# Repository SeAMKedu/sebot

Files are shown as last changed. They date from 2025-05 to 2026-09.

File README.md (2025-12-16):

# SeBot


SeBot-robotin ROS2 ohjelmointiohjeet 28.5.2025 OpenUGV-hankkeen ROS2 mobiilirobotti-työpajaan.

Varsinaiset ohjeet on kirjoitettu markdown-tiedostoihin. Niiden mukaiset valmiit koodit (ROS2, Arduino ja WWW) löydät repositorion code-kansiosta.

SeBotia varten on olemassa Rasberry Pi 5:lle sopiva image-tiedosto, jonka voi kirjoittaa MicroSD-muistikortille. Image sisältää valmiin ROS2 ympäristön ja muut tämän harjoituksen kannalta tarpeelliset muut tiedostot ja ohjelmat. Tiedosto on talletettu OpenUGV-hankkeen Teams-ryhmään (vaatii käyttöoikeuden SeAMK:lta). Mikäli sinulla ei ole käytössä tätä image-tiedostoa tai haluat tehdä harjoituksen jollain muulla koneella, voit hyvin asentaa ROS2-ympäristön itse ``apt install``-komennolla Ubuntun pakettijakelun kautta. Ohje tähän löytyy Materiaali 0:sta.

Jos haluat tulostaa oman SeBot-pohjan, STP-malli ja PDF-mittakuva löytyy SeBot-kansiosta. Huomaa kuitenkin, että tämän harjoituksen kannalta pohjalevyn muoto on hyvin vapaa ja robotin voi rakentaa vaikkapa riittävän tukevaan muovirasiaan.

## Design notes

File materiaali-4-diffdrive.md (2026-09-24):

### Differential drive

Differential Drive on kahdella pyörällä toimiva robotiikan liikkumismekanismi, jossa robottia ohjataan säätämällä pyörien pyörimisnopeuksia. Toinen pyörä voi pyöriä nopeammin, hitaammin tai jopa vastakkaiseen suuntaan kuin toinen, mikä mahdollistaa robotin suunnanmuutokset ja paikoillaan kääntymisen.

Differential Drive on yksinkertainen ja tehokas mekanismi, joka ohjaa robotin liikettä kahden pyörän nopeus- ja suuntaerojen avulla. Se on suosittu ratkaisu erityisesti ROS-järjestelmässä, jossa ``cmd_vel``-topicin avulla määritellään robotin lineaarinen- ja kulmanopeus käyttämällä viestityyppiä ``geometry_msgs/msg/Twist``. Tämä viestityyppi on standardoitu liikkuville roboteille, erityisesti differential drive -järjestelmiä varten.

``geometry_msgs/msg/Twist`` viestityyppi sisältää kaksi vektorikenttää:

- linear: Kuvaa lineaarista nopeutta (m/s) kaikilla kolmella akselilla (x, y, z).
- angular: Kuvaa kulmanopeutta (rad/s) kaikilla kolmella akselilla (x, y, z).

Differential Drive -roboteille merkittävät komponentit ovat:

- linear.x: Lineaarinen nopeus eteenpäin (positiivinen) tai taaksepäin (negatiivinen).
- angular.z: Kulmanopeus robottia ympäröivän pystyakselin ympäri.

Muut komponentit (linear.y, linear.z, angular.x, ja angular.y) eivät yleensä ole käytössä 2D-ympäristössä.

Kun ``cmd_vel`` -topic hallitsee robotin nopeuksia, ``odom`` -topic tarjoaa tietoa robotin todellisesta sijainnista ja orientaatiosta. Odometry-laskenta julkaisee nämä tiedot ``odom`` -topicissa, mikä mahdollistaa robotin sijainnin seuraamisen reaaliaikaisesti.

### Odometry

``/odom``-topic: Tämä julkaisee tietoa robotin sijainnista ja orientaatiosta suhteessa alkuperäiseen lähtöpisteeseen.

Odometriikan laskenta perustuu tässä tapauksessa pelkästään moottoreiden enkoodereiden tuottamaan tietoon. On tärkeää huomioida, että tämä menetelmä ei ole täysin tarkka, sillä renkaiden ja alustan välinen vuorovaikutus, kuten liukuminen ja kitka, aiheuttaa väistämättä virheitä sijainnin ja liikkeen arvioinnissa. Vaikka tämä laskentamenetelmä ei takaa täydellistä tarkkuutta, se tarjoaa kuitenkin luotettavan perustan robotin sijainnin ja liikkeen seuraamiselle. Koska tässä esimerkissä muita antureita ei ole käytössä, enkooderipohjainen odometriikka on robotin ainoa käytettävissä oleva navigointimenetelmä.

#### Odometry-laskennan toiminta lyhyesti

Odometry-laskenta perustuu robotin pyörien liikkeiden mittaamiseen ja näiden tietojen hyödyntämiseen robotin sijainnin ja orientaation (x, y, θ) määrittämiseksi ajan kuluessa.

- Pyörän liikkuma matka saadaan kun tiedetään pyörän halkaisija ja enkooderin lukema yhdeltä kierrokselta.
- Ero vasemman ja oikean pyörän liikkeessä: Lasketaan vasemman ja oikean pyörän kulkema matka.
Pyörien välinen ero määrittää robotin kääntymisen ja suuntamuutoksen.

**Renkaat**

Renkaan säteellä ja renkaiden välisellä etäisyydellä on merkittävä vaikutus differential drive -robotin liikkeeseen ja ohjaukseen. Ne vaikuttavat suoraan robotin liikeradan, nopeuden ja kulmanopeuden laskentaan.

Oheisessa kuvassa havainnollistetaan, miten renkaiden koko ja niiden välinen etäisyys vaikuttavat robotin liikkeeseen, kun toinen rengas liikkuu tietyllä nopeudella ja toinen pysyy paikallaan. Eli esim. ajetaan moottoria 3 s nopeudella 0,1 m/s.

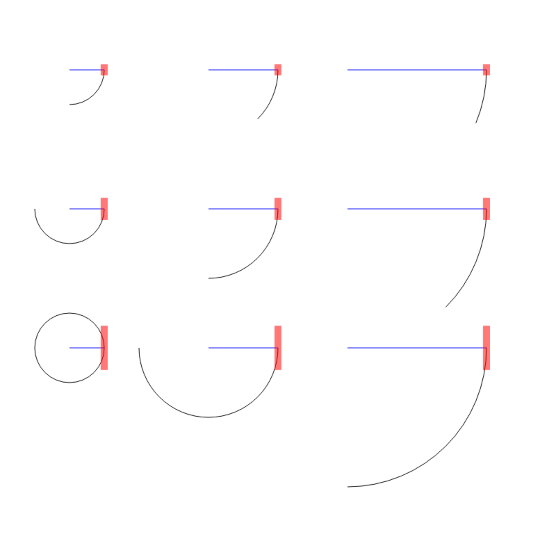
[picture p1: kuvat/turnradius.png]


- Renkaan koko:
	- Pienempi rengas liikkuu lyhyemmän matkan yhdellä kierroksella.
	- Suurempi rengas liikkuu pidemmän matkan samalla kierrosmäärällä.
- Renkaiden välinen etäisyys:
	- Lyhyt etäisyys: Tuottaa jyrkemmän käännöksen, koska kaaren säde pienenee.
	- Pitkä etäisyys: Tekee käännöksestä loivemman, koska suurempi etäisyys vaatii pidemmän matkan kaaren muodostumiseksi.
- Liikuttua matkaa laskettaessa:
	- Kuljettu matka riippuu renkaan koosta ja kääntösäteestä:
		- Pienempi rengas + lyhyt etäisyys → lyhyt matka ja tiukka kaarre.
		- Suurempi rengas + pitkä etäisyys → pitkä matka ja loiva kaarre.

#### Uusi paketti Diffdrive

Luodaan uusi diffdrive-niminen ROS2 paketti ja aletaan työstämään sen sisälle tarvittavat kooditiedostot.

```
cd ~/ros2_ws/src/
ros2 pkg create --build-type ament_python diffdrive
cd ~/ros2_ws/src/diffdrive/diffdrive
```

**Encoder luokka**

Luodaan Pythonilla apuluokka Encoder, joka vastaa enkooderien lukemien hallinnasta ja laskennasta. Useimmissa enkoodereissa lukema nollautuu maksimilukeman jälkeen, jolloin kierrokset alkavat alusta. Tämä luokka pitää tarkasti kirjaa pyörän pyörimiskierroksista, jotta pyörän absoluuttinen sijainti voidaan laskea oikein myös silloin, kun enkooderin lukema ylittyy tai nollautuu.

**~/ros2\_ws/src/diffdrive/diffdrive/encoder.py**

```python
import math

class Encoder():
  encoder_min =  -32768
  encoder_max =  32768
  encoder_range = encoder_max - encoder_min

  encoder_low_wrap = (encoder_range * 0.3) + encoder_min
  encoder_high_wrap = (encoder_range * 0.7) + encoder_min

  def __init__(self, wheel_radius, ticks_per_revolution):

    self.wheel_radius = wheel_radius
    self.ticks_per_revolution = ticks_per_revolution

    # renkaan säde R = 0.1m
    # enkooderin resoluutio E = 1000 tick / kierros

    # renkaan kehä: 2 * pi * R
    # kierrokset per metri = 1m / renkaan kehä
    # ticks per metri = E * (1m / (2 * pi * R)) = E / (2 * pi * R)

    self.ticks_per_meter = self.ticks_per_revolution / (2 * math.pi * self.wheel_radius)

    self.offset = None
    self.encoder = None
    self.prev_encoder = None

    self.position = 0
    self.prev_position = None

    self.multiplier = 0

  def update(self, encoder):
    if self.encoder == None:
      self.offset = encoder
      self.prev_encoder = encoder

    self.encoder = encoder

    # enkoodereissa, jotka mittaavat rotaatiota, on usein rajallinen arvoalue (esim. 0–4095 12-bittisellä enkooderilla).
    # Kun enkooderin arvo "kääntyy ympäri" (esim. 4095 -> 0 tai päinvastoin), tämä logiikka varmistaa, että oikea
    # sijainti säilyy seuraamalla täysiä kierroksia.
    #
    # self.encoder: Nykyinen enkooderin lukema.
    # self.prev_encoder: Edellisen kierroksen enkooderin lukema.
    # self.encoder_low_wrap: Alarajan lähellä oleva kynnysarvo (0 + marginaali)
    # self.encoder_high_wrap: Ylärajan lähellä oleva kynnysarvo (4095 − marginaali)
    # self.multiplier: Laskuri, joka seuraa täysiä kierroksia
    #
    # eli kun edellinen arvo on ylä alueella (esim: 4090-4095) ja nykyinen ala alueella
    # (esim: 0-5) niin silloin absoluuttinen asema lisääntyy ja toiseen suuntaan taas
    # absoluuttinen asema vähenee. Kaikissa muissa tapauksissa ollaan samalla kierroksella

    if (self.encoder < self.encoder_low_wrap) and (self.prev_encoder > self.encoder_high_wrap):
      self.multiplier += 1
    if (self.encoder > self.encoder_high_wrap) and (self.prev_encoder < self.encoder_low_wrap):
      self.multiplier -= 1

    self.position = self.encoder + self.multiplier * self.encoder_range - self.offset

    self.prev_encoder = self.encoder

  def deltam(self):
    if self.prev_position == None:
      self.prev_position = self.position
      return 0
    else:
      d = (self.prev_position - self.position) / self.ticks_per_meter
      self.prev_position = self.position
      return d
```

**Transformaatio**

Transformaatioiden avulla lasketaan robotin sijainti ja orientaatio suhteessa eri koordinaatistoihin. Kun haluamme visualisoida robotin liikkeen RViz-ympäristössä, on tärkeää, että ``odom``- ja ``base_footprint``-kehysten välinen transformaatio on määritetty oikein. Tämä transformaatio yhdistää robotin fyysisen sijainnin (``base_footprint``) sen suhteelliseen sijaintiin odometrian lähtöpisteessä (``odom``).

**RViz Global Options ja Fixed Frame**

Fixed Frame määrittää, minkä koordinaatiston (kehyksen) mukaan kaikki muut kehykset näytetään RViz:ssä.

Jos asetamme Fixed Frame-arvoksi ``base_footprint``:

- Robotin sijainti näytetään suhteessa itseensä, mikä tarkoittaa, ettei mitään liikettä visualisoida, vaikka robotti liikkuisi.
- Tämä johtuu siitä, että base_footprint pysyy aina robotin rungossa ja seuraa sitä.

Jos asetamme Fixed Frame-arvoksi ``odom``:

- Robotin liike visualisoidaan suhteessa ``odom``-kehykseen, joka toimii odometrian lähtöpisteenä.
- Tämä mahdollistaa robotin todellisen liikkeen seuraamisen ruudulla.

**Miten transformaatio vaikuttaa?**

Kun robotti liikkuu, ``odom``-kehys pysyy paikallaan, ja ``base_footprint`` siirtyy sen suhteen. ``odom`` -> ``base_footprint``-transformaatio päivitetään jatkuvasti, ja RViz käyttää tätä tietoa piirtääkseen robotin sijainnin ja orientaation.

Transformaatioiden laskennan ja julkaisun sijainti riippuu robotin järjestelmän arkkitehtuurista sekä vaaditun paikannuksen tarkkuudesta ja mahdollisesta integraatiosta muiden sensoreiden, kuten IMU:n tai LiDAR:n kanssa.

Transformaatiot voidaan toteuttaa suoraan ``odom``-nodessa, jos odometria toimii järjestelmän ainoana sijaintilähteenä. Tämä lähestymistapa on erityisen sopiva yksinkertaisille järjestelmille, joissa ei ole käytössä muita antureita.

Jos kuitenkin käytössä on useita sensoreita, on suositeltavaa käyttää ROS2:n yleisesti käytettyihin paketteihin kuuluvan ´´robot_localizationin´´ EKF (Extended Kalman Filter) -nodea. EKF yhdistää kaikki saatavilla olevat tiedot, kuten enkooderit, IMU:n, LiDAR:n ja GPS:n, ja tuottaa tarkemman arvion robotin sijainnista ja orientaatiosta. Tämä parantaa paikannustarkkuutta ja kompensoi yksittäisten sensorien mahdollisia virheitä.

**Tilanne IMU:n (Inertial Measurement Unit) kanssa:**

IMU tuo tarkempaa dataa robotin todellisesta liikkeestä, mikä auttaa kompensoimaan pyöräluiston aiheuttamaa virhettä.

Kulmanopeus (Yaw-Rate): 
IMU:n gyroskooppi mittaa kulmanopeuksia (esim. kääntymistä z-akselin ympäri).
Jos toinen pyörä luistaa ja pyöräenkooderit antavat väärää kulmanopeustietoa, IMU voi tunnistaa todellisen kulmanopeuden ja korjata suunta- ja sijaintitiedot.
Tämä estää vääristymän kertyessä robotin orientaatioon (yaw).

Kiihtyvyys (Linear Acceleration)
IMU:n kiihtyvyysanturit mittaavat robotin liikkeen kiihtyvyyttä x- ja y-suunnassa.
Pyöräluiston aikana enkooderien arvioima lineaarinen liike voi olla väärä, mutta IMU voi tunnistaa todellisen kiihtyvyyden ja auttaa arvioimaan todellista nopeutta.
Tämä vähentää virhettä robotin paikannuksessa.

**Tilanne LiDAR:n (Light Detection and Ranging) kanssa:**

LiDAR täydentää pyöräenkoodereiden rajoituksia tuottamalla tarkkaa tietoa robotin ympäristöstä.

Etäisyyksien mittaus: LiDAR kartoittaa ympäristöä mittaamalla etäisyyksiä robotin ympärillä oleviin esteisiin ja rakenteisiin.

Staattiset viitteet: LiDAR voi tunnistaa pysyviä ympäristön piirteitä, kuten seinät ja huonekalut, joita käytetään robotin sijainnin määrittämiseen suhteessa ympäristöön.

**Driftin korjaaminen**

Absoluuttista paikkaa tarjoavia paikannusmenetelmiä (kuten kamera- tai LiDAR-pohjainen SLAM, GNSS-paikannus, UWB-paikannus) hyödyntämällä voidaan havaita robotin todellisen liikkeen suhteessa ympäristöön ja korjata pyöräenkooderien kertyneen virheen. 

Esimerkiksi, jos pyöräenkooderit osoittavat, että robotti on siirtynyt tiettyyn kohtaan, mutta LiDAR:n havainto ympäristöstä kertoo muuta, paikannus voidaan korjata yhdistämällä tiedot. ROS2:n tapauksessa yleinen tapa tehdä tällaista korjausta on syöttää eri paikannusmenetelmien tietovirrat ``robot_localization``-paketin EKF-suodattimelle.

Nyt kun enkooderit ovat ainoa sijaintilähteemme, toteutamme transformaatioiden julkaisemisen suoraan ``odom``-nodessa joka on yksinkertainen ja tehokas ratkaisu.

**~/ros2\_ws/src/diffdrive/diffdrive/odom.py**

```python
import rclpy
from rclpy.node import Node

from nav_msgs.msg import Odometry
from tf_transformations import quaternion_from_euler

from geometry_msgs.msg import TransformStamped
from tf2_ros import TransformBroadcaster

from motordriver_msgs.msg import MotordriverMessage

import math

try:
    from .encoder import Encoder
except:
    from encoder import Encoder

class OdomNode(Node):
  def __init__(self):
    super().__init__('odom_node')

    # Lue parametrit
    self.declare_parameter('wheel_radius', 0.1)
    self.declare_parameter('wheel_base', 0.5)
    self.declare_parameter('ticks_per_revolution', 1075)

    # Hae parametrien arvot
    self.wheel_radius = self.get_parameter('wheel_radius').value
    self.wheel_base = self.get_parameter('wheel_base').value
    self.ticks_per_revolution = self.get_parameter('ticks_per_revolution').value

    self.get_logger().info(f'Pyörän säde: {self.wheel_radius}')
    self.get_logger().info(f'Pyörien etäisyys: {self.wheel_base}')
    self.get_logger().info(f'Anturin kierros: {self.ticks_per_revolution}')

    ## Otetaan framelle etuliite parametrinä tai jos parametriä ei syötetä, otetaan se namespace-tiedosta.
    #self.declare_parameter('frame_prefix', '')
    #frame_prefix_param = self.get_parameter('frame_prefix').get_parameter_value().string_value
    #if frame_prefix_param:
    #    self.frame_prefix = frame_prefix_param + '_'
    #else:
    #    ns = self.get_namespace().strip('/')
    #    self.frame_prefix = f'{ns}_' if ns and ns != '' else ''

    #if self.frame_prefix:
    #        self.get_logger().info(f'Käytetään frame-etuliitettä: "{self.frame_prefix}"') 

    self.left_encoder = Encoder(self.wheel_radius, self.ticks_per_revolution)
    self.right_encoder = Encoder(self.wheel_radius, self.ticks_per_revolution)

    self.odom_theta = 0.0
    self.odom_x = 0.0
    self.odom_y = 0.0

    self.motor_subscriber = self.create_subscription(
        MotordriverMessage,
        'motor_data',
        self.update_encoders_callback,
        10
    )

    self.odom_publisher = self.create_publisher(
        Odometry,
        'odom',
        10
    )

    # TransformBroadcaster tarvitsee viitteen pääluokkaan saadakseen tarvittavan kontekstin
    # (noden  asetukset tai muun jaetun datan). Tämä tapahtuu antamalla self parametrina.
    self.tf_broadcaster = TransformBroadcaster(self)

    self.prev_time = self.get_clock().now().nanoseconds

    timer_period = 0.1 # Sekuntia
    self.timer = self.create_timer(timer_period, self.timer_callback)
    self.update = True

  def update_encoders_callback(self, message):
    # Tallennetaan messagessa olevat tiedot, jotta niitä voidaan käsitellä timer_callback:ssa
    self.left_encoder.update(message.encoder1)
    self.right_encoder.update(-message.encoder2)
    self.update = True

  def timer_callback(self):
    if not self.update: return
    self.update = False
    current_time = self.get_clock().now().nanoseconds
    elapsed = (current_time - self.prev_time)/1000000000
    self.prev_time = current_time

    d_left= self.left_encoder.deltam()
    d_right = self.right_encoder.deltam()

    # Kuljettu matka (delta_distance) lasketaan ottamalla vasemman ja oikean pyörän kulkema matka
    # jaettuna kahdella. Robotin liikkuma matka suoraviivaisesti keskilinjan (robottia keskeltä
    # halkova akseli) pitkin.
    # Kulman muutos (delta_theta) lasketaan ottamalla vasemman ja oikean pyörän kulkeman matkan erotus ja
    # jakamalla se pyörien välisellä etäisyydellä
    # Jos pyörät liikkuvat yhtä paljon samaan suuntaan (𝑑_left=𝑑_right -> delta_theta=0), robotti liikkuu
    # suoraan eteen- tai taaksepäin.
    # Jos pyörät liikkuvat yhtä paljon erisuuntiin (𝑑_left=-𝑑_right -> delta_distance=0), robotti pyörii
    # paikallaan
    delta_distance = (d_left + d_right) / 2.0
    delta_theta = (d_left - d_right) / self.wheel_base

    if delta_distance != 0:
      robot_x = math.cos( delta_theta ) * delta_distance
      robot_y = -math.sin( delta_theta ) * delta_distance
      self.odom_x = self.odom_x + ( math.cos( self.odom_theta ) * robot_x - math.sin( self.odom_theta ) * robot_y )
      self.odom_y = self.odom_y + ( math.sin( self.odom_theta ) * robot_x + math.cos( self.odom_theta ) * robot_y )

    linear_y = delta_distance * math.cos(self.odom_theta) / elapsed
    linear_x = delta_distance * math.sin(self.odom_theta) / elapsed
    angular_z = delta_theta / elapsed

    self.odom_theta = delta_theta + self.odom_theta

    odom_msg = Odometry()
    odom_msg.header.stamp = self.get_clock().now().to_msg()
    #odom_msg.header.frame_id = self.frame_prefix + 'odom' # Lisätään framen nimen eteen namespacen (tai parametrin) mukainen etuliite.
    #odom_msg.child_frame_id = self.frame_prefix + 'base_footprint'
    odom_msg.header.frame_id = 'odom'
    odom_msg.child_frame_id = 'base_footprint'

    # pose sisältää kaksi osaa:
    # position (geometry_msgs/Point)
    #  x, y, z: Robotin sijainti koordinaatistossa.
    # orientation (geometry_msgs/Quaternion)
    #  x, y, z, w: Robotin orientaatio quaternion-muodossa (3D-rotaatio).
    odom_msg.pose.pose.position.x = self.odom_x ##
    odom_msg.pose.pose.position.y = self.odom_y ##
    odom_msg.pose.pose.position.z = 0.0

    quat = quaternion_from_euler(0.0, 0.0, self.odom_theta)
    odom_msg.pose.pose.orientation.x = quat[0] ##
    odom_msg.pose.pose.orientation.y = quat[1] ##
    odom_msg.pose.pose.orientation.z = quat[2] ##
    odom_msg.pose.pose.orientation.w = quat[3] ##

    # Nopeudet (valinnainen, ei käytössä tässä sovelluksessa)
    odom_msg.twist.twist.linear.x = linear_x
    odom_msg.twist.twist.linear.y = linear_y
    odom_msg.twist.twist.angular.z = angular_z

    # Julkaistaan odometry viesti
    self.odom_publisher.publish(odom_msg) ##

    t = TransformStamped()
    t.header.stamp = self.get_clock().now().to_msg()
    #t.header.frame_id = self.frame_prefix + 'odom'
    #t.child_frame_id = self.frame_prefix + 'base_footprint'
    t.header.frame_id = 'odom'
    t.child_frame_id = 'base_footprint'

    t.transform.translation.x = self.odom_x ##
    t.transform.translation.y = self.odom_y ##
    t.transform.translation.z = 0.0

    # z: Quaternionin osa, joka liittyy rotaatioon  z-akselin suuntaan. Tämä ei yksinään ole kulma,
    # vaan osa rotaation akselin ja kulman yhteistä esitystä.
    # w: Quaternionin skaalarikomponentti, joka määrittää, kuinka suuri osa rotaatiosta tulee akselin
    # ympäriltä. Suhteessa muihin quaternion-komponentteihin, tämä määrittää kulman.

    t.transform.rotation.z = math.sin(self.odom_theta / 2.0) ##
    t.transform.rotation.w = math.cos(self.odom_theta / 2.0) ##

    # Julkaistaan transformaatio
    self.tf_broadcaster.sendTransform(t) ##

def main(args=None):
  rclpy.init(args=args)

  odom_node = OdomNode()

  try:
    rclpy.spin(odom_node)
  except KeyboardInterrupt:
    pass
  finally:
    odom_node.destroy_node()
    if rclpy.ok():
      rclpy.shutdown()

if __name__ == '__main__':
  main()
```

Nyt voimme testata ohjelman toimintaa. Suorita seuraavat komennot eri terminaaleissa ja varmista, että kaikki tarvittavat nodet ovat käynnissä. Jos seuraat robottiasi RViz:ssa ja asetat Fixed Frame -asetukseksi ``[SeBot_namespace]`` ``/odom``, robotin pitäisi liikkua visualisointinäkymässä odotetusti.

```bash
# Käynnistä motordriver node (muista source)
ros2 run motordriver motordriver 
#ros2 run motordriver motordriver [--ros-args -r __ns:=/[SeBot_namespace]]

# Testataan odom -nodea
python3 odom.py
#python3 odom.py --ros-args -r __ns:=/[SeBot_namespace]

# Tulostetaan mitä /odom -topic näyttää
ros2 topic echo /odom
#ros2 topic echo /[SeBot_namespace]/odom

# Aja eteenpäin
ros2 topic pub /motor_command std_msgs/String "{data: 'SPD;100;-100;'}"
#ros2 topic pub /[SeBot_namespace]/motor_command std_msgs/String "{data: 'SPD;100;-100;'}"

# Aja taaksepäin
ros2 topic pub /motor_command std_msgs/String "{data: 'SPD;-100;100;'}"

# Pyöri paikallaan
ros2 topic pub /motor_command std_msgs/String "{data: 'SPD;100;100;'}"

# Aja ympyrää
ros2 topic pub /motor_command std_msgs/String "{data: 'SPD;150;-100;'}"
```

Kun sekä ``odom`` että ``transformaatio`` toimivat oikein, voit visualisoida nämä RVizissä, jolloin punainen Odometry-nuoli ja robotin malli osoittavat samaan suuntaan ja sijaitsevat kohdakkain.
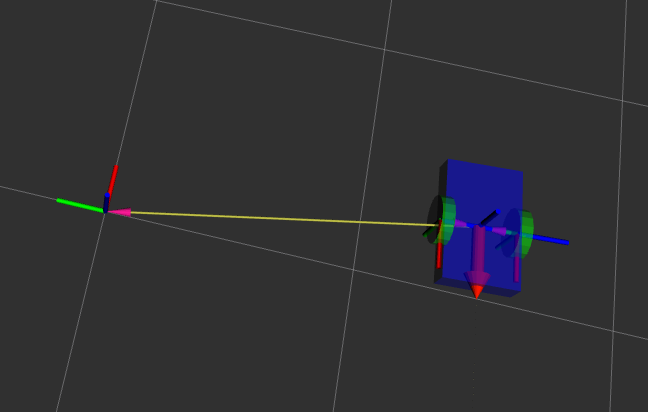
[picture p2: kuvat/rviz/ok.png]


Koodissa on rivejä joiden perässä on ``##`` kommentoimalla näitä rivejä pois eri tavalla ja käynnistämällä ohjelman uudelleen voidaan nähdä miten nämä vaikuttavat odometryn ja transformaation toimintaan.

Julktaistaan pelkkä /odom topic, transformaatio on viimeisessä paikassa johon julkaistu
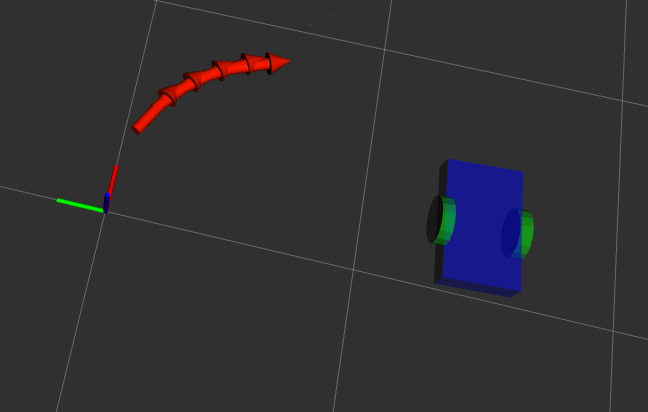
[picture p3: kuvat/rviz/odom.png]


/odom topicissa vain rotaatio
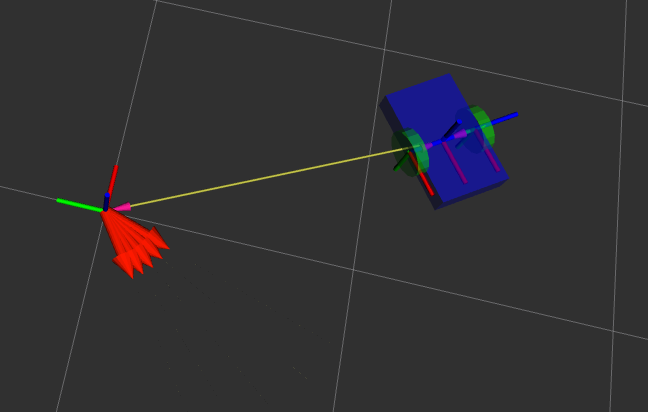
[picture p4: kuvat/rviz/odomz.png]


/odom topicissa vain paikka
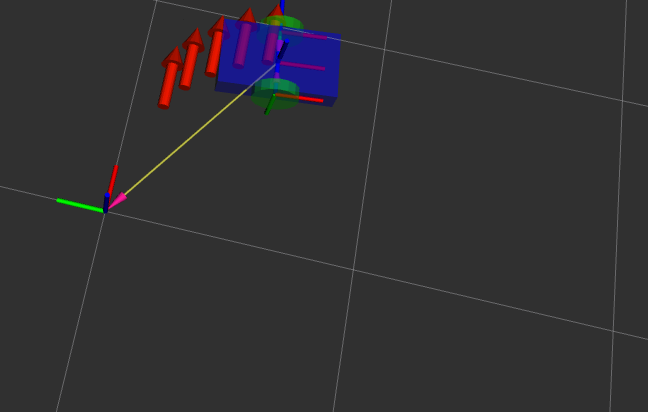
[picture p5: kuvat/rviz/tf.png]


transformaatiosta vain paikka
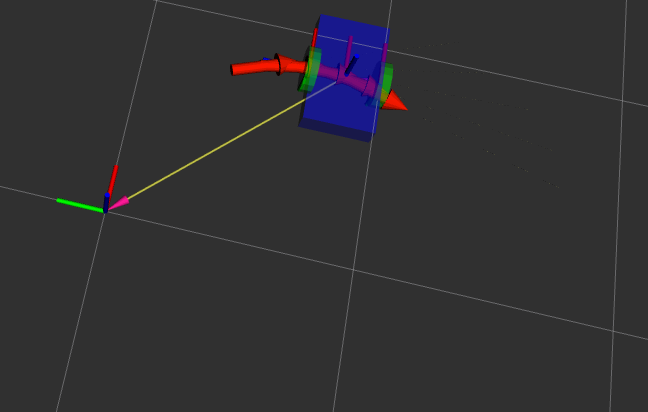
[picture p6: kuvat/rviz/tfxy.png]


transformaatiosta vain rotaatio
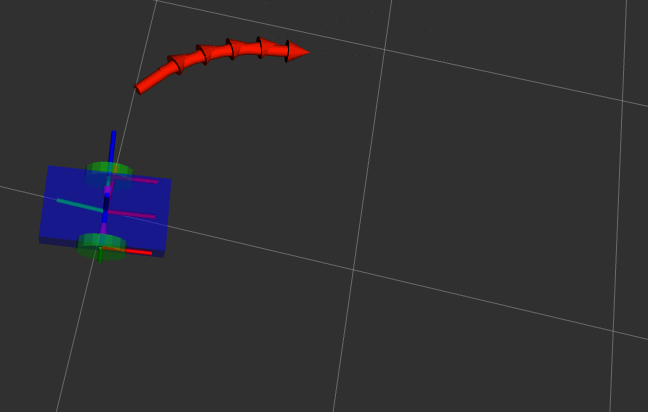
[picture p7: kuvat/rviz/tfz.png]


Kun julkaiset transformaatioiden ketjun ``odom`` -> ``base_footprint``, se ilmestyy TF-tree-rakenteeseen, joka kuvaa kaikkien TF-kehysten välisiä suhteita. Tämä on olennainen osa robotin sijainnin seuraamista suhteessa paikalliseen odom-kehykseen.

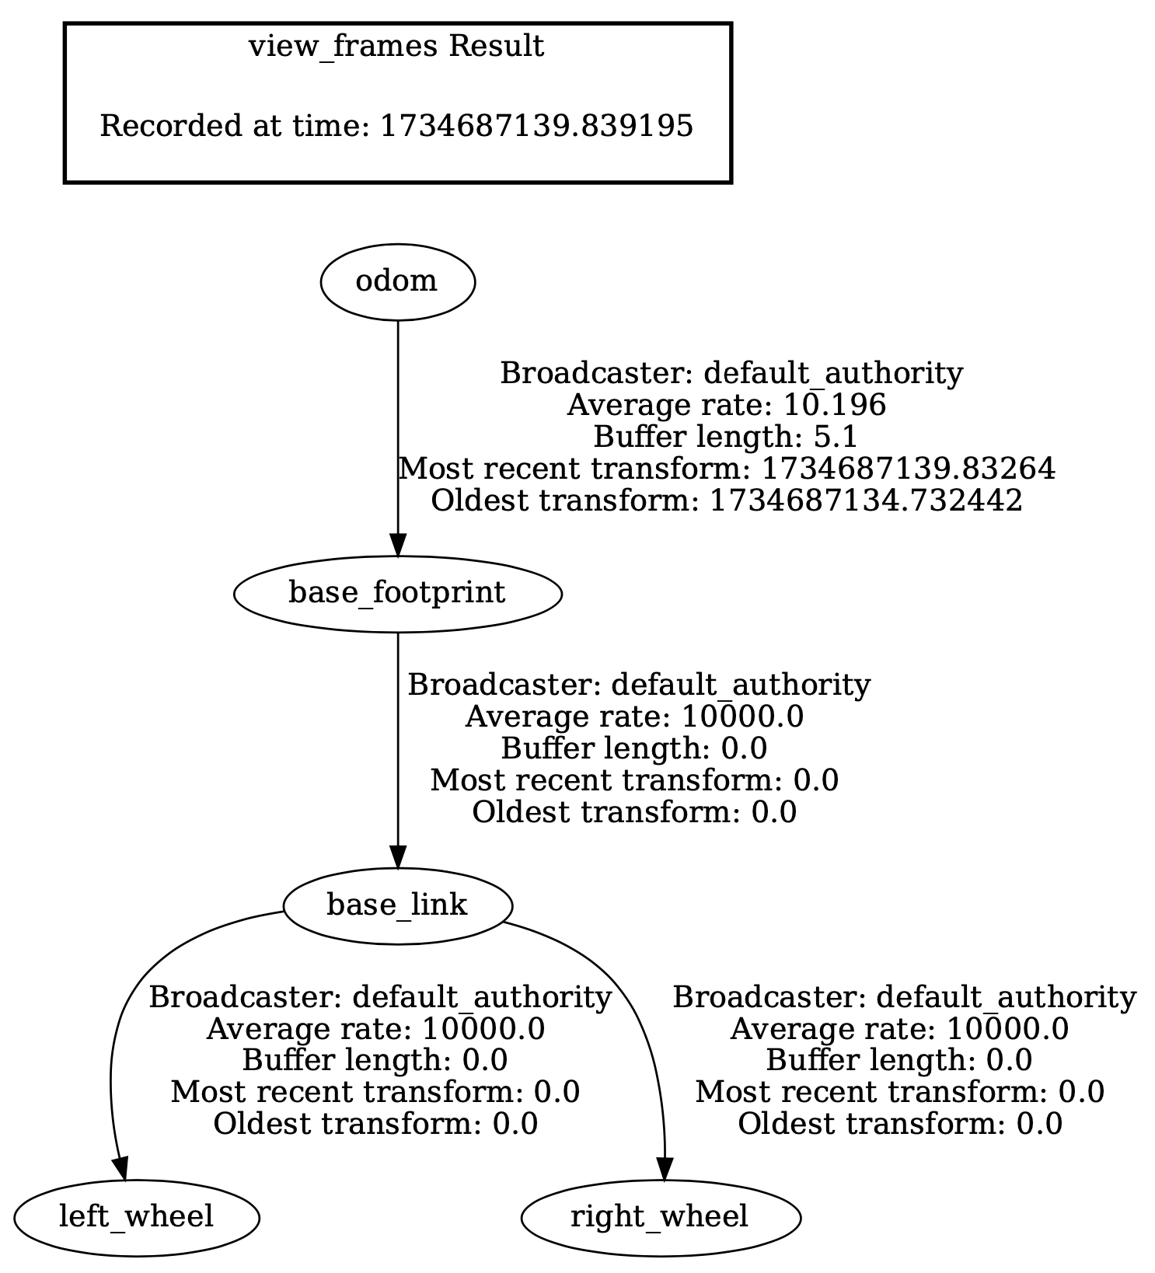
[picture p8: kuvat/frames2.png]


Kun siirrytään kohti autonomista ajoa, TF-treehen lisätään myös ``map``-kehys. Tämä muodostaa transformaatioiden ketjun ``map`` -> ``odom`` -> ``base_footprint``, jolloin robotin sijaintia voidaan seurata tarkasti sekä kartalla että paikallisessa koordinaatistossa. Tämä mahdollistaa robotin etenemisen tarkastelun sekä paikallisesti että globaalisti. Jos tätä harjoitusta tehdään monen SeBotin kanssa samassa ``ROS_DOMAIN_ID``:ssä, on tarpeen luoda hieman keinotekoinen ``map``-kehys. Tästä esitetään mallin tuonnempana ``launch``-tiedoston yhteydessä.

### Twist

Seuraavaksi siirrymme käsittelemään ``cmd_vel`` -topicia. Sen avulla voimme ohjata robottia yksinkertaisemmin määrittämällä suoraan lineaarisen nopeuden ja kulmanopeuden. Tämä lähestymistapa poistaa tarpeen ohjata moottoreita erikseen ja tekee liikkeiden hallinnasta intuitiivisempaa.

``cmd_vel``-topicin käyttö yhdessä Nav2-järjestelmän kanssa mahdollistaa robotin autonomisen ajon. Nav2 ohjaa robottia lähettämällä lineaarisen nopeuden ja kulmanopeuden komentoja ``cmd_vel`` -topiciin, jolloin robotti voi navigoida itsenäisesti määritetyn kartan ja reitin perusteella.

Käytännössä ``cmd_vel``-node muuntaa lineaarisen nopeuden ``linear.x`` ja kulmanopeuden ``angular.z`` pyöräkohtaisiksi nopeus ohjeiksi, joita ``motor_command ``-topic ymmärtää: ``SPD;vel_l;vel_r;``

**~/ros2\_ws/src/diffdrive/diffdrive/cmd_vel.py**

```python
import rclpy
from rclpy.node import Node

from geometry_msgs.msg import Twist
from std_msgs.msg import String

import math

class CmdVelNode(Node):
  def __init__(self):
    super().__init__('cmd_vel_node')

    # Lue parametrit
    self.declare_parameter('wheel_radius', 0.1)
    self.declare_parameter('wheel_base', 0.5)
    self.declare_parameter('ticks_per_revolution', 1075)

    # Hae parametrien arvot
    self.wheel_radius = self.get_parameter('wheel_radius').value
    self.wheel_base = self.get_parameter('wheel_base').value
    self.ticks_per_revolution = self.get_parameter('ticks_per_revolution').value

    self.get_logger().info(f'Pyörän säde: {self.wheel_radius}')
    self.get_logger().info(f'Pyörien etäisyys: {self.wheel_base}')
    self.get_logger().info(f'Anturin kierros: {self.ticks_per_revolution}')

    self.cmd_vel_subscriber = self.create_subscription(
        Twist,
        'cmd_vel',
        self.cmd_vel_callback,
        10
    )

    self.mc_publisher = self.create_publisher(
        String,
        'motor_command',
        10
    )

  def mps_to_spd(self,mps):
    # muunnetan m/s moottoriohjaimen spd arvoksi
    pid_freq = 10 # Moottoriohjain päivittyy 10Hz taajuudella

    # kulmanopeus (rad/s)
    radps = mps / self.wheel_radius

    # RPM
    rpm = radps * ( 60 / ( 2 * math.pi ) )

    spd = rpm * (self.ticks_per_revolution / 60 / pid_freq)
    return spd

  def cmd_vel_callback(self, msg):
    # mps_l = vasen rengas m/s
    # mps_r = oikea rengas m/s
    mps_l = +(msg.linear.x + (msg.angular.z * self.wheel_base / 2.0))
    mps_r = -(msg.linear.x - (msg.angular.z * self.wheel_base / 2.0))

    string_msg = String()
    string_msg.data = "SPD;%i;%i;"%(self.mps_to_spd(mps_l), self.mps_to_spd(mps_r))

    self.mc_publisher.publish(string_msg)

def main(args=None):
  rclpy.init(args=args)

  cmdvel_node = CmdVelNode()

  try:
    rclpy.spin(cmdvel_node)
  except KeyboardInterrupt:
    pass
  finally:
    cmdvel_node.destroy_node()
    if rclpy.ok():
      rclpy.shutdown()

if __name__ == '__main__':
  main()
```

Nyt on aika kokeilla ohjelmaa. Pidä ``motordriver``- ja ``odom``-nodet sekä RViz käynnissä. Tällä kertaa lähetä viestit ``cmd_vel``-topiciin sen sijaan, että käyttäisit suoraan ``motor_command``-topiceja. Näin voit testata robotin ohjausta nopeuden ja kulmanopeuden avulla.

```bash
# Käynnistetään cmd_vel node
python3 cmd_vel.py

# Robotti liikkuu eteenpäin 0.5 m/s:
ros2 topic pub /cmd_vel geometry_msgs/Twist "{linear: {x: 0.5, y: 0.0, z: 0.0},	angular: {x: 0.0, y: 0.0, z: 0.0}}"
# Sama huomioiden namespace:
ros2 topic pub /[SeBot_namespace]/cmd_vel geometry_msgs/Twist "{linear: {x: 0.5, y: 0.0, z: 0.0}, angular: {x: 0.0, y: 0.0, z: 0.0}}"

# Robotti kääntyy vastapäivään paikallaan (kulmanopeus 1 rad/s):
ros2 topic pub /cmd_vel geometry_msgs/Twist "{linear: {x: 0.0, y: 0.0, z: 0.0}, angular: {x: 0.0, y: 0.0, z: 1.0}}"

# Robotti liikkuu kaarella myötäpäivään (eteenpäin + käännös):
ros2 topic pub /cmd_vel geometry_msgs/Twist "{linear: {x: 0.3, y: 0.0, z: 0.0}, angular: {x: 0.0, y: 0.0, z: -0.5}}"
```
### Lisätehtävä: Teleop_twist_keyboard
Robotin ajaminen yksittäisillä komentorivikehotteilla on työlästä. Varsinaisesti ideana on toki se, että robotin ohjauskokonaisuus antaa näitä komentoja enemmän tai vähemmän itsenäisesti ("autonominen ajaminen"), mutta tämän harjoituksen puitteissa hyvä väliaskel on ottaa käyttöön jokin manuaalisen etäohjaamisen mahdollistava ROS2 paketti. Helpointa on kokeilla ohjausta näppäimistöllä, minkä mahdollistaa [teleop_twist_keyboard](https://index.ros.org/r/teleop_twist_keyboard/).
```bash
sudo apt install ros-jazzy-teleop-twist-keyboard
ros2 run teleop_twist_keyboard teleop_twist_keyboard

#ros2 run teleop_twist_keyboard teleop_twist_keyboard.py --ros-args -r /cmd_vel:=/[SeBot_namespace]/cmd_vel # Jos käytössä on namespace

```

``teleop_twist_keyboard`` voidaan ohjata julkaisemaan twist-viestejä myös johonkin muuhun topiciin parametrillä ``--ros-args --remap cmd_vel:=[joku_muu_topic]``. Jos harjoituksessa on mukana vain yksi SeBot tai kukin toimii omassa ``ROS_DOMAIN_ID``:ssä, käytämme oletuksena ``/cmd_vel``-topicia, eikä topicia pitäisi olla tarpeen säätää, sillä ``/cmd_vel`` on yleisesti käytetty standardi ROS 2:ssa.

Mikäli haluat ohjata robottia peliohjaimella, kannattaa tutustua ``[teleop_twist_joy](https://index.ros.org/r/teleop_twist_joy/#jazzy)``-pakettiin. Tämä asennetaan ja ajetaan komennoilla
```bash
apt install ros-jazzy-teleop-twist-joy
ros2 launch teleop_twist_joy teleop-launch.py joy_config:='[valitse ohjaimen konfiguraatio, esimerkiksi 'xbox']'
```
> Huomaa, että teleop_twist_joy käynnistetään ``launch``, ei ``run`` komennolla. Lisäksi sinun tulee varmistua siitä, että konfiguraatio vastaa yhdistettyä ohjainta. Vaihtoehtoja löytyy osoitteesta [https://github.com/ros2/teleop_twist_joy/tree/rolling/config](https://github.com/ros2/teleop_twist_joy/tree/rolling/config).

### PWM- ja PID-säädön vertailu
Jos haluamme vertailla robotin toimintaa PWM-säädön ja PID-säädetyn nopeuden välillä, voimme yksinkertaisesti vaihtaa yhden koodirivin, joka määrittää säätötyypin.

```python
string_msg.data = "SPD;%i;%i;"%(vel_l,vel_r)
```

muotoon

```python
string_msg.data = "PWM;%i;%i;"%(vel_l,vel_r)
#(vel_l ja vel_r saattavat vaatia pienet kertoimet,
#jos moottorit eivät pyöri lainkaan pienillä arvoilla
#tai vaihtoehtoisest topicin x ja z arvoihin vain isompia lukuja)
```

Kaikki kunnossa, päivitetään ``setup.py`` ja käännetään paketti osaksi järjestelmää:

**~/ros2\_ws/src/diffdrive/setup.py**

```python
from setuptools import find_packages, setup
import os
from glob import glob

package_name = 'diffdrive'

setup(
    name=package_name,
    version='0.0.0',
    packages=find_packages(exclude=['test']),
    data_files=[
        ('share/ament_index/resource_index/packages',
            ['resource/' + package_name]),
        ('share/' + package_name, ['package.xml']),
        (os.path.join('share', package_name), glob('config/*')),
        (os.path.join('share', package_name, 'launch'), glob(os.path.join('launch', '*launch.[pxy][yma]*'))),

    ],
    install_requires=['setuptools'],
    zip_safe=True,
    maintainer='ros2',
    maintainer_email='ros2@todo.todo',
    description='TODO: Package description',
    license='TODO: License declaration',
    tests_require=['pytest'],
    entry_points={
        'console_scripts': [
            'odom = diffdrive.odom:main',
            'cmd_vel = diffdrive.cmd_vel:main',
        ],
    },
)
```

```bash
cd ~/ros2_ws
colcon build --packages-select diffdrive

# Testataan toiminta
ros2 run diffdrive odom
ros2 run diffdrive cmd_vel
#ros2 run diffdrive odom --ros-args -r __ns:=/[SeBot_namespace]
#ros2 run diffdrive cmd_vel --ros-args -r __ns:=/[SeBot_namespace]

# odom.py ja cmd_vel.py tiedostot sisältävät kohdat joissa skriptin muuttujille haetaan arvot käynnistysparametreinä. Nämä parametrit voi syöttää käynnistysvaiheessa myös ulkoisesta tiedostosta.

# Tässä esimerkki, jossa haetaan parametrit ~/ros2_ws/config/params.yaml tiedostosta. Alempana luodaan tähän tiedostoon tarvittava sisältö.
ros2 run diffdrive odom --ros-args --params-file ~/ros2_ws/config/params.yaml
```

### Launch -tiedostot

ROS 2:ssa launch-tiedostot mahdollistavat yhden tai useamman noden käynnistämisen samanaikaisesti. Päivitämme aiemmin luomamme launch-tiedoston, joka käynnisti URDF-noden, lisäämällä siihen myös tekemämme ``odom`` - ja ``cmd_vel`` -nodet, jotta kaikki tarvittavat toiminnot voidaan käynnistää yhdellä komennolla.

**~/ros2\_ws/src/diffdrive/launch/diffdrive.launch.py**

```python
import os
from ament_index_python.packages import get_package_share_directory
from launch import LaunchDescription
from launch.actions import DeclareLaunchArgument
from launch.substitutions import LaunchConfiguration
from launch_ros.actions import Node

def generate_launch_description():
    # NAMESPACE = 'SeBotxx' # korvaa xx oman Sebotin tunnisteella, esimerkiksi IP-osoitteen viimeisellä tavulla.
    # FRAME_PREFIX = NAMESPACE+"_" # luodaan robot_state_publisherin tukeman frame_prefix-parametrin arvo

    use_sim_time = LaunchConfiguration('use_sim_time', default='false')

    colcon_prefix_path = os.getenv('COLCON_PREFIX_PATH').split("/install")[0]

    urdf_file_name = 'robot.urdf'
    urdf = os.path.join(
        colcon_prefix_path,
        'config',
        urdf_file_name)
    with open(urdf, 'r') as infp:
        robot_desc = infp.read()

    return LaunchDescription([
        DeclareLaunchArgument(
            'use_sim_time',
            default_value='false',
            description='Use simulation (Gazebo) clock if true'),
            
        Node(
            package='robot_state_publisher',
            executable='robot_state_publisher',
            name='robot_state_publisher',
            output='screen',
            #namespace = NAMESPACE,
            #parameters=[{'use_sim_time': use_sim_time, 'robot_description': robot_desc, 'frame_prefix': FRAME_PREFIX}],
            parameters=[{'use_sim_time': use_sim_time, 'robot_description': robot_desc}],
            #arguments=[urdf] # 26.5.2025 tämä on tarpeeton rivi, sillä robot_state_publisher ei parsi komentokehotteen argumentteja.
            ),

        Node(
            package='tf2_web_republisher_py',
            executable='tf2_web_republisher',
            name='tf2_web_republisher',
            #namespace = NAMESPACE,
            output='screen',
          ),

        Node(
            package='motordriver',
            executable='motordriver',
            name='motordriver_node',
            #namespace = NAMESPACE,
            output='screen',
            parameters=[os.path.join(
              colcon_prefix_path,
              'config',
              'params.yaml')]
          ),
        Node(
            package='diffdrive',
            executable='odom',
            name='odom_node',
            #namespace = NAMESPACE,
            output='screen',
            parameters=[os.path.join(
              colcon_prefix_path,
              'config',
              'params.yaml')]
          ),
        Node(
            package='diffdrive',
            executable='cmd_vel',
            name='cmd_vel_node',
            #namespace = NAMESPACE,
            output='screen',
            parameters=[os.path.join(
              colcon_prefix_path,
              'config',
              'params.yaml')]

          ),
        
        ## Lisätään muunnos map->[namespace]_odom jotta kaikki robotit saadaan mukaan samaan TF-puuhun. 
        #Node(
        #    package='tf2_ros',
        #    executable='static_transform_publisher',
        #    name='map_to_robot_odom',
        #    namespace=NAMESPACE,
        #    arguments=['0', '0', '0', '0', '0', '0',  # x y z yaw pitch roll
        #               'map', f'{FRAME_PREFIX}odom'],
        #    output='screen'
        #),
    ])
```

``odom.py`` ja ``cmd_vel.py`` tiedostot sisälsivät rivejä kuten esim:

```python
    self.wheel_radius = self.get_parameter('wheel_radius').value
```

launch tiedostossa määrittelimme nyt ``parameters=["~ros2_ws/config/params.yaml"]`` joka tarkoittaa, että voimme sinne asetella parametrejä, joita voimme päivittää ilman, että tarvitsee kääntää järjestemää, riittää vain noden uudelleen käynnistys.

**~/ros2\_ws/config/params.yaml**

```yaml
motordriver_node:
  ros__parameters:
    simulation: False
odom_node:
  ros__parameters:
    wheel_radius: 0.2
    wheel_base: 0.6
    ticks_per_revolution: 1000
cmd_vel_node:
  ros__parameters:
    wheel_radius: 0.3
    wheel_base: 0.7
```

##### Käännetään (rakennetaan ympäristö)
```bash
cd ~/ros2_ws
colcon build --packages-select diffdrive
```

##### Source
```bash
source ~/ros2_ws/install/setup.bash
```

##### Käynnistetään
```bash
ros2 launch diffdrive diffdrive.launch.py
```

##### Testataan (toisessa päätteessä)
```bash
ros2 topic pub /motor_command std_msgs/String "{data: 'SPD;100;100;'}"
```

### Automaattinen käynnistyminen robotin käynnistyessä

Jotta ROS2-paketti voidaan käynnistää automaattisesti järjestelmän käynnistyessä, voit käyttää systemd-palvelua Linux-järjestelmissä. ROS2-paketit vaativat ympäristön lataamisen, mikä tarkoittaa, että ROS2:n jakeluversion (``/opt/ros/jazzy/setup.bash``) ja työtilan (``install/setup.bash``) asetuskomennot täytyy suorittaa automaattisesti ennen noden tai launch-tiedoston käynnistämistä.

Luodaan bash scripti jonka systemd service käy käynnistämässä:

**/home/ros2/ros2\_ws/autostart.sh**

```bash
#!/bin/bash

# Lataa ROS2-ympäristö
source /opt/ros/jazzy/setup.bash

# Lataa työtilan ympäristö
source /home/ros2/ros2_ws/install/setup.bash

# Suorita launch-tiedosto
ros2 launch diffdrive diffdrive.launch.py
```

Luodaan .service tiedosto jota hallitaan systemctl komennolla. Huom, muokkaaminen pitää tapahtua sudo:na 

```bash
sudo nano /etc/systemd/system/ros2_motordriver.service
```

**/etc/systemd/system/ros2\_motordriver.service**

```bash
[Unit]
Description="ROS2 Motor Driver Autostart"
After=network.target

[Service]
Type=simple
User=ros2
ExecStart=/home/ros2/ros2_ws/autostart.sh
Restart=always

Environment="PYTHONUNBUFFERED=1"
#tarkoittaa, että Python suoritetaan ilman tulosteen puskurointia (unbuffered mode).
#Tämä vaikuttaa erityisesti stdout- ja stderr-virtoihin (eli tulosteisiin ja virheilmoituksiin),
#jotka muuten saattaisivat viivästyä puskurin takia.

[Install]
WantedBy=multi-user.target
```

```bash
# scriptin käynnistys
sudo systemctl start ros2_motordriver.service

# aseta scripti käynnistymään järjestelmän käynnistyessä
sudo systemctl enable ros2_motordriver.service

# uudelleen käynnistä (esim, jos vaihdat parametrejä)
sudo systemctl restart ros2_motordriver.service

# tarkista tila
systemctl status ros2_motordriver.service

# loki
journalctl -u ros2_motordriver.service -f
```

### Lisätehtävä: Kaikki valmista LED

Tutustu allaolevaan koodiin ja selvitä sen toiminta. Tarvitaan led ja vastus kytkettynä RasperryPi:n GPIO interface pinneihin 16 (GPIO-23) ja 14 (GND)

```python
import rclpy
from rclpy.node import Node
import time
import lgpio

# GPIO-23
LED_PIN = 23

# Open GPIO chip (default for Raspberry Pi)
chip = lgpio.gpiochip_open(4)

# Aseta LED pinni ulostuloksi
lgpio.gpio_claim_output(chip, LED_PIN)

class NodeChecker(Node):
    def __init__(self):
        super().__init__('node_checker')

    def get_running_nodes(self):
        # Haetaan kaikki nodet
        node_names_and_namespaces = self.get_node_names_and_namespaces()
        nodes = [name for name, _ in node_names_and_namespaces]
        return nodes

def main():
    rclpy.init()
    node = NodeChecker()

    active = False

    lgpio.gpio_write(chip, LED_PIN, 0)

    try:
      while True:
          nodes = node.get_running_nodes()
          check_nodes = ['robot_state_publisher', 'motordriver_node', 'odom_node', 'cmd_vel_node']
          active = set(check_nodes).issubset(set(nodes))
      
          if active:
              lgpio.gpio_write(chip, LED_PIN, 1)
  
          else:
              lgpio.gpio_write(chip, LED_PIN, 0)
  
          time.sleep(1)

    except KeyboardInterrupt:
      pass
    finally:
      lgpio.gpio_write(chip, LED_PIN, 0)

      node.destroy_node()
      if rclpy.ok():
        rclpy.shutdown()

if __name__ == '__main__':
    main()
```

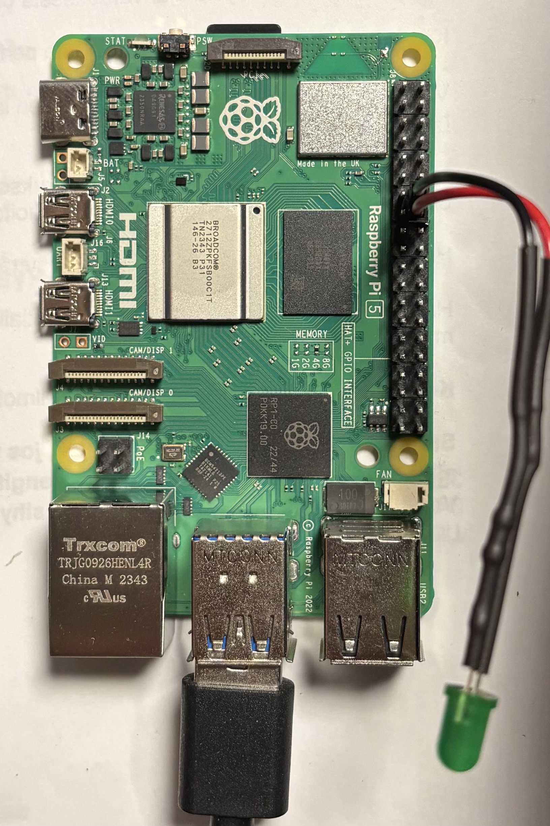
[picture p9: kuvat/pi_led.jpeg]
piled


-
Nomga Oy - SeAMK - ROS 2 ja moottorinohjaus: PWM-signaalista robottien liikkeenhallintaan2025

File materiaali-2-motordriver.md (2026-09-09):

## 2. ROS 2 -pohjainen ohjaus

Materiaali testattu:

- Raspberry PI 5 (image: username: ros2 password: ros2)
- Ubuntu 24.04 (Noble Numbat)
- ROS2 Jazzy Jalisco (jazzy)
- moottori x2
- moottoriohjain
- arduino
- akku kytkentä

ROS2-nodea varten meillä on nyt valmiina osio, joka lähettää nopeusohjeen moottoriohjaimelle. Jotta node olisi käyttökelpoinen osana laajempaa järjestelmää, meidän tulee lisätä siihen seuraavat komponentit:

1. **Subscriber**: Tämä vastaanottaa nopeustiedon, joka ohjataan edelleen moottoriohjaimelle. Näin node voi toimia osana ROS2-järjestelmää ja vastaanottaa ohjauskomentoja toiselta nodelta.
2. **Publisher**: Tämä julkaisee tietoa moottorien toiminnasta, kuten encoder-arvot, moottorien toteutuneet nopeudet ja PWM-asetukset. Julkaistu data voidaan hyödyntää esimerkiksi:

	- Odometriassa: Encoder-arvojen avulla voidaan laskea robotin sijainti ja asento (x, y, θ) suhteessa aloituspisteeseen.
	
	- Tilavalvonnassa: Nopeus- ja PWM-arvot mahdollistavat moottorien tilan seurannan ja varmistavat, että ne toimivat odotetusti ja ilman häiriöitä.

3. **ROS_DOMAIN_ID ja namespace**: ROS2:n hyödyntämä DDS (Data Distribution Service) väliohjelmisto huolehtii kaikesta tietoliikenteen reitittämisestä ROS2 sovellusten (_node_) välillä. Koska tässä harjoituksessa voi olla useampi tietokone ja robotti samassa WLAN-verkossa, kaikki viestit "kuuluvat" kaikille nodeille kaikkien koneiden välillä. Tämän harjoituksen tapauksessa tämä on epätoivottavaa, sillä kukin opiskelija haluaa epäilemättä kontrolloida vain omaa SeBottiaan. Asiaan on kaksi ratkaisua:
  - vaihtaa ``ROS_DOMAIN_ID`` ympäristömuuttujan arvoksi yksilöllinen numero (vakioarvo 0:n sijaan). Kukin ROS2 node viestii vain oman ``ROS_DOMAIN_ID``:nsä "sisällä".
  - hyödyntää ``_namespace_``-toimintoa, jolla käynnistettävien nodejen kaikkien _topicien_, _servicejen_ ja _actionien_ (eli _interfacejen_) eteen lisätään automaattisesti annettu namespace-nimi. Tällöin esimerkiksi noden koodissa luotava /odom topic muunnetaan /[namespace]/odom muotoon.

>Tässä harjoituksessa kokeillaan ensimmäistä vaihtoehtoa, jotta emme sotkeennu liian monimutkaiseen kokonaisuuteen. Näin ollen kannattaa ohittaa kaikki namespacen käyttöön viittaavat kohdat, jotka on merkitty materiaaliin hakasulkeilla, esimerkiksi ``/[SeBot_namespace]``.

Kun haluat muuttaa ``ROS_DOMAIN_ID``-arvoa, kirjoita komentokehotteeseen

```bash
#export ROS_DOMAIN_ID=[arvo], esimerkiksi
export ROS_DOMAIN_ID=1
```

Tämä on voimassa vain kyseisessä komentokehotteessa. Jos haluat saada uuden ``ROS_DOMAIN_ID`` arvon voimaan aina komentokehotteen käynnistyessä, lisää ylläoleva rivi kotihakemistosta löytyvään ```.bashrc```-tiedoston loppuun:
```bash
nano ~/.bashrc # Tai muu editori
```
**~/.bashrc**
```
...
export ROS_DOMAIN_ID=1

>>ctrl+o, ctrl+x # Tallenna ja poistu nano-ohjelmasta
```
```bash
source ~/.bashrc # Lataa .bashrc-tiedosto uudestaan tässä komentokehotteessa
```

### Lopullinen toiminta

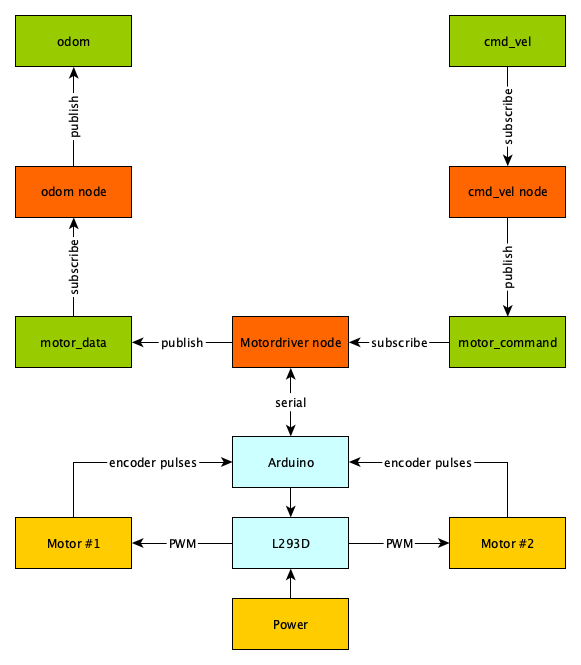
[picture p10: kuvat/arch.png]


#### Motordriver Subscriber (motor_command)
Toteutamme subscriber-komponentin mahdollisimman yksinkertaisena käyttämällä std_msgs.msg.String -tyyppistä dataa. Tämä mahdollistaa sen, että ylemmällä tasolla voidaan lähettää suoraan moottoriohjaimen komentostringejä ilman tarvetta muuntaa tietoa eri formaatteihin. Näin vältämme turhaa monimutkaisuutta ja voimme testata ja käyttää nodea nopeasti.

Luodaan motordriver python paketti

```bash
mkdir -p ~/ros2_ws/src
cd ~/ros2_ws/src/
ros2 pkg create --build-type ament_python motordriver
cd ~/ros2_ws/src/motordriver/motordriver
```

Luodaan ```motordriver.py``` tiedosto, jossa hyödynnetään jo tekemäämme koodia moottoriohjaimen hallintaan. Tämä tiedosto toimii modulaarisena komponenttina, jota voidaan käyttää ROS2-nodessa tai muissa projekteissa.

**~/ros2\_ws/src/motordriver/motordriver/motordriver.py**

```python
import rclpy
from rclpy.node import Node

from std_msgs.msg import String

import serial
import time

class MotordriverNode(Node):
  def __init__(self):
    super().__init__('motordriver_node')

    self.arduino = serial.Serial("/dev/ttyACM0", 115200, timeout=1)
    if not self.arduino.isOpen():
      raise Exception("Ei yhteyttä moottoriohjaimeen")

    # moottori pysähtyy jos ei saa uutta komentoa 1s kuluessa
    self.arduino.write(("ALIVE;1;\n").encode())

    self.subscriber = self.create_subscription(
        String,
        'motor_command',
        self.motor_command_callback,
        10
    )

  def motor_command_callback(self, message):
    self.arduino.write(("%s\n"%message.data).encode())

def main(args=None):
  rclpy.init(args=args)
  motordriver_node = MotordriverNode()
  try:
    rclpy.spin(motordriver_node)
  except KeyboardInterrupt:
    pass
  finally:
    motordriver_node.destroy_node()
    if rclpy.ok():
      rclpy.shutdown()

if __name__ == '__main__':
  main()
```

``create_subscription`` on ROS2:n Node-luokan metodi, jonka avulla node voi tilata viestejä tietyltä topicilta. Kun topicille julkaistaan viesti, node suorittaa määritetyn palautefunktion (callback), joka käsittelee saapuvan viestin.

```python
    self.subscriber = self.create_subscription(
        String,				# msg_type
        'motor_command',		# topic_name
        self.motor_command_callback,	# callback
        10				# quos
    )
```

##### create_subscription -funktion parametrit:
1. msg_type
	
 	Määrittelee viestityypin, jota topicilla käytetään. 
2. topic_name
	
	Topicin nimi, jota node tilaa. Tämä tulee kirjoittaa ilman edeltävää kenoviivaa /, jotta topicin nimestä tulee suhteellinen (eikä absoluuttinen) ja siten namespace-asetus voi toimia.
3. callback

	Funktio, joka suoritetaan aina, kun topicilta saapuu viesti. Tämä funktio vastaanottaa parametrina topicilta tulevan viestin ja käsittelee sen, tässä tapauksessa kirjoitetaan sarjaporttiin.

	```python
  	def motor_command_callback(self, message):
   		self.arduino.write(("%s\n"%message.data).encode())
	```
4. qos (Quality of Service)

	Määrittelee viestien välityksen luotettavuuden ja suorituskyvyn.
	10 on luotettava ja vakioarvo pienille viestimäärille.

#### Testaus

Voimme testata ohjelman toiminnan ennen varsinaista käännöstä seuraavilla vaiheilla (huom: käytössä pitää olla useampi terminaali):

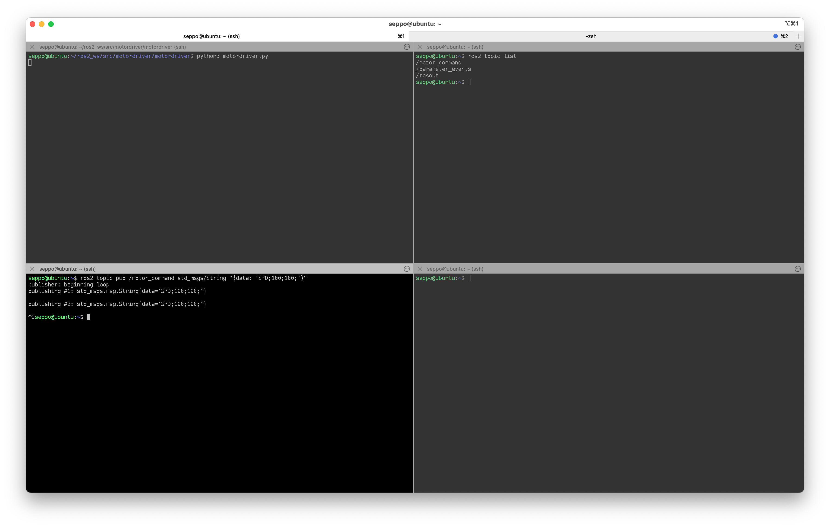
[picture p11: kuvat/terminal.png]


1. ##### Käynnistä moottoriohjainkoodi suoraan Pythonilla
  
  ```
  python3 motordriver.py
  ```
  
  Mikäli virheitä ei ilmene ``motordriver.py`` pitäisi toimia oikein sarjaliikenteen ja komentojen käsittelyn osalta. 
  
  **Huomaa, että kaikki samassa WLAN-verkossa ja ``ROS_DOMAIN_ID``:ssä olevat SeBotit ottavat vastaan kaikki viestit samoista topiceista, jos ne on yllä olevan mukaan samoiksi määritetty koodeissa.** Jos harjoitusta tekee useampi opiskelija samaan aikaan, kannattaa hyödyntää eri ``ROS_DOMAIN_ID``-ympäristömuuttujan arvoja (tai syöttää skriptille käynnistyksen yhteydessä namespace-asetus).
  
  ```bash
  python3 motordriver.py
  #python3 motordriver.py --ros-args -r __ns:=/[SeBot_namespace]
  ```
  >```namespace```a ennen tulee olla kenoviiva /. Namespacena tässä harjoituksessa voisi käyttää oman SeBotin ip-osoitteen jälkimmäistä tavua, esimerkiksi
  >```bash
  >python3 motordriver.py --ros-args -r __ns:=/SeBot11
  >```

2. ##### Katsotaan näkyykö topic listassa  

  ```
  ros2 topic list
  
  /motor_command
  ```

>  Jos samassa WLANissa on useita saman ``ROS_DOMAIN_ID``:n ROS2-sovelluksia kukin omalla namespace-asetuksellaan, listalla näkyy useita topiceja, esimerkiksi
>
>  ```bash
>  ros2 topic list
>
>  /SeBot11/motor_command
>  /SeBot12/motor_command
>  /SeBot13/motor_command
>  ```

3. ##### Lähetä nopeuskomento ROS2-topicia käyttäen

  ```bash
  # julkaisee toistuvasti
  ros2 topic pub /motor_command std_msgs/String "{data: 'SPD;100;100;'}"
  
  # julkaisee toistuvasti 2 kertaa sekunnissa
  ros2 topic pub -r 2 /motor_command std_msgs/String "{data: 'SPD;100;100;'}"
  
  # julkaise vain kerran
  ros2 topic pub -t 1 /motor_command std_msgs/String "{data: 'SPD;100;100;'}"
  ```

  Komento julkaisee ``motor_command`` topicille viestin joka on tyyppiä ``String`` ja sisältää tekstin ``SPD;100;100;`` Mikäli tekemäsi node on nyt käynnissä ja toimii oikein, moottoreiden pitäisi lähteä pyörimään.
  
### Kääntäminen osaksi ROS2 -järjestelmää

Kun ROS 2:ssa käännetään Python-paketteja, tarkoitetaan käytännössä nodejen ja pakettien rakentamista ja asentamista työtilaan (install hakemisto). Kun ohjelmat "kääritään" ROS2-paketeiksi, niitä voidaan ajaa ROS2-ympäristössä, jakaa helpommin muiden käyttäjien kanssa (esimerkiksi riippuvuudet Python- ja C++ kirjastoihin huomioiden) ja käynnistää _launch_-tiedostojen avulla kootusti.

Lisätään node ``setup.py``tiedostoon

**~/ros2\_ws/src/motordriver/setup.py**

```python
from setuptools import find_packages, setup

package_name = 'motordriver'

setup(
    name=package_name,
    version='0.0.0',
    packages=find_packages(exclude=['test']),
    data_files=[
        ('share/ament_index/resource_index/packages',
            ['resource/' + package_name]),
        ('share/' + package_name, ['package.xml']),
    ],
    install_requires=['setuptools'],
    zip_safe=True,
    maintainer='ros2',
    maintainer_email='ros2@todo.todo',
    description='TODO: Package description',
    license='TODO: License declaration',
    tests_require=['pytest'],
    entry_points={
        'console_scripts': [
            'motordriver = motordriver.motordriver:main',
        ],
    },
)
```

##### Käännetään (pythonin tapauksessa vain asennetaan)

```bash
cd ~/ros2_ws
colcon build --packages-select motordriver
```

Otetaan työtilan ``~/ros2_ws`` ympäristömuuttujat käyttöön.

```bash
source ~/ros2_ws/install/setup.bash
```

Ja lisätään sama komento ``~/.bashrc`` -tiedostoon, jotta se on aina automaattisesti käytössä.

```bash
nano ~/.bashrc # Tai muu haluamasi editori
source ~/ros2_ws/install/setup.bash
```

Kun ohjelma on käännetty osaksi järjestelmää se voidaan käynnistää komennolla

```bash
ros2 run motordriver motordriver
#ros2 run motordriver motordriver --ros-arg -r __ns:=/[SeBot_namespace]
```
Huomaa, että --ros-arg -r __ns:=/[SeBot_namespace] on eräs ilmentymä ROS2 ajonaikaisista _uudelleenohjauksista_. Valitsin -r viittaa sanaan _remap_, eli (interfacejen) uudelleenohjaus. Tässä kohdin jokainen opiskelija voi valita namespacekseen esimerkiksi SeBotinsa IP-numeron jälkimmäisen tavun. Tai jonkin muun yksilöivän tunnisteen. Myöhemmin tutustumme myös erilliseen _parametrien_ syöttövalitsimeen -p.

Ja testataan taas

```bash
ros2 topic pub /motor_command std_msgs/String "{data: 'SPD;100;100;'}"

#ros2 topic pub [/[SeBot_namespace]]/motor_command std_msgs/String "{data: 'SPD;100;100;'}"

# Esimerkiksi
ros2 topic pub /SeBot11/motor_command std_msgs/String "{data: 'SPD;100;100;'}"
```

#### Motordriver Publisher (motor_data)

Lisätään ROS2-noden toiminnallisuuteen publisher, joka julkaisee moottoriohjaimelta luetut tiedot muiden nodejen käyttöön. Tämä mahdollistaa sen, että muut nodet voivat hyödyntää moottorin nopeuksia, encoder-arvoja ja PWM-asetuksia.

Eli tetoja jotka moottoriohjain palautti:
``motor1_encoder;motor2_encoder;motor1_speed;motor2_speed;motor1_pwm_set;motor2_pwm_set``

**custom message tyyppi**

Toisin kuin subscriber nodessa käyttämämme standardi viesti tyyppi ``std_msgs/String``, teemme nyt oman viesti tyypin, jotta julkaistava tieto moottoriohjaimelta on selkeämpää ja rakenteellisempaa. Tämä mahdollistaa eri tietokenttien helpon käsittelyn ja parantaa järjestelmän luettavuutta sekä laajennettavuutta.

```bash
cd ~/ros2_ws/src/
ros2 pkg create motordriver_msgs
cd ~/ros2_ws/src/motordriver_msgs/
rm -rf include/
rm -rf src/
mkdir msg
```

Luodaan tiedosto `~/ros2_ws/src/motordriver_msgs/msg/MotordriverMessage.msg` jossa määritellään 

**~/ros2\_ws/src/motordriver\_msgs/msg/MotordriverMessage.msg**

```yaml
int32 encoder1
int32 encoder2
int32 speed1
int32 speed2
```

Kun suoritimme komennon ``ros2 pkg create --build-type ament_python motordriver`` ROS 2 loi automaattisesti pakettirakenteen. Nyt käsittelemme tiedostoja ``package.xml``, josa on pakettikuvauksen määrittely ja ``CMakeLists.txt``, jossa on kääntämiseen liittyvät asetukset.

Muokataan package.xml tiedosto muotoon

**~/ros2\_ws/src/motordriver\_msgs/package.xml**

```xml
<?xml version="1.0"?>
<?xml-model href="http://download.ros.org/schema/package_format3.xsd" schematypens="http://www.w3.org/2001/XMLSchema"?>
<package format="3">
  <name>motordriver_msgs</name>
  <version>0.0.0</version>
  <description>TODO: Package description</description>
  <maintainer email="ros2@todo.todo">ros2</maintainer>
  <license>TODO: License declaration</license>

  <buildtool_depend>ament_cmake</buildtool_depend>

  <buildtool_depend>rosidl_default_generators</buildtool_depend>
  <exec_depend>rosidl_default_runtime</exec_depend>
  <member_of_group>rosidl_interface_packages</member_of_group>

  <test_depend>ament_lint_auto</test_depend>
  <test_depend>ament_lint_common</test_depend>

  <export>
    <build_type>ament_cmake</build_type>
  </export>
</package>
```

Muokataan CMakeLists.txt tiedosto muotoon

**~/ros2\_ws/src/motordriver\_msgs/CMakeLists.txt**

```python
cmake_minimum_required(VERSION 3.8)
project(motordriver_msgs)

if(CMAKE_COMPILER_IS_GNUCXX OR CMAKE_CXX_COMPILER_ID MATCHES "Clang")
  add_compile_options(-Wall -Wextra -Wpedantic)
endif()

# find dependencies
find_package(ament_cmake REQUIRED)
# uncomment the following section in order to fill in
# further dependencies manually.
# find_package(<dependency> REQUIRED)

if(BUILD_TESTING)
  find_package(ament_lint_auto REQUIRED)
  # the following line skips the linter which checks for copyrights
  # comment the line when a copyright and license is added to all source files
  set(ament_cmake_copyright_FOUND TRUE)
  # the following line skips cpplint (only works in a git repo)
  # comment the line when this package is in a git repo and when
  # a copyright and license is added to all source files
  set(ament_cmake_cpplint_FOUND TRUE)
  ament_lint_auto_find_test_dependencies()
endif()

find_package(rosidl_default_generators REQUIRED)
rosidl_generate_interfaces(${PROJECT_NAME}
  "msg/MotordriverMessage.msg"
 )
ament_export_dependencies(rosidl_default_runtime)

ament_package()
```

Käännetään uusi viesti tyyppi osaksi järjestelmää.

```
cd ~/ros2_ws
colcon build --packages-select motordriver_msgs
source ~/ros2_ws/install/setup.bash
```

Muokataan ``motordriver.py``tiedostoa lisäämällä sinne publisher motor_data topic:lle. Ajastetaan se kysymään tietoa 10Hz taajuudella.

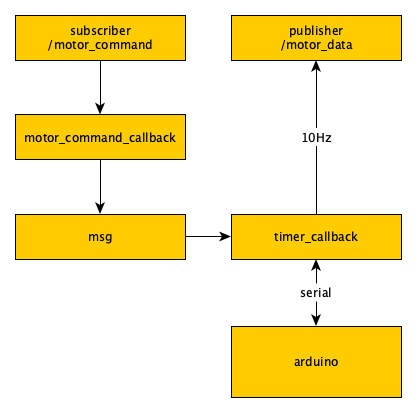
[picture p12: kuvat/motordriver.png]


**~/ros2\_ws/src/motordriver/motordriver/motordriver.py**

```python
import rclpy
from rclpy.node import Node

from std_msgs.msg import String

import serial
import time

from motordriver_msgs.msg import MotordriverMessage

class MotordriverNode(Node):
  def __init__(self):
    super().__init__('motordriver_node')

    self.msg = "x\n"
    self.timercount = 0

    self.arduino = serial.Serial("/dev/ttyACM0", 115200, timeout=1)
    if not self.arduino.isOpen():
      raise Exception("Ei yhteyttä moottoriohjaimeen")
    # moottori pysähtyy jos ei saa uutta komentoa 1s kuluessa
    
    self.arduino.write(("ALIVE;1;\n").encode())
    
    self.subscriber = self.create_subscription(
        String,
        'motor_command', # suhteellinen viittaus. Jos eteen kirjoittaa kenoviivan, esimerkiksi '/motor_command', siitä tulee absoluuttinen, eikä namespace-asetus enää vaikuta siihen.
        self.motor_command_callback,
        10
    )

    self.publisher = self.create_publisher(
        MotordriverMessage,
        'motor_data',
        10
    )

    timer_period = 0.01  # Sekuntia
    self.timer = self.create_timer(timer_period, self.timer_callback)

  def timer_callback(self):
    # Luodaan viesti Arduinolle
    if self.msg != "x\n":
        self.arduino.write(self.msg.encode())

    if self.timercount == 11:
        if self.msg == "x\n":
            self.arduino.write(self.msg.encode())

        self.timercount = 0
        if self.arduino.inWaiting()>0:
          while self.arduino.inWaiting()>0:
            answer=self.arduino.readline().decode("utf8").split(";")
          
          msg = MotordriverMessage()

          try:
            msg.encoder1 = int(answer[0])
            msg.encoder2 = int(answer[1])
            msg.speed1 = int(answer[2])
            msg.speed2 = int(answer[3])

            # Julkaistaan viesti topicissa
            self.publisher.publish(msg)
          except Exception as err:
            pass

    self.msg = "x\n"
    self.timercount += 1
    
  def motor_command_callback(self, message):
    self.msg = "%s\n"%(message.data)

def main(args=None):
  rclpy.init(args=args)
  motordriver_node = MotordriverNode()
  try:
    rclpy.spin(motordriver_node)
  except KeyboardInterrupt:
    pass
  finally:
    motordriver_node.destroy_node()
    if rclpy.ok():
      rclpy.shutdown()

if __name__ == '__main__':
  main()
```

Otetaan uusi viesti tyyppi käyttöön

```python
from motordriver_msgs.msg import MotordriverMessage
```

Viesti joka lähetetään moottoriohjaimelle. "x\n" vain lyhyt viesti, jotta saadaan vastaukset luettua.

```python
    self.msg = "x\n"
```

``create_publisher`` on ROS2:n Node-luokan metodi, jonka avulla voidaan luoda publisher, eli viestien lähettäjä, tietylle topicille. Publisher mahdollistaa sen, että node voi jakaa tietoa muille nodeille ROS2-järjestelmässä.

```python
    self.publisher = self.create_publisher(
        MotordriverMessage,	# msg_type eli viestin ROS2 tietotyyppi.
        'motor_data',		# topicin nimi, huomaa että tässä ei käytetä edessä kenoviivaa /, jotta namespace-asetus voi toimia. Jos kenoviivan kirjoittaa topicin eteen, siitä tulee absoluuttinen viittaus suhteellisen viittauksen sijaan.
        10					# qos
    )
```

##### Parametrit:
1. msg_type
	
	Viestityyppi, jota topic käyttää.
	
2. topic_name

Topicin nimi, johon viesti julkaistaan.

3. qos (Quality of Service)

	Laadunhallintaprofiili, joka määrittää, kuinka viestejä käsitellään, jos lähettäjän ja vastaanottajan välinen yhteys ei ole täydellinen. Luku 10, riittää useimpiin tilanteisiin.

Luomme ajastimen, joka pyörii 100Hz taajuudella. Ohjaimelle tulevaa ohjauskäskyä ei lähetetä suoraan vaan se lähetetään ajastimessa. Ajastimessa luetaan 10Hz taajuudella uusia arvoja moottoriohjaimelta. Näin pyritään estämään liiallinen epäsäännöllinen liikenne, joka haittaisi PID säätimen toimintaa.

```python
    timer_period = 0.01  # Sekuntia
    self.timer = self.create_timer(timer_period, self.timer_callback)

  def timer_callback(self):
    # Luodaan viesti
    if self.msg != "x\n":
        self.arduino.write(self.msg.encode())

    if self.timercount == 11:
        if self.msg == "x\n":
            self.arduino.write(self.msg.encode())
        self.msg = "x\n"

        self.timercount = 0
        if self.arduino.inWaiting()>0:
          answer=self.arduino.readline().decode("utf8").split(";")
          self.arduino.flushInput()

          msg = MotordriverMessage()

          try:
            msg.encoder1 = int(answer[0])
            msg.encoder2 = int(answer[1])
            msg.speed1 = int(answer[2])
            msg.speed2 = int(answer[3])

            # Julkaistaan viesti
            self.publisher.publish(msg)
          except Exception as err:
            pass

    self.timercount += 1

  def motor_command_callback(self, message):
    self.msg = "%s\n"%(message.data)
```

Voimme taas käynnistä noden yksinkertaisesti (huom: source... pitää olla ajettuna):
```bash
python3 motordriver.py
#python3 motordriver.py --ros-args -r __ns:=/[SeBot_namespace]
```
Ja tarkistaa, että kumpikin node on käynnissä (huomioiden jälleen, että tässä vaiheessa kaikkien samassa ``ROS_DOMAIN_ID``:ssä olevien SeBotin topicit ovat samoja, jos ne on niin koodeihin kirjoitettu).

```bash
ros2 topic list

[/SeBot_namespace]/motor_command
[/SeBot_namespace]/motor_data
```

Moottorin pyörittämisen pitäisi toimia samalla tavalla kuin aiemmin
```bash
ros2 topic pub /motor_command std_msgs/msg/String "{data: 'SPD;100;-100;'}"
#ros2 topic pub /[SeBot_namespace]/motor_command std_msgs/msg/String "{data: 'SPD;100;-100;'}"
```
Ja lisäksi meidän pitäisi saada arvoja (muista source käsky jos ajat vanhassa ikkunassa)

```bash
ros2 topic echo /motor_data
#ros2 topic echo /[SeBot_namespace]/motor_data

	encoder1: 22663
	encoder2: 23018
	speed1: 102
	speed2: 99
	---
	encoder1: 22569
	encoder2: 22924
	speed1: 99
	speed2: 100
	---
	encoder1: 22474
	encoder2: 22829
	speed1: 99
	speed2: 100
	---
	encoder1: 22379
	encoder2: 22735
	speed1: 101
	speed2: 100
```

Kaikki kunnossa? Käännetään paketti

```bash
cd ~/ros2_ws
colcon build --packages-select motordriver
```

Ja nyt voimme käynnistää node:n

```bash
ros2 run motordriver motordriver
```

Näin olemme luoneet noden, joka välittää ``motor_command``-topiciin julkaistut komennot moottoriohjaimelle ja julkaisee ``/[SeBot_namespace]`` ``/motor_data``-topicista moottorin nopeustiedot sekä enkooderin arvot. Jos haluamme, voimme lisätä PWM ohjaus arvot myös luomaamme ``MotordriverMessage``-viesti tyyppiin ja näin pääsemme halutessamme lukemaan mitä PWM arvoja SPD komento moottorille antaa.

Lisätään **~/ros2\_ws/src/motordriver\_msgs/msg/MotordriverMessage.msg** tiedostoon:

```yaml
int32 pwm1
int32 pwm2
```

ja **~/ros2\_ws/src/motordriver/motordriver/motordriver.py** tiedostoon:

```python
msg.pwm1 = int(answer[4])
msg.pwm2 = int(answer[5])
```

Voimme kääntää kummatkin paketit kerralla:

```bash
cd ~/ros2_ws
colcon build --packages-select motordriver motordriver_msgs
```

Simulointi ilman oikeaa moottoriohjainta. Tehdään emulaattori sarjaportin vaihtoehdoksi.

**~/ros2\_ws/src/motordriver/motordriver/simserial.py**

```python
import time
import threading

class SimSerial():
  def __init__(self):
    self.answer = [0,0,0,0,0,0]
    self.response = 0
    self.encoder_min = -32768
    self.encoder_max = 32768
    self.sim_odo_left = SimuOdo(self.encoder_min, self.encoder_max)
    self.sim_odo_right = SimuOdo(self.encoder_min, self.encoder_max)

  def write(self,message):
    try:
      a = message.decode().split(";")
      self.sim_odo_left.set_speed(int(a[1]))
      self.sim_odo_right.set_speed(int(a[2]))

      self.answer[4] = self.sim_odo_left.speed
      self.answer[5] = self.sim_odo_right.speed

    except Exception as err:
      pass

    self.answer[0] = self.sim_odo_left.tell_ticks()
    self.answer[1] = self.sim_odo_right.tell_ticks()

    self.response = 1

  def inWaiting(self):
    return self.response

  def readline(self):
    retval = ";".join([str(x) for x in self.answer]).encode()
    self.response = 0
    return retval

class SimuOdo():
    """Tämä luokka 'simuloi' fyysistä enkooderia, mikä mahdollistaa ROS2-koodikokonaisuuden ajamisen ilman fyysistä laitteistoa."""
    def __init__(self, encoder_min, encoder_max):
        self.speed = 0
        self.ticks = 0
        self.encoder_min = encoder_min
        self.encoder_max = encoder_max
        thread = threading.Thread(target = self.run_periodically)
        thread.start()
    def run_periodically(self):
        while True:
            self.roll()
            time.sleep(0.1)

    def set_speed(self, speed):
        self.speed = speed

    def roll(self):
        self.ticks = self.ticks + self.speed
        if self.ticks > self.encoder_max:
          self.ticks -= self.encoder_max-self.encoder_min
        if self.ticks < self.encoder_min:
          self.ticks += self.encoder_max-self.encoder_min

    def tell_ticks(self):
        return self.ticks
```

Muokataan motordriver.py tiedostoa:

**~/ros2\_ws/src/motordriver/motordriver/motordriver.py**

```python
.
.
.
try:
  from .simserial import SimSerial
except:
  from simserial import SimSerial

class MotordriverNode(Node):
  def __init__(self):
    super().__init__('motordriver_node')

    self.msg = "x\n"
    self.timercount = 0

	 # jos simulation parametria ei löydy niin oletuksena se on True
    self.declare_parameter('simulation', True)
    self.simulation = self.get_parameter('simulation').value
    self.get_logger().info(f'Käynnistetään motor_controller simulaatiossa: {self.simulation}')
    if self.simulation:
      self.arduino = SimSerial()
    else:
      self.arduino = serial.Serial("/dev/ttyACM0", 115200, timeout=1)
      if not self.arduino.isOpen():
        raise Exception("Ei yhteyttä moottoriohjaimeen")

    self.subscriber = self.create_subscription(
        String,
        'motor_command',
        self.motor_command_callback,
        10
    )

    self.publisher = self.create_publisher(
        MotordriverMessage,
        'motor_data',
        10
    )

    timer_period = 0.01  # seconds
    self.timer = self.create_timer(timer_period, self.timer_callback)        
.
.
.        
```

Nyt voit lisätä parametrin komentorivillä. Vertaa aiemmassa kohdassa tehtyyn ``namespace``-asetukseen, joka tehtiin -r (joka on sama kuin --remap) valitsimella.

```bash
python3 motordriver.py --ros-args -p simulation:=False #-r __ns:=/[SeBot_namespace]
```

Tai kääntämisen jälkeen:

```bash
ros2 run motordriver motordriver --ros-args -p simulation:=False #-r __ns:=/[SeBot_namespace]
```

Lisätään parametri asetustiedostoon (False = käytetään oikeaa sarjaporttia). Launch tiedostoa varten.

**~/ros2\_ws/config/params.yaml**

```yaml
motordriver_node:
  ros__parameters:
    simulation: False
```

**Huomaa, että noden parametritiedostoon ei voi kirjoittaa namespace-asetusta. Se ei ole varsinainen parametri, vaan ajonaikainen uudelleenohjaus (remapping).**

-
Nomga Oy - SeAMK - ROS 2 ja moottorinohjaus: PWM-signaalista robottien liikkeenhallintaan

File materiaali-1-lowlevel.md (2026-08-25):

## Moottorinohjaus

### Yleiskuvaus

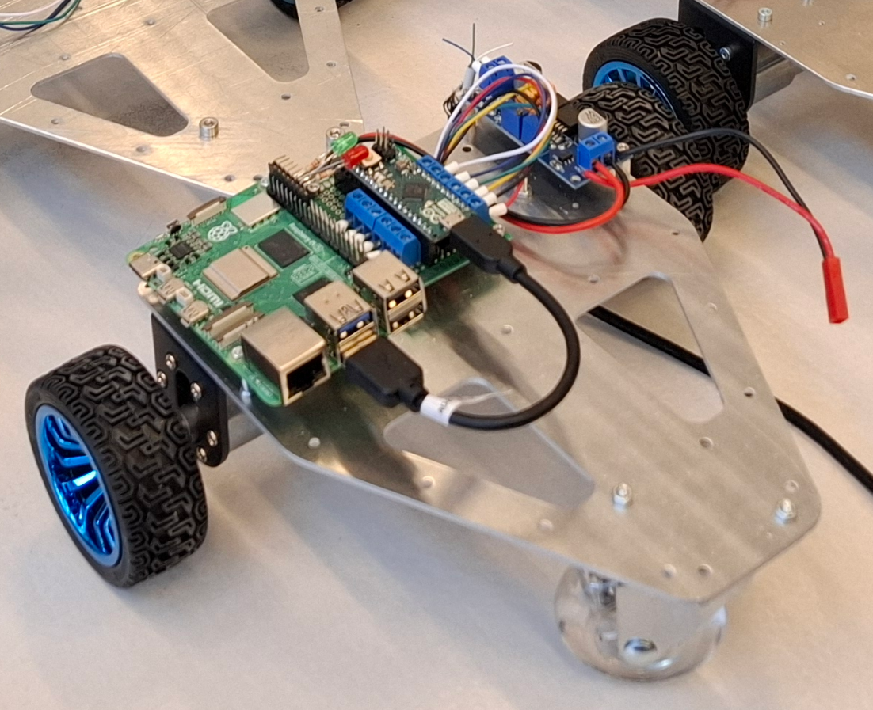
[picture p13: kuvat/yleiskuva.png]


- Raspberry PI 5, [esimerkiksi Botland](https://botland.store/raspberry-pi-5-modules-and-kits/23905-raspberry-pi-5-8gb-5056561803326.html). Myös vanhemmat Raspberryt soveltuvat hyvin.
- [Raspberry virtalähde](https://botland.store/raspberry-pi-5-power-supply/23906-raspberry-pi-27w-usb-c-power-supply-official-51v-5a-psu-for-raspberry-pi-5-white-5056561803401.html) Robottia on hyvä pitää verkkovirrassa kehitysvaiheen ajan.
- [32GB muistikortti](https://botland.store/raspberry-pi-memory-cards/25873-raspberry-microsd-32-gb-memory-card-5056561804200.html)
- [Arduino Micro](https://botland.store/arduino-basic-boards/1481-arduino-micro-module-a000053-7630049200159.html)
- [USB A - Micro USB](https://botland.store/usb-20-cables/17430-cable-microusb-b-usb-a-20-hi-speed-015m-black-4040849957369.html) Raspberryn ja Arduinon sarjaporttiliikennettä varten
- [Moottoriohjain L293D](https://botland.store/drivers-for-dc-motors/176-l293d-two-channel-36v-06a-motor-driver-5pcs-5904422350253.html)
- 2 x [DC-moottori vaihteistolla ja enkooderilla 12VDC](https://www.aliexpress.com/item/1005006217803283.html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)
- [Stepdown converter säädettävä jännitteenalentaja 5A 25W](https://botland.store/converters-step-down/8103-step-down-voltage-regulator-xl4015-13v-36v-5a-5904422336202.html)
- [USB C kaapeli](https://botland.store/usb-c-cables/18762-green-cell-powerstream-usb-type-c-usb-type-c-quick-charge-cable-12-m-black-5907813963599.html) virtajohdoksi jännitteenalentimen ja Raspberryn väliin
- [3s (12,6V) LiPo akku](https://botland.store/battery-li-half-3s-111-v/2394-li-pol-dualsky-800mah-25c-3s-111v-eco-s-package-6941047104662.html). Isompi akku on eduksi jos robottia haluaa käyttää pitkästi akkuvirralla. Huomaa, että tämän ohjeen mukaiset moottorit eivät kestä yli 3S lipo akkuja, eli esimerkiksi 16,8V 4S akut vaativat erilaiset moottorit.

Jos piirilevyn tekee itse, voi tarvita myös oheisia (tai niiden kaltaisia, suunnittelusi mukaan) osia
- [Juotoslevyt](https://www.aliexpress.com/item/1005007014530064.html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)
- [Riviliittimet](https://www.tme.eu/fi/en/details/dg128-5.0-02p14/pcb-terminal-blocks/degson-electronics/dg128-5-0-02p-14/)
- [Headerit](https://botland.store/connectors-goldpin/8505-socket-1x20pin-254mm-5904422311780.html)
- [M2.5 Korokkeet](https://www.tme.eu/fi/en/details/tfm-m2.5x10_dr222o/metal-spacers/dremec/222x10of/)
- [M2.5 ruuvit](https://www.tme.eu/fi/en/details/b2.5x6_bn15857/bolts/bossard/3108702/)
Lisäksi sopivia johtimia, LEDeja ym.

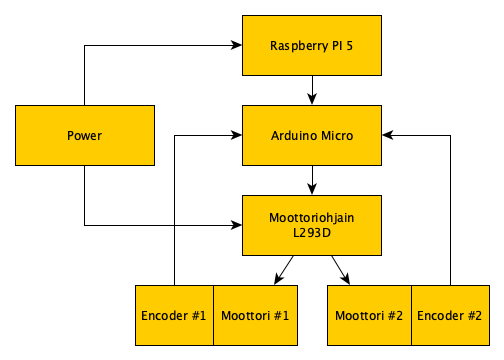
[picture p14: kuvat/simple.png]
 

Voit myös tilata valmiiksi ladotun piirilevyn /hardware kansion tiedostoja hyödyntäen. Piirilevyn valmistusta varten projektista löytyvät valmiit Gerber-tiedostot, joiden avulla levyn voi tilata suoraan esimerkiksi JLCPCB:ltä tai vastaavalta valmistajalta. Projektin osaluettelo (BOM) on myös tulostettavissa, mutta on hyvä huomioida, ettei aivan kaikille yleisimmille komponenteille ole määritetty kiinteää valmistajan osanumeroa. Osaluettelossa käytettyjä komponentteja tuleekin pitää suosituksina ja esimerkkeinä; ne voi vapaasti korvata muista lähteistä hankituilla, teknisesti vastaavilla osilla.

Kahdella pyörällä liikkuvan robotin liike perustuu renkaiden moottoreiden toimintaan, jotka saavat ohjeensa ylemmältä tasolta. ROS-ympäristössä nämä ohjeet annetaan yleensä cmd_vel-viesteissä, joissa määritellään robotin lineaarinen nopeus ja pyörimisnopeus. Näitä tietoja hyödyntäen robottiin kytketty ROS-node laskee kullekin renkaalle tarvittavat pyörimissuunnat ja nopeudet, jotka välitetään moottoriohjaimelle.

Tämä laskenta edellyttää seuraavia tietoja:

- Renkaiden halkaisija: Vaikuttaa lineaarisen nopeuden ja kulmanopeuden väliseen suhteeseen.
- Encoderin pulssimäärä per kierros: Tarvitaan tarkkaan liikkeen mittaamiseen ja nopeuden säätöön.
- Renkaiden välinen etäisyys (raideleveys): Vaikuttaa robotin kääntymisen laskentaan.

Moottoriohjain käyttää H-siltaa, kuten L293D-piiriä, renkaiden pyörimissuunnan ohjaamiseen, ja PWM-signaalia renkaiden pyörimisnopeuden säätöön. Vertaamalla encoderien signaalia asetettuihin arvoihin moottoriohjain saavuttaa tarkan nopeudensäätelyn PID-säätimen avulla, mikä mahdollistaa sekä suoran että pyörivän liikkeen tarkan ja hallitun toteutuksen.

**DC-moottorin ohjaus ja Arduino:**

Robotin moottorien ohjaukseen käytetään L293D H-siltapiiriä, joka mahdollistaa kahden moottorin hallinnan samanaikaisesti. Piiri on liitetty Arduino-mikrokontrolleriin, jossa on esimerkkiohjelma moottorien hallintaan. Ohjelma mahdollistaa:

- Moottorien ohjauksen suoraan PWM-komentojen avulla.
- Moottorien ohjauksen PID-säätimen avulla, joka tuottaa PWM-signaalin moottorien nopeuden säätämiseksi.

Ohjelma määrittää moottorin pyörimissuunnan PID-säätimen tai PWM-komennon tuottaman arvon perusteella:

- Positiivinen arvo ohjaa moottorin pyörimään eteenpäin.
- Negatiivinen arvo kääntää moottorin suunnan taaksepäin.

Tämä järjestelmä yhdistää ROS-ympäristön komennot ja Arduino-pohjaisen ohjauksen, mikä mahdollistaa tarkan ja joustavan robotin liikkeenhallinnan sekä nopeuden että suunnan osalta.

### Laitteisto

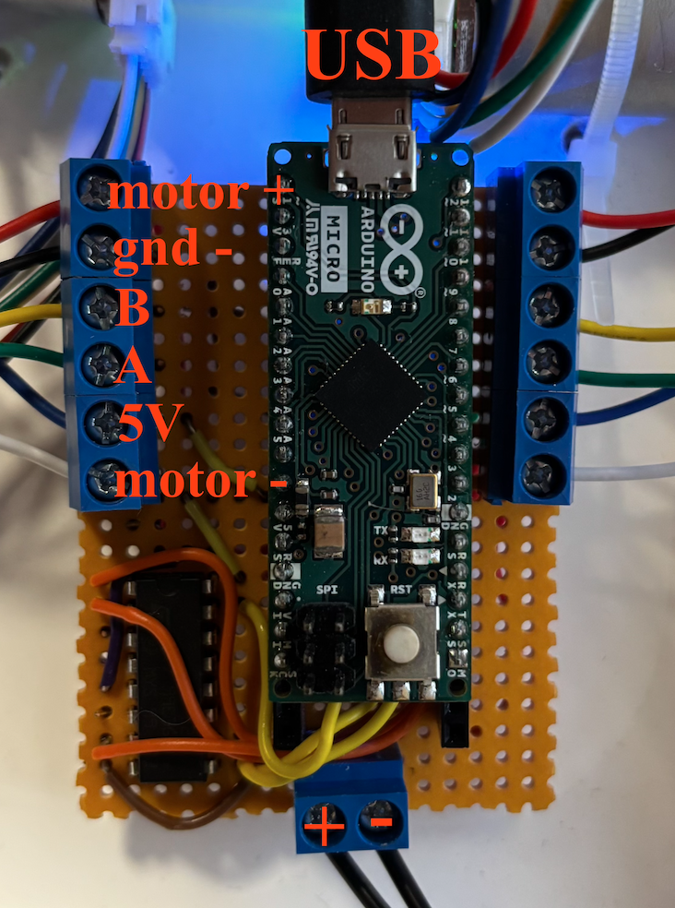
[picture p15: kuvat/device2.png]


Arduino Micro, L293D, [DC6-24v Gear Motor with Encoder](https://www.elecrow.com/dc624v-gear-motor-with-encoder-p-1616.html)

### Kytkentä reikälevylle

Allaolevassa taulukossa on annettu kytkennät Arduino Micron, L293D piirin ja moottoreiden välillä. Hyödynnä tätä, mikäli rakennat piirilevyn itse esimerkiksi reikälevylle tai koekytkentälevylle. 

 <table>
<tr>
<td valign="top">

| moottori  | toiminta | arduino  | L293D  |
|---|---|---|---|
| valkoinen | motor - | | 3 , 11 |
| sininen | sensor + | +5V | |
| vihreä | A |  3 , 2 | |
| keltainen | B |  4 , 9 | |
| musta | sensor gnd | GND | |
| punainen  | motor + | | 6 , 14 |

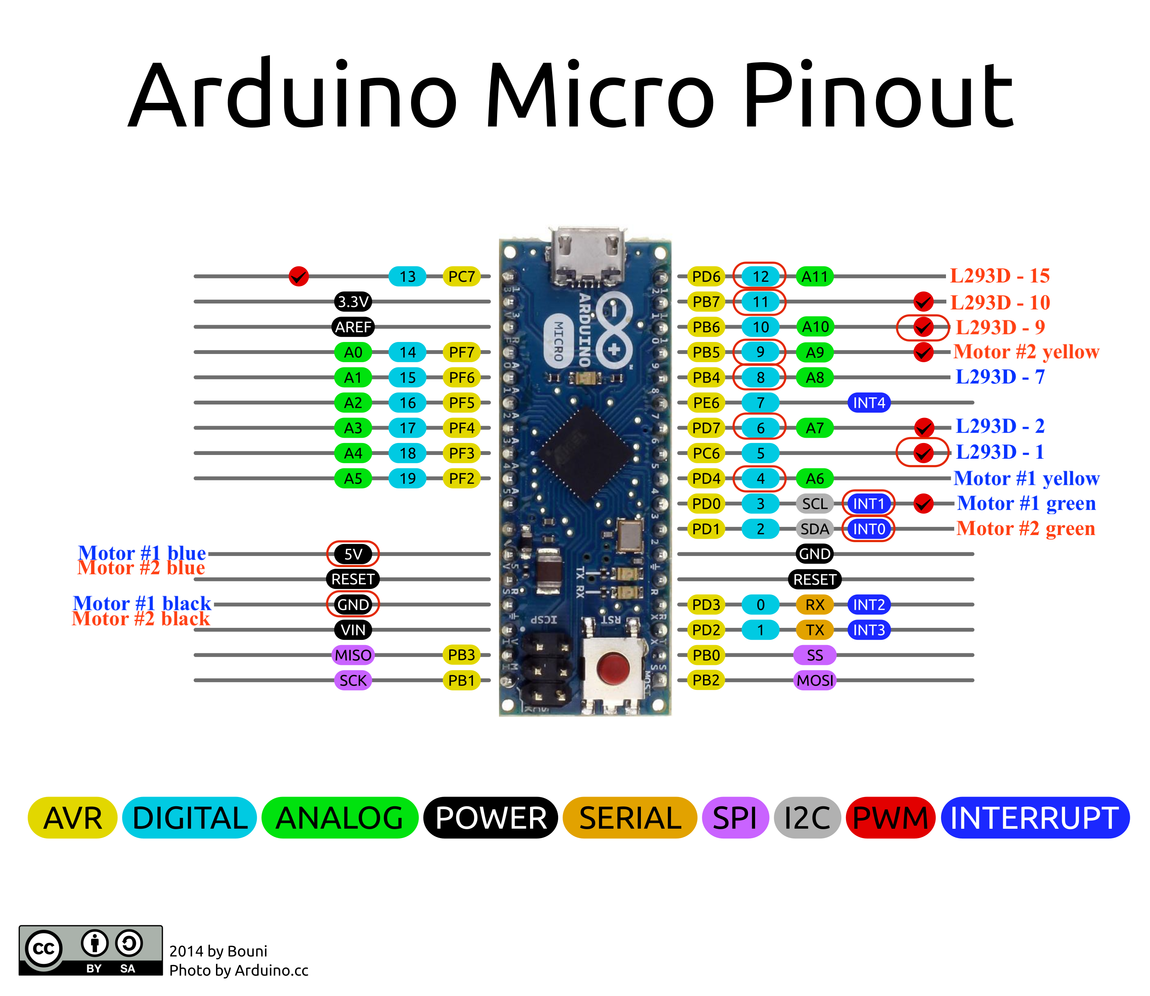
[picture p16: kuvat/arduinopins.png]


</td><td>

| PIN| L293D | arduino  |  moottorit |
|----|---|---|---
| 1  | enable1 | 5 | |
| 2  | input1  | 6 | |
| 3  | output1 | | #1 valkoinen |
| 4  | gnd | GND | |
| 5  | gnd | GND | |
| 6  | output2 | | #1 punainen  |
| 7  | input2  | 8 | |
| 8  | Vs | +12V  | |
| 9  | enable2 | 10 | |
| 10 | input3  | 11 | |
| 11 | output3 | | #2 valkoinen |
| 12 | gnd | GND | |
| 13 | gnd | GND | |
| 14 | output4 | | #2 punainen  |
| 15 | input4  | 12 | |
| 16 | Vss. | +5V | |

</td>
</tr>
</table>

### Kytkentä piirilevylle
Voit hyödyntää valmiiksi suunniteltua, yllä esitettyä edistyneempää piirilevyä. Tarvittavat tiedostot piirilevyn tilaamiseksi löydät projektin /hardware kansiosta. Kyseinen piirilevy sisältää erillisen rajapinnan ulkoiselle hätäseis-painikkeelle, joka on toteutettu piikkirimalla. Rajapinta on suunniteltu käytettäväksi NC-tyyppisen 3PDT-kytkimen kanssa, jolloin painikkeen aktivointi katkaisee fyysisesti Arduinon ja L293D-moottoriohjainpiirin enable-signaalit. Samalla Arduinon digitaalitulo tunnistaa hätätilan ulkoisen ylösvetovastuksen ansiosta, mikä mahdollistaa tilanteen huomioimisen myös ohjelmistotasolla. Mikäli hätäseis-painiketta ei kytketä järjestelmään, piikkiriman pinnit on yhdistettävä kolmella jumpperilla normaalin toiminnan varmistamiseksi.
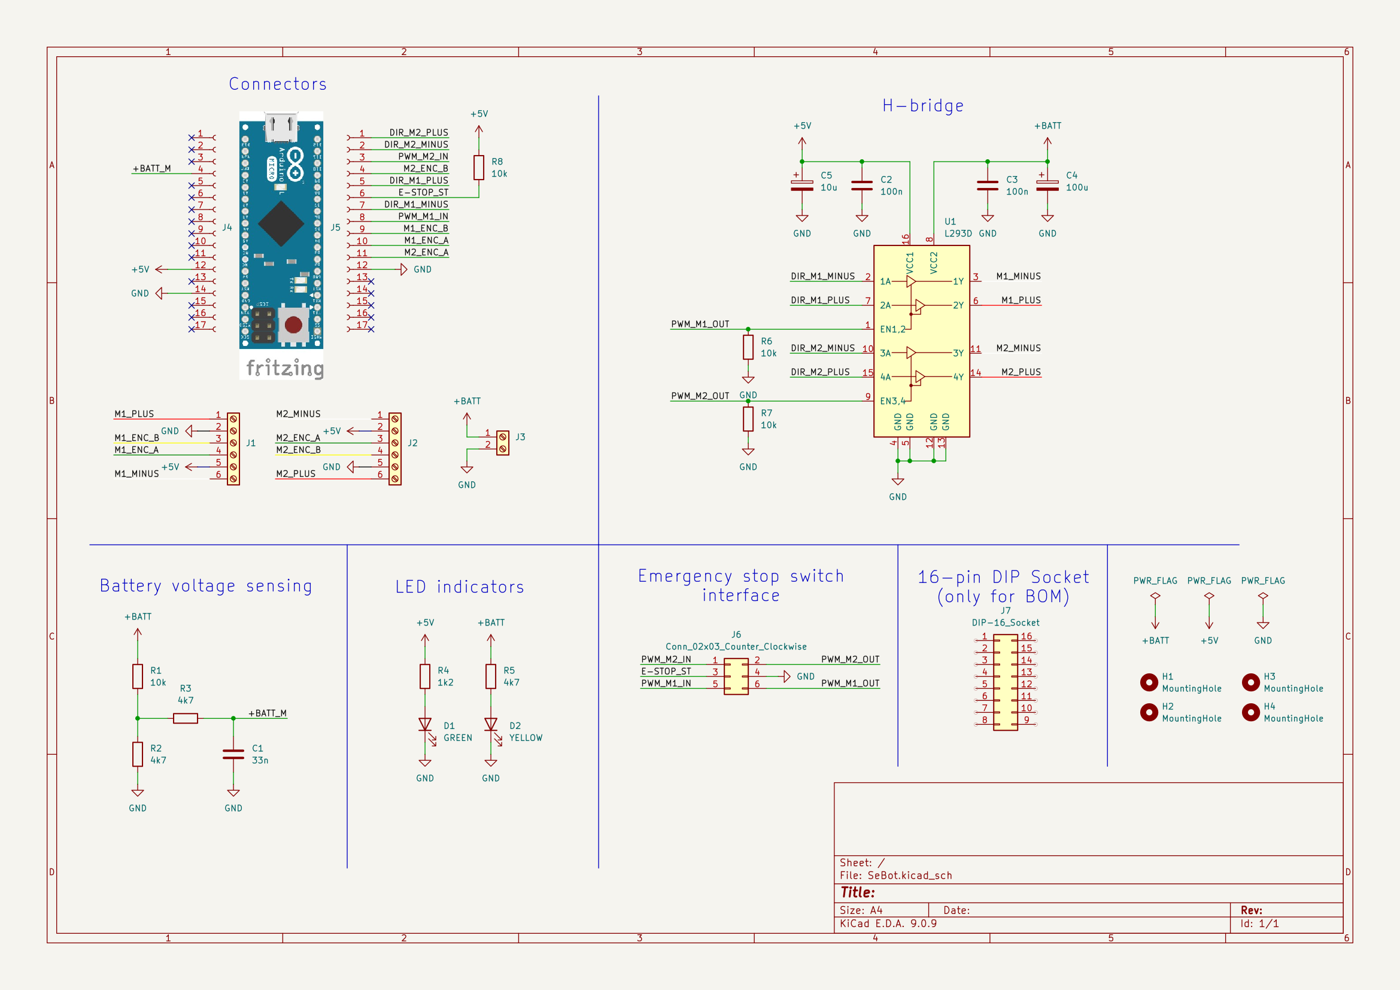
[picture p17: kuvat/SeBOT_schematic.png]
SeBOT kytkentäkaavio

Kytkentäkaavio valmiille piirilevylle.
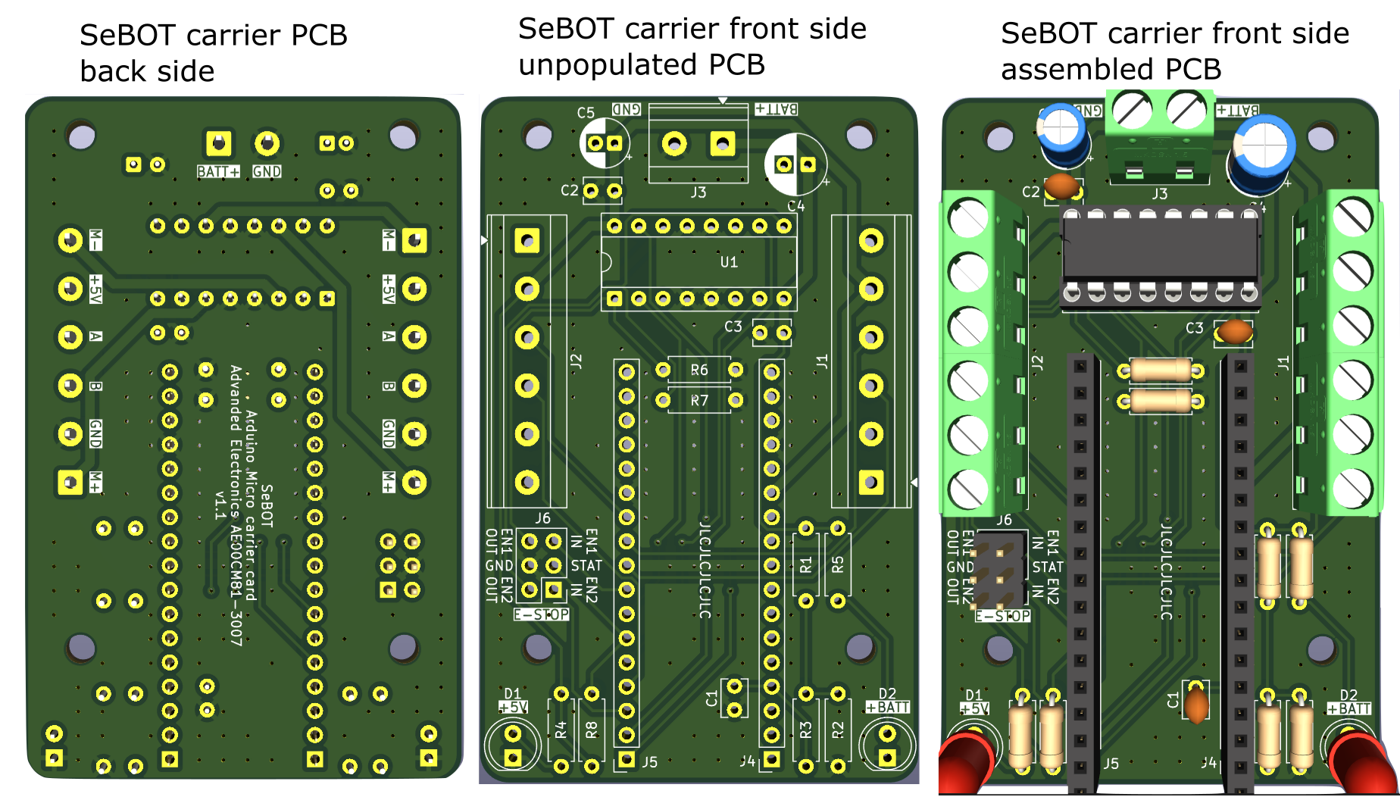
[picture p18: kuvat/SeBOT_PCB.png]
Esimerkki valmiista piirilevystä

Esimerkki valmiista piirilevystä ([ohjeet /hardware kansiossa](hardware)).
#### Komennot
Arduinoon on ohjelmoitu seuraavat komennot:

1. Suora säätö: ``PWM;100;100;``
2. PID säätö: ``SPD;100;100;``
3. PID arvot: ``PID;0.7;0.003;0.0;``
4. Nollaa enkooderit: ``ZERO;``
5. Säädä alive arvoa (0 = pois): ``ALIVE;3;``

PWM ja SPD -arvot vaihtelevat välillä -255 – +255. Nämä arvot itsessään eivät edusta nopeutta metreinä sekunnissa (m/s), vaan muunnos tapahtuu ROS-nodessa. Pyörimissuunta määräytyy arvon etumerkin perusteella.

Kaikki komennot palauttavat stringin:  ``encoder1;encoder2;rpm1;rpm2;pwm1;pwm2``

### Suora PWM ohjaus
``PWM;64;191;`` tarkoittaa, että moottorille #1 syötetään 25 %:n PWM-signaalia ja moottorille #2 75 %:n PWM-signaalia. Kun nämä signaalit kulkevat L293D-piirin läpi, piiri vahvistaa ne syöttöjännitteensä perusteella, jolloin saavutetaan moottoreille sopiva jännitetaso. L293D toimii tässä signaalivahvistimena ja ohjauselementtinä.

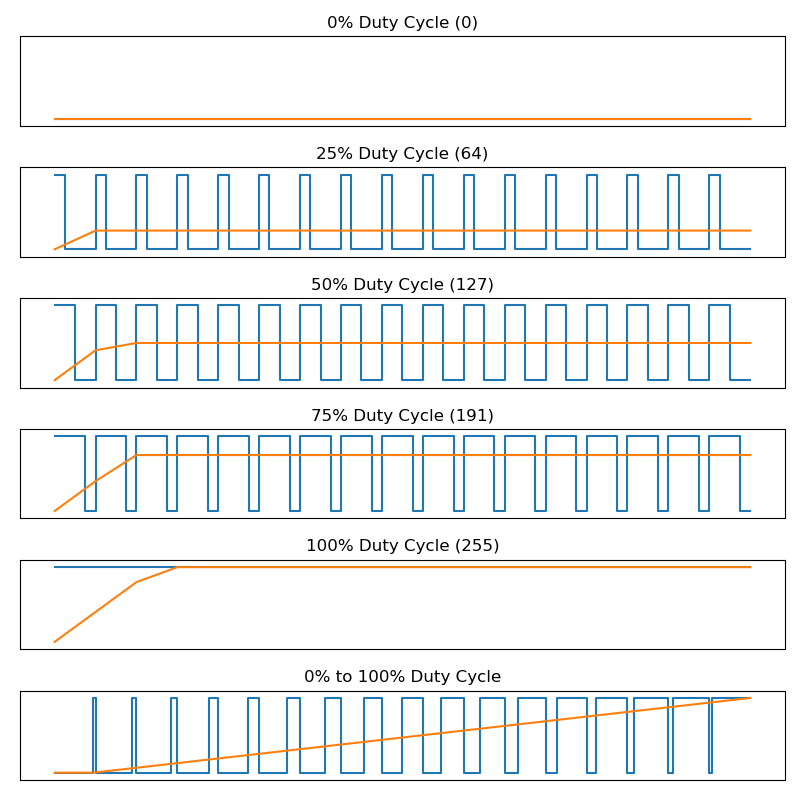
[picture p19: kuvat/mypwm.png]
https://docs.arduino.cc/learn/microcontrollers/analog-output/


Moottorin maksiminopeus saavutetaan PWM-arvolla 255, mutta matalin nopeus riippuu useista tekijöistä, kuten moottorin ominaisuuksista, kuormasta, PWM-signaalin laadusta ja ympäristöolosuhteista. Tämä arvo voidaan määrittää käytännön testeillä ja tarvittaessa optimoida erilaisin menetelmin.

Maksimikiihtyvyys saavutetaan, kun moottori lähtee paikallaanolotilasta (PWM = 0) ja sille asetetaan heti maksimisyöttö (PWM = 255). Tällöin moottori toimii täydellä teholla alusta alkaen, jolloin kiihtyvyys on suurimmillaan.

Testaamme ohjainta yksinkertaisesti lähettämällä halutun pulssisuhteen (duty cycle), jolloin moottorit pyörivät tasajännitteellä ilman takaisinkytkentää. Tämä mahdollistaa ohjausjärjestelmän perustoimintojen tarkistamisen ennen suljetun piirin hallinnan käyttöönottoa.

Liitämme moottoriohjaimen USB-kaapelilla tietokoneeseen, jolloin sitä voidaan ohjata sarjaliikenteen (serial communication) avulla. Tämä yhteys mahdollistaa yksinkertaisen ja luotettavan tavan lähettää ohjauskomentoja moottoriohjaimelle.

**pwm.py**

```python
import serial
import time

try:
    speed = 100
    arduino = serial.Serial("/dev/ttyACM0", 115200, timeout=1)
    time.sleep(2.0) # odotetaan etta linja on varmasti auki
    arduino.write(("PWM;%s;%s;\n"%(speed,speed)).encode()) #annetaan pwm ohje kummallekin moottorille
    if arduino.isOpen():
        while(True):
            print("Moottorit pyorivat yha")
            time.sleep(3.0)
            
except KeyboardInterrupt:
        print("\nOhjelma keskeytetty, pysaytetaan moottorit.")
        arduino.write(("PWM;0;0").encode())
        
finally:
        print("Lopetetaan ohjelma")
```

Kummallekin moottorille lähetetään ohjausarvo 100, joka vastaa noin 40 % pulssisuhdetta ja pyörittää moottoreita samaan suuntaan. On kuitenkin tärkeää huomioida, että jos moottorit on asennettu robottiin differentiaaliajotyyppisesti (vastakkain), tämä ohjausarvo saa moottorit pyörimään vastakkaisiin suuntiin, jolloin robotti pyörii paikallaan eikä liiku eteen- tai taaksepäin. Tämä ilmiö on oleellista huomioida moottoreiden ja ohjausarvojen synkronoinnissa.

```bash
# Ajetaan ohjelma komennolla
python3 pwm.py
```
##### Jos mitään ei tapahdu, tarkista seuraavat asiat:

1. Liitokset: Varmista, että kaikki liitokset ovat tiukasti kiinni, erityisesti USB-kaapeli ja mahdolliset moottoriohjaimen virtakaapelit.
2. Virransyöttö: Tarkista, että moottoriohjaimeen on kytketty virta ja että virtalähde on toiminnassa.
3. Ohjausarvo: Moottorityypistä ja sen ominaisuuksista riippuen annettu ohjausarvo (esim. 100) saattaa olla liian pieni, jotta moottori jaksaisi pyöriä. Kokeile kasvattaa ohjausarvoa asteittain ja tarkkaile, alkaako moottori toimia.

Jos ongelmat jatkuvat, tarkista myös, että käytettävä sarjaliikenneprotokolla ja konfiguraatiot (esim. baud rate) ovat oikeat ja yhteensopivat moottoriohjaimen asetusten kanssa.

### Takaisinkytkentä

Teemme koodiin pienen lisäyksen, jonka avulla tulostamme moottoriohjaimelta saadun vastauksen. Vastaus saapuu muodossa:

```motor1_encoder;motor2_encoder;motor1_speed;motor2_speed;motor1_pwm_set;motor2_pwm_set```

Tämä lisäys mahdollistaa sen, että voimme tarkistaa moottorien encoder-arvot, nopeudet ja PWM-asetukset suoraan koodin tulosteista. Koodissa on myos kommenttimerkilla poistettu rivi, joka saa moottorien nopeuden vaihtelemaan satunnaisesti mielenkiinnon vuoksi.

```python
import serial
import time
import random
try:

    speed = 100
    arduino = serial.Serial("/dev/ttyACM0", 115200, timeout=1)
    time.sleep(2.0)
    if arduino.isOpen():
        while(True):
            # speed += random.randint(-10,10) # Ota kommenttimerkki pois, jos haluat kokeilla nopeuden muuttamista satunnaisesti.
            print(f"Vaihdetaan nopeus = {speed}")
            arduino.write(("PWM;%s;%s;\n"%(speed,speed)).encode())
            time.sleep(0.5) # nöytteenottovälin pituus

            if arduino.inWaiting()>0:
                answer=arduino.readline()
                print(answer)
                arduino.flushInput()
            
except KeyboardInterrupt:
        print("\nOhjelma keskeytetty, pysaytetaan moottorit.")
        arduino.write(("PWM;0;0").encode())
        
finally:
        print("Lopetetaan ohjelma")
```

Ja kun ajamme ohjelman, saamme vastauksia

```
python pwm.py

b'-552;-518;169;158;100;100\n'
b'-1324;-1237;179;166;100;100\n'
b'-2103;-1963;179;167;100;100\n'
b'-2884;-2692;180;168;100;100\n'
b'-3666;-3422;181;168;100;100\n'
b'-4449;-4154;180;168;100;100\n'
b'-5233;-4887;180;169;100;100\n'
b'-6018;-5621;181;169;100;100\n'
b'-6802;-6356;181;170;100;100\n'
b'-7588;-7093;181;170;100;100\n'
b'-8372;-7828;181;170;100;100\n'
b'-9158;-8564;181;169;100;100\n'
b'-9946;-9300;181;169;100;100\n'
b'-10735;-10037;181;169;100;100\n'
b'-11523;-10772;182;169;100;100\n'
b'-12312;-11508;182;169;100;100\n'
b'-13102;-12245;182;170;100;100\n'
```

Saaduista tiedoista voidaan muodostaa käyrät, jotka selkeyttävät tulosten tulkintaa. Käyrien avulla voimme varmistaa, että molemmat encoderit toimivat odotetusti, ja havaita, että moottori #2 pyörii hieman hitaammin annetulla ohjausarvolla, mikä johtaa myös hieman lyhyempään kuljettuun matkaan. Visualisointi tarjoaa selkeän tavan arvioida järjestelmän toimintaa sekä tunnistaa mahdolliset poikkeamat tai hienosäätöä vaativat kohdat.

Arvojen analysointi on helppoa kopioimalla ne Excel-taulukkoon ja luomalla viivagraafi. Kokeilemalla eri arvoja voit havainnoida, miten ne vaikuttavat moottorin pyörimiseen.

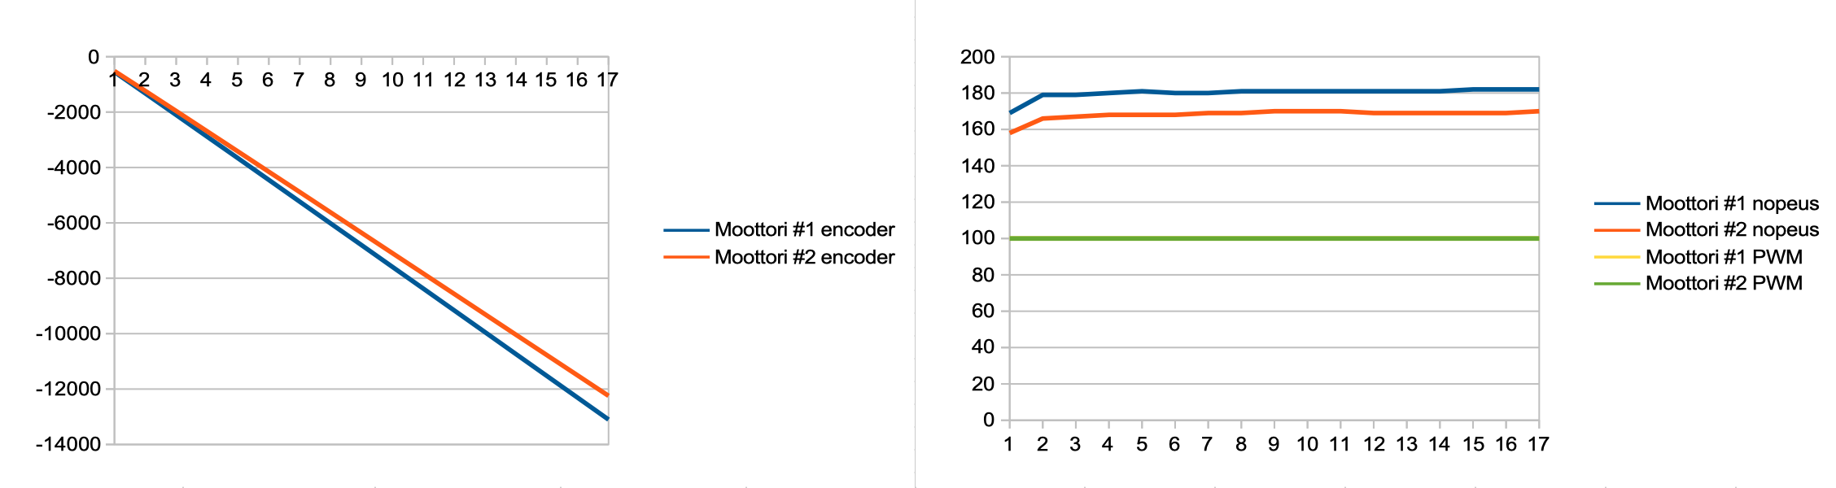
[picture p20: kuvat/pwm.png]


Mikäli encoder-arvot eivät päivity, vaikka moottori pyörii, tarkista kytkennät huolellisesti. Jos encoder-arvot näyttävät väärään suuntaan (esim. moottorit pyörivät samaan suuntaan mutta arvot vähenevät yhdellä encoderilla), signaalit voivat olla kytketty ristiin. Korjaa tällöin kytkennät vaihtamalla väärin kytketyt signaalijohdot oikein päin.

### PID Säädin

PID säätimen toimintaan voit tutustua tutustumalla arduinoissa olevaan koodiin.

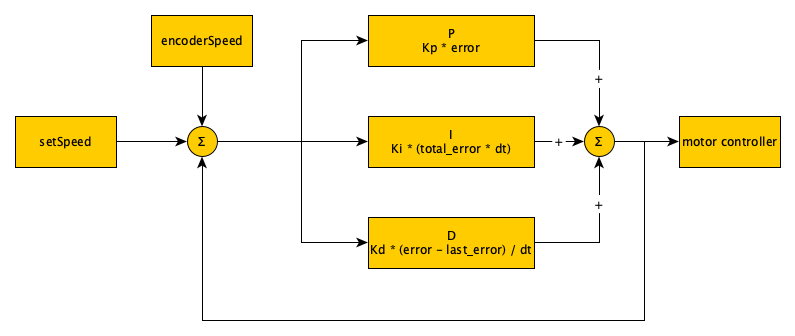
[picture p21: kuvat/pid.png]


Kun on varmistettu, että moottori pyörii odotetusti PWM-ohjauksella ja encoderit palauttavat oikeanlaisia arvoja, voidaan siirtyä käyttämään PID-säädintä. PID-säätimen avulla saavutamme tarkemman nopeudenhallinnan, jolloin moottorit pyörivät halutulla nopeudella riippumatta kuormituksesta tai muista häiriötekijöistä. Tämä vaihe mahdollistaa järjestelmän suorituskyvyn optimoinnin ja luo perustan tarkemmalle ohjaukselle.

SPD;127;127; tarkoittaa, että kumpikin moottori pyrkii pitämään nopeuden 127

Moottoriohjaimessa on SPD-komennolle sisäänrakennettu turvaominaisuus, joka pysäyttää moottorin automaattisesti, jos se ei saa uutta ohjetta määritetyn ajan sisällä (oletuksena 3 sekuntia). Tämä ominaisuus varmistaa, että moottori ei jää pyörimään hallitsemattomasti mahdollisten virhetilanteiden tai ylemmän tason ohjausjärjestelmän häiriöiden vuoksi. Näin moottori pysähtyy turvallisesti, mikä lisää järjestelmän luotettavuutta ja suojaa sekä laitteistoa että ympäristöä.

Voimme tehdä yksinkertaisen muutoksen korvaamalla PWM-komennon SPD-komennolla, jolloin moottoriohjain huolehtii itse PWM-asetusten laskemisesta saavuttaakseen halutun nopeuden.

```python
import serial
import time

try:
	speed = 100
	arduino = serial.Serial("/dev/ttyACM0", 115200, timeout=1)
	time.sleep(2.0)
	if arduino.isOpen():
	  while True:
	    arduino.write(("SPD;%s;%s;\n"%(speed,speed)).encode())
	    time.sleep(0.5) # naytteenottovali, voit kokeilla miten lyhyempi vali vaikuttaa ohjautuvuuteen.

	    if arduino.inWaiting()>0:
	      answer=arduino.readline()
	      print(answer)
	      arduino.flushInput()
	      
except KeyboardInterrupt:
	print("Pysaytetaan moottorit")
	arduino.write(("SPD;0;0").encode())
finally:
	print("Lopetetaan ohjelma")
```

Ja vastauksen saamme samalla tavalla kuin PWM-komennon kanssa, mutta nyt voimme suoraan havaita, että moottorin nopeus pyrkii pysymään annetussa arvossa, ja PWM-arvo vaihtelee automaattisesti moottoriohjaimen toimesta. Tämä vahvistaa, että moottoriohjain säätelee PWM-arvoja dynaamisesti kompensoidakseen kuorman tai muiden olosuhteiden muutoksia, mikä johtaa tasaisempaan nopeudenhallintaan.

```
b'-510;-498;141;135;20;32\n'
b'-926;-924;105;104;52;58\n'
b'-1354;-1354;101;100;57;61\n'
b'-1787;-1786;101;102;57;60\n'
b'-2216;-2216;99;99;58;62\n'
b'-2648;-2645;100;97;57;63\n'
b'-3081;-3075;101;98;57;62\n'
b'-3511;-3507;99;100;58;61\n'
b'-3945;-3939;100;100;57;62\n'
b'-4375;-4372;100;100;57;61\n'
b'-4806;-4802;99;100;58;61\n'
b'-5236;-5233;99;101;58;61\n'
b'-5668;-5665;101;100;57;61\n'
b'-6102;-6099;100;100;57;61\n'
b'-6532;-6527;100;99;57;62\n'
b'-6964;-6960;99;99;58;62\n'
b'-7399;-7393;101;99;56;61\n'
```

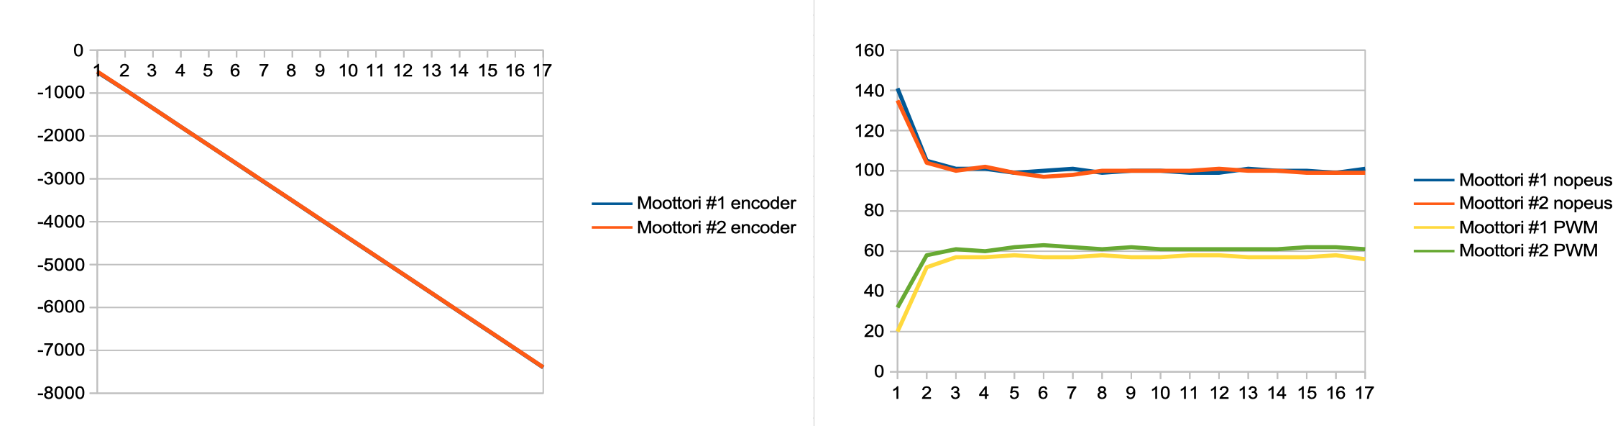
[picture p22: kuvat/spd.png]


Kun vertaamme tasaisen PWM-säädön käyriä PID-säätimeltä saatujen käyrien kanssa, voimme havaita merkittävän parannuksen: PID-säätimen avulla moottorien nopeudet pysyvät tarkemmin asetetussa arvossa. Lisäksi näemme, että PWM-asetusarvot eroavat moottorien välillä siten, että hitaammin pyörivä moottori #2 vaatii hieman enemmän tehoa pysyäkseen samassa vauhdissa moottorin #1 kanssa. Tämä osoittaa PID-säätimen tehokkuuden nopeuksien tasaamisessa ja moottorien yksilöllisten eroavaisuuksien kompensoinnissa.

Käyrän alussa näkyvä omituisuus, jossa nopeus on suuri ja PWM-arvo pieni, johtuu siitä, että PID-säätimen ensimmäiset säätöarvot eivät ehdi tallentua kaavioon, kun käytämme 0,5 sekunnin viivettä tulosten tulostamisessa. Tämä viive aiheuttaa sen, että kaavion alkuhetken data ei täysin heijasta säätimen todellista käyttäytymistä.

Kun pienennämme näytteenottovälin 0,1 sekuntiin, saamme kyseisen tapahtuman paremmin näkyviin, ja näin PID-säätimen toiminta alkuvaiheessa voidaan analysoida tarkemmin. Tämä auttaa havaitsemaan mahdolliset poikkeamat tai optimointitarpeet.

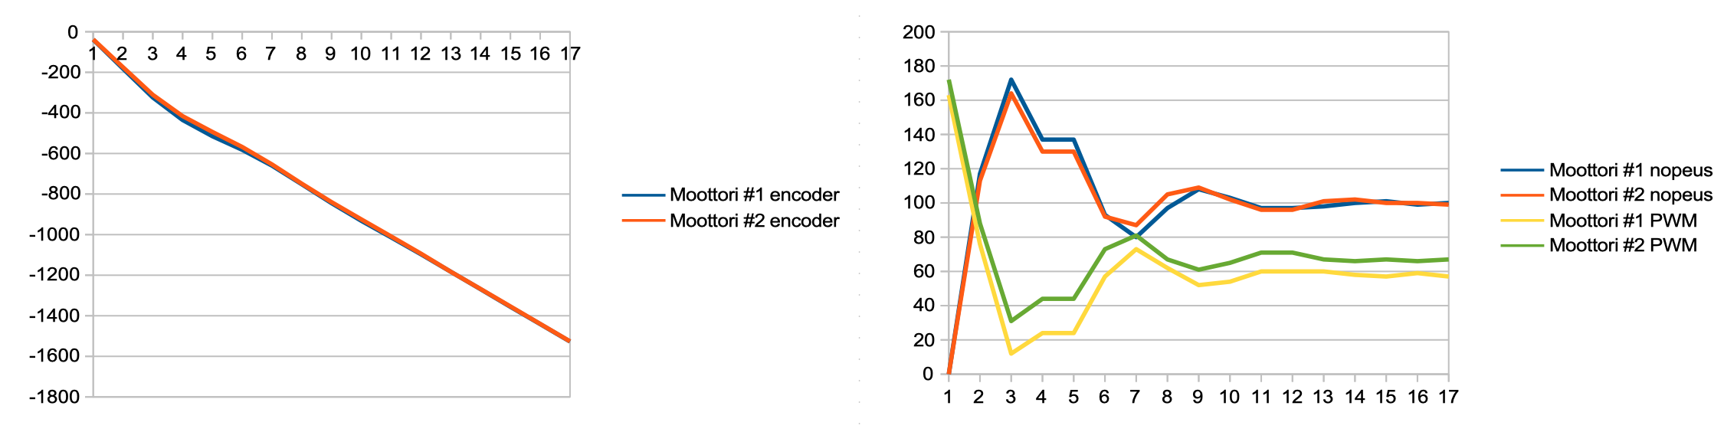
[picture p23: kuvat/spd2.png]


Sovellamme samaa 0,1 sekunnin näytteenottoväliä myös PWM-säädön alussa, jotta saamme paremman käsityksen järjestelmän käyttäytymisestä heti käynnistyksessä. Tämä auttaa vertaamaan PWM-säätöä ja PID-säädintä tarkemmin alusta alkaen ja havaitsemaan esimerkiksi transienttivaiheessa tapahtuvat ilmiöt, kuten moottorin kiihtymisen ja PWM-arvojen muutokset.

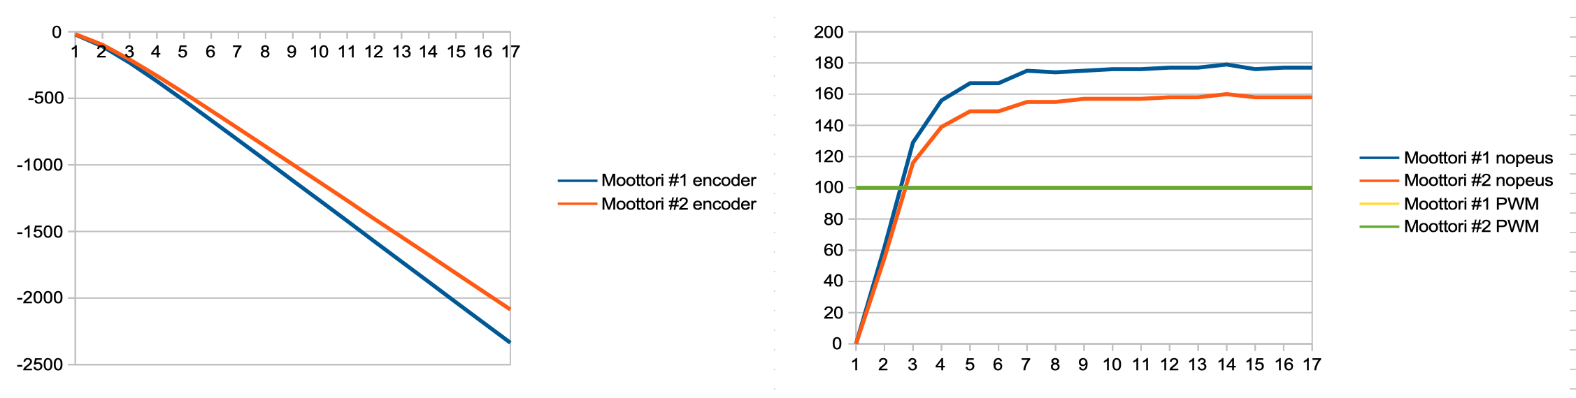
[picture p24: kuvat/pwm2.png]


Kuitenkin on tärkeää huomioida käytetyn moottoriohjaimen rajoitukset: liian tiheä datan kerääminen voi kuormittaa ohjainta ja hidastaa itse PID-säätimen toimintaa. Tällöin järjestelmän suorituskyky voi heikentyä, mikä voi johtaa virheellisiin johtopäätöksiin PID-piirin toimivuudesta. Näin ollen näytteenottovälin valinnassa on löydettävä tasapaino tarkkuuden ja järjestelmän toimivuuden välillä. Jos ohjain alkaa hidastua, tulisi harkita harvempaa näytteenottoa tai optimoida datan keruuta välttämällä turhia pyyntöjä.

### Vaihtoehtoja

Kun tavoitteena on saavuttaa moottoriohjaimelta parempaa suorituskykyä, FPGA (Field Programmable Gate Array) on erinomainen valinta suorittimeksi. FPGA mahdollistaa useiden tehtävien rinnakkaisen suorittamisen, mikä takaa nopean ja tehokkaan toiminnan. Tämä on erityisen hyödyllistä moottoriohjauksen kriittisissä tehtävissä, kuten PID-säätimessä, jossa suorituskyvyn on pysyttävä vakaana ja tarkkana riippumatta muista järjestelmän toiminnoista. FPGA:n rinnakkaisuus tekee siitä ihanteellisen valinnan korkean suorituskyvyn vaativiin sovelluksiin.

Jos projektin budjetti sallii, markkinoilla on myös saatavilla laaja valikoima kaupallisia moottoriohjaimia, jotka ovat hyvin testattuja ja toimintavarmoja. Näihin kuuluu yksinkertaisia DC-moottoriohjaimia, tarkkoja servo-ohjaimia ja monipuolisia robotiikan ohjausjärjestelmiä. Useimmat näistä tuotteista tarjoavat kattavan dokumentaation, teknisen tuen ja valmiit integraatiot esimerkiksi ROS-järjestelmään, mikä tekee niistä luotettavan ja helppokäyttöisen ratkaisun. Korkean laadun ja toimintavarmuuden vastapainona on usein korkeampi hinta, joten näiden tuotteiden valinta riippuu projektin tarpeista ja budjetista.

-
Nomga Oy - SeAMK - ROS 2 ja moottorinohjaus: PWM-signaalista robottien liikkeenhallintaan

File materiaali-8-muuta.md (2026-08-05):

### Arduino

Arduinon koodi löytyy hakemistosta ``/opt/nomga/arduino/``

```bash
# Käännä koodi
compile.sh

# Lataa arduinoon
upload.sh
```

### ROS2

ROS2 koodit löytyvät hakemistosta ``/opt/nomga/ros2/``

Toimintaa voi testata

```bash
source /opt/nomga/ros2_ws/install/setup.bash
```

Hakemistosta ``/opt/nomga/ros2_ws/src/diffdrive/diffdrive/`` löytyy vielä ``pi_led.py`` tiedosto, joka sytyttää Raspberry PI GPIO23:een kytketyn ledin kun ajetaan ``ros2 launch diffdrive diffrive.launch.py`` ja kaikki on valmista. Huomaa, että kyseessä ei ole varsinainen ROS2 paketti eli sitä ei ajeta ros2 run ... komennolla.

Näiden .md tiedostojen jakaminen suljetussa lähiverkossa onnistuu code-kansiosta löytyvällä python-skriptillä serve_md_files.py, jonka hakemiston alihakemistossa /markdown_files on kopioituna nämä md-tiedostot.

### Foxglove Studio graafinen käyttöliittymä
Tässä materiaalissa on viitattu RVIZ2-nimisen visualisointityökalun käyttämiseen. Se ei kuitenkaan onnistu, mikäli käytössä ei ole graafisella työpöydällä varustettua, samassa ROS2-verkossa toimivaa Ubuntu-konetta. Mikäli haluat visualisoida liikkuvaa robottia myös ruudulla, voit käyttää [Foxglove](https://foxglove.dev/robotics/ros)-nimistä käyttöliittymäohjelmistoa, jota on mahdollista ajaa myös suoraan nettipalvelussa (eli asentamatta omalle koneelle Foxglove-serveriä).

Tähän tarvitset [Foxglove Bridge](https://docs.foxglove.dev/docs/connecting-to-data/ros-foxglove-bridge)-nimisen ohjelman, joka lähettää ROS2-ympäristön viestit Websocket-muodossa [Foxglove Studio](https://studio.foxglove.dev) palveluun. Palvelun käyttämiseksi sinun täytyy luoda käyttäjätunnus tai kirjautua siihen esimerkiksi Microsoft-tunnuksellasi.

Asennettuasi Foxglove Bridgen tietokoneellesi (joka on samassa ROS2-verkossa SeBotin Raspberry Pin kanssa), voit käynnistää sen vakioasetuksilla komennolla
```bash
ros2 launch foxglove_bridge foxglove_bridge_launch.xml
```

Päästyäsi sisään Foxglove Studio -palveluun, voit nyt luoda yhteyden oman robottisi ROS2-ympäristöön ottamalla käyttöön [websocket-kanavan](https://docs.foxglove.dev/docs/connecting-to-data/frameworks/ros2#foxglove-websocket) 

Foxglove Studio

> Valitse 'Open data source' -> Foxglove WebSocket -> syötä Foxglove bridge -serverisi URL (eli käytännössä localhost:8765).

Nyt pääset käsiksi ROS2-ympäristöösi.

Halutessasi nähdä URDF-tiedoston mukaisen visualisoinnin, käynnistä ``robot_state_publisher`` (materiaali-3-URDF tai materiaali-4-diffdriven mukainen launch-tiedosto) ja syötä oheinen komento päätteeseen:
```bash
ros2 param set /robot_state_publisher robot_description "$(cat ~/ros2_ws/src/my_package/urdf/my_robot.urdf) # varmistetaan että robot_state_publisherilla on haluttu URDF-tiedosto parametrinään
```

Nyt robotin kuvaus on Foxglove Studion käytettävissä.

-
Nomga Oy - SeAMK - ROS 2 ja moottorinohjaus: PWM-signaalista robottien liikkeenhallintaan

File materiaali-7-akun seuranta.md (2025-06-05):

## Ekstra: Akun jännitteen seuranta ja hälytysvalo
LiPo-akun kunto heikkenee nopeasti, jos kennokohtainen jännite laskee liian alas. Jos raja-arvoksi otetaan 3,3V/kenno, niin SeBotissa käytettävän kolmikennoisen akun jännite ei saisi laskea alle noin 10V (ellei käytetä kehittyneempää kennokohtaista jännitteenseurantaa). Kehitetään SeBotin toiminnallisuuksia siten, että jännitteen laskiessa alle annetun tason hälytysvalo syttyy:
1) Tehdään jännitteenjakokytkentä, jonka avulla Arduino voi lukea moottoritietojen ohella myös akun jännitettä. 
2) Syötetään tämä tieto osana moottoreiden tilasta kertovaa merkkijonoa Raspberrylle, jossa motordriver-node parsii tiedon osaksi /motor_data topicia. 
3) Välitetään tieto erillisellä nodella omaan /battery_level topiciinsa ja
4) seurataan jännitteen tasoa nodella, joka toimittaa tiedon hälytystilan statuksesta /battery_alert topiciin ja sytyttää hälytysvalon.

### Jännitteenjakokytkentä
Arduinon analogisisääntulonastalle ei saa syöttää yli 5V jännitettä. Akun nimellisjännite on 12V eli se tulee skaalata siten, että 12V jännite näkyy Arduinolle hieman alle 5V jännitteenä. Tämä on kätevintä tehdä yksinkertaisella [jännitteenjakokytkennällä](https://fi.wikipedia.org/wiki/J%C3%A4nnitteen-_ja_virranjakos%C3%A4%C3%A4nt%C3%B6).

Jännitteenjako

Kuva: Jännitteenjakokytkentä ja tarvittavat laskukaavat.

Vastukset R1 ja R2 tulee valita siten, että niiden keskinäinen suhde antaa jännitteeksi U2 kaikissa tapauksissa alle 5V jännitteen Arduinon nastalle A0. Toiseksi kokonaisvastuksen on syytä olla varsin suuri, jotta tämä "turha" virrankulutus jäisi mahdollisimman pieneksi.

Jos vastukseksi R1 valitaan 10 k $\Omega$ ja akun maksimijännite on U = 12,6V, niin laskennallisesti vastuksen R2 tulee olla 6,6 k $\Omega$. Haluamme kuitenkin hieman varmuusmarginaalia, joten hyvä valinta on R2 = 4,7 k $\Omega$. Tällöin U2_max = U_max * R2/(R1+R2) = 4,0 V.

### Arduino

Lisätään Arduinon motorcontroller.inu-tiedostoon tieto A0-nastan käyttämisestä analogisisääntulona, siltä luetun arvon lukeminen ja skaalaaminen jännitearvoksi ``ReadBatteryVoltage()``-funktiolla ja tämän jännitearvon lähettäminen osana muuta Raspberrylle toimitettavaa merkkijonoa.

Halutessasi voit mitata käyttämäsi vastusten resistanssin yleismittarilla jännitemittauksen tuloksen tarkentamiseksi.

**/opt/nomga/arduino/motorcontroller/motorcontroller.ino**
```c
#include "Motor.h"

const int voltagePin = A0;         // Analoginen sisääntulo nastassa A0
const float R1 = 9820.0;          // nimellisvastus 10k ohmia
const float R2 = 4720.0;           // nimellisvastus 4.7k ohmia
const float voltageScale = (R1 + R2) / R2; // ~3.13
...
```

```c
...
void sendData() {
  Serial.print(motor1.getEncoder());
  Serial.print(";");
  Serial.print(motor2.getEncoder());
  Serial.print(";");
  Serial.print(motor1.getSpeed());
  Serial.print(";");
  Serial.print(motor2.getSpeed());
  Serial.print(";");
  Serial.print(motor1.getMotorSpeed());
  Serial.print(";");
  Serial.print(motor2.getMotorSpeed());
  Serial.print(";");
  Serial.print(readBatteryVoltage(), 2); // Akun jännite kahden desimaalin tarkkuudella
  Serial.print("\n");
}

float readBatteryVoltage() {
  int raw = analogRead(voltagePin);            // 0–1023
  float voltage = (raw / 1023.0) * 5.0;         // Muunnetaan jännitteeksi
  return voltage * voltageScale;               // Skaalataan varsinaiseksi jännitteeksi.
}
```

Tallenna tiedosto ja käännä ja lataa se Arduinon muistiin ajamalla komennot
```bash
/opt/nomga/arduino/compile.sh
/opt/nomga/arduino/upload.sh
```

### Jännitteen lukeminen ROS2-ympäristössä
Arduino syöttää nyt merkkijononsa viimeisenä kenttänä tiedon jännitteestä. SeBotin arkkitehtuurissa tämän lukeminen kannattaa tehdä samassa yhteydessä kuin moottoreiden tietojen lukeminen eli ``motordriver`` nodessa. Tämä tieto voidaan julkaista samalla kertaa muun ``/motor_data`` topicin yhteydessä, jos päivitämme sen käyttämän tietotyypin yhdellä lisäkentällä. (Toinen, lopulta suoraviivaisempi vaihtoehto olisi julkaista akun jännitetieto suoraan omassa nodessaan. Tässä haluamme kuitenkin havainnollistaa topicien uudelleenjulkaisua erillisessä nodessa. Omana harjoituksenasi voit miettiä, miten oikaista tämän välivaiheen ohi.)

#### MotordriverMessage päivitys
Päivitetään ensin tietotyyppi lisäämällä yksi ``float32`` tyyppinen kenttä tiedoston loppuun.
**~/ros2_ws/src/motordriver_msgs/msg/MotordriverMessage.msg**
```
int32 encoder1
int32 encoder2
int32 speed1
int32 speed2
int32 pwm1
int32 pwm2
float32 battery
```

#### motordrive noden päivitys
Tämän jälkeen muokataan ``motordriver`` nodea siten, että se huomioi myös tämän lisätyn kentän
**~/ros2_ws/src/motordriver/motordriver/motordriver.py**
```python
... 
    # luokan MotordriverNode konstruktoriin päivitetään mukaan jännitesimulointi, jos ajetaan simulaatiossa.
    # jos simulation parametria ei löydy niin oletuksena se on False
    self.declare_parameter('simulation', False)
    self.simulation = self.get_parameter('simulation').value
    self.get_logger().info(f'Käynnistetään motor_controller simulaatiossa: {self.simulation}')
    if self.simulation:
      self.arduino = SimSerial()
      self.voltageDifference = 0
      self.startingVoltage = 12.6
    else:
      self.arduino = serial.Serial("/dev/ttyACM0", 115200, timeout=1)
      if not self.arduino.isOpen():
        raise Exception("Ei yhteyttä moottoriohjaimeen")
...
  def timer_callback(self):
    # Create a message
    if self.msg != "x\n":
        self.arduino.write(self.msg.encode())

    if self.timercount == 11:
        if self.msg == "x\n":
            self.arduino.write(self.msg.encode())
        self.msg = "x\n"

        self.timercount = 0
        if self.arduino.inWaiting()>0:
          while self.arduino.inWaiting()>0: 
            answer=self.arduino.readline().decode("utf8").split(";")
            if(self.simulation):
              self.voltageDifference -= 0.001 
              answer.append(float(self.startingVoltage+self.voltageDifference))
          msg = MotordriverMessageBattery()
          
          try:
            msg.encoder1 = int(answer[0])
            msg.encoder2 = int(answer[1])
            msg.speed1 = int(answer[2])
            msg.speed2 = int(answer[3])
            msg.pwm1 = int(answer[4])
            msg.pwm2 = int(answer[5])
            msg.battery = float(answer[6])
            # Publish the message
            self.publisher.publish(msg)
          except Exception as err:
            self.get_logger().info(f'Virhe: {err}')
            pass

    self.timercount += 1
...
```
#### Uusi ``battery``-paketti
Harjoituksen vuoksi teemme uuden ROS2-paketin, johon luomme kaksi erillistä nodea:
1) ``battery_republish`` joka poimii akun jännitetiedon ja julkaisee sen omassa topicissaan ``/battery_voltage`` ja
2) ``battery_alert`` joka lukee kyseistä topicia ja havaitessaan jännitteen laskeneen alle asetetun hälytysrajan julkaisee ``/battery_alert`` topicissa asiasta hälyttävää viestiä. Lisäksi node sytyttää hälytysvalon.

Luodaan uusi paketti ``battery``
```bash
cd ~/ros2_ws/src/
ros2 pkg create --build-type ament_python battery
cd ~/ros2_ws/src/battery/battery
```

Luodaan kyseiseen hakemistoon kaksi tiedostoa:
**~/ros2_ws/src/battery/battery/battery_republish.py**
```python
import rclpy
from rclpy.node import Node

from std_msgs.msg import String

import time

from motordriver_msgs.msg import MotordriverMessage

from std_msgs.msg import Float32

class BatteryRedirector(Node):
    def __init__(self):
        super().__init__('battery_redirector')
        self.declare_parameter('battery_check_interval', 10.0) # Parametri jännitteen luvun aikavälille, sekuntia.
        self.publish_interval = self.get_parameter('battery_check_interval').value

        self.sub = self.create_subscription(MotordriverMessage, '/motor_data', self.callback, 10)
        self.pub = self.create_publisher(Float32, '/battery_voltage', 10)
        self.previous_time = time.time()
        self.get_logger().info(f"Akun jännitteen lukuaika asetettu arvoon {self.publish_interval:.2f} s")

    def callback(self, msg):
        time_now = time.time()
        time_interval = time_now - self.previous_time
        if time_interval > self.publish_interval:
            battery_msg = Float32()
            battery_msg.data = msg.battery
            self.pub.publish(battery_msg)
            self.previous_time = time_now

def main(args=None):
  rclpy.init(args=args)
  batteryredirector_node = BatteryRedirector()
  try:
    rclpy.spin(batteryredirector_node)
  except KeyboardInterrupt:
    pass
  finally:
    batteryredirector_node.destroy_node()
    if rclpy.ok():
      rclpy.shutdown()

if __name__ == '__main__':
  main()

```

**~/ros2_ws/src/battery/battery/battery_alert.py**
```python
import rclpy
from rclpy.node import Node
from std_msgs.msg import String
import time
from std_msgs.msg import Bool, Float32

import lgpio

class BatteryAlert(Node):
    def __init__(self):
        super().__init__('battery_alert_node')

        self.declare_parameter('threshold', 12.0) # Oletusarvo 12.0 V, tämä tulee nopeasti vastaan täydelläkin akulla aloitettaessa.
        self.threshold = self.get_parameter('threshold').get_parameter_value().double_value
        self.get_logger().info(f"Akun jännitteen alaraja asetettu arvoon {self.threshold:.2f} V")
        
        self.sub = self.create_subscription(Float32, '/battery_voltage', self.voltage_callback, 10)
        self.sub_alert = self.create_subscription(Bool, '/battery_alert', self.alert_callback, 10)
        self.pub = self.create_publisher(Bool, '/battery_alert', 10)
        self.previous_alert_state = False

        # Julkaistaan yhden kerran oletuksena /battery_alertissa False, jotta siellä näkyy varmasti jotain.
        battery_alert_msg = Bool()
        battery_alert_msg.data = self.previous_alert_state
        self.pub.publish(battery_alert_msg)
    
        # Määritellään GPIO nasta hälytys-LEDille
        self.LED_PIN = 18
        # Valitaan GPIO-siru (vakio Raspberry Pille)
        self.chip = lgpio.gpiochip_open(4)
        # Asetetaan LED_PIN ulostuloksi
        lgpio.gpio_claim_output(self.chip, self.LED_PIN)
        # Alustetaan LED_PIN alas (nollaksi)
        lgpio.gpio_write(self.chip, self.LED_PIN, 0)

    # Tämä callback kutsutaan kun /battery_alert topiciin tulee viestejä.
    def alert_callback(self, msg):
        if msg.data == True:
            pass
            lgpio.gpio_write(self.chip, self.LED_PIN, 1)  
        else:
            pass
            lgpio.gpio_write(self.chip, self.LED_PIN, 0)  

    def voltage_callback(self, msg):
        if msg.data < self.threshold:
            alert_state = True
        else:
            alert_state = False
        
        if self.previous_alert_state != alert_state: # Julkaistaan /battery_alert tieto vain jos se on muuttunut edellisestä.
            battery_alert_msg = Bool()
            battery_alert_msg.data = alert_state
            self.pub.publish(battery_alert_msg)
            self.previous_alert_state = alert_state

def main(args=None):
  rclpy.init(args=args)
  batteryalert_node = BatteryAlert()
  
  try:
    rclpy.spin(batteryalert_node)
  except KeyboardInterrupt:
    pass

  finally:
      batteryalert_node.destroy_node()
      lgpio.gpio_write(batteryalert_node.chip, batteryalert_node.LED_PIN, 0)
      lgpio.gpiochip_close(batteryalert_node.chip)
      if rclpy.ok():
          rclpy.shutdown()

if __name__ == '__main__':
  main()

```

Päivitetään vielä ``setup.py`` jotta saamme käynnistettyä nodet ``ros2 run`` komennolla.

**~/ros2_ws/src/battery/setup.py**
```python
from setuptools import find_packages, setup

package_name = 'battery'

setup(
    name=package_name,
    version='0.0.0',
    packages=find_packages(exclude=['test']),
    data_files=[
        ('share/ament_index/resource_index/packages',
            ['resource/' + package_name]),
        ('share/' + package_name, ['package.xml']),
    ],
    install_requires=['setuptools'],
    zip_safe=True,
    maintainer='sebot',
    maintainer_email='sebot@todo.todo',
    description='TODO: Package description',
    license='Apache-2.0',
    tests_require=['pytest'],
    entry_points={
        'console_scripts': [
            'battery_republish = battery.battery_republish:main',
            'battery_alert = battery.battery_alert:main',
        ],
    },
)
```
Yhdistä GPIO 18 nastaan haluamasi LED ja sen etuvastus. Tämä voi olla kätevää yhdistää ``materiaali-4-diffdrive``-osiossa mainitun "kaikki valmista LED:in" kanssa siten, että käytetään samaa maa-nastaa 14, joka on nastojen GPIO18 ja GPIO23 välissä, katso kuva alta.
Raspberry Pi 5 GPIO nastojen järjestys
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

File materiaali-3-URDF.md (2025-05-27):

### URDF

URDF-tiedosto (Unified Robot Description Format) on XML-pohjainen tiedostomuoto, joka sisältää robotin rakenteellisen ja kinematiikkaan liittyvän kuvauksen. Se määrittelee esimerkiksi robotin rungot, nivelet, materiaalit ja mittasuhteet.

kääntösäde

Malli koostuu nivelistä ja linkeistä. Nivelet voivat olla joko kiinteitä tai liikkuvia (kiinteästi paikallaan olevat linkit kuten anturit ja liikkuvat linkit kuten käsivarsi tai pyörät). Kun robottiin lisätään esimerkiksi LIDAR ja 3D-kamera, pistepilvet ja muu sensoridata saadaan yhteiseen koordinaatistoon, jolloin ne kuvaavat samaa ympäristöä.

URDF-mallin avulla voidaan visualisoida ja simuloida robotin rakennetta ja liikettä työkaluissa kuten RViz ja Gazebo.

Ennen seuraava vaihetta moottorinohjauksessa, luodaan malli robotista. Tämä mahdollistaa robotin liikkeiden seuraamisen paremmin RVIz-työkalun avulla, mikä auttaa visualisoimaan ja ymmärtämään toimintaa paremmin.

Luodaan ``diffdrive`` -paketti

```bash
cd ~/ros2_ws/src
ros2 pkg create --build-type ament_python diffdrive
```

Tehdään hakemistot asetuksille ja launch -tiedostoille.

```bash
cd ~/ros2_ws
mkdir config
cd ~/ros2_ws/src/diffdrive
mkdir launch
```

> Jatkossa laskennoissa ei huomioida tässä määriteltyjä robotin geometrisia ominaisuuksia. Tämän vuoksi, jotta liike vastaisi todellisuutta, on varmistettava, että pyörien halkaisija ja niiden välinen etäisyys ovat laskelmissa yhtenevät sekä tässä määriteltyjen että todellisen laitteiston arvojen kanssa.

**~/ros2\_ws/config/robot.urdf**

```xml
<?xml version="1.0"?>

<robot name="robot model">
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

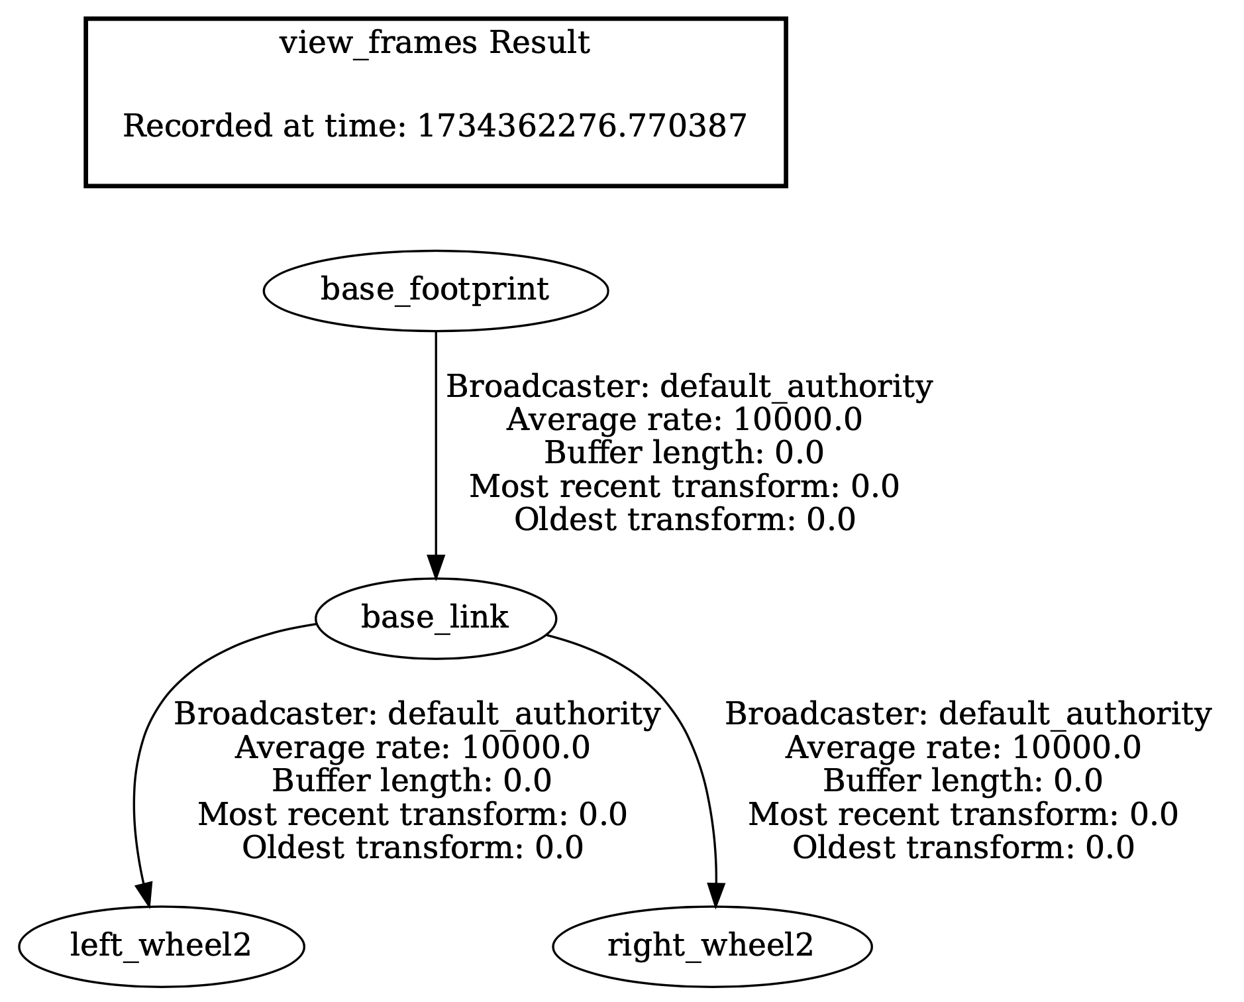
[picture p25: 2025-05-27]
code/md-publisher/markdown_files/kuvat/frames1.png

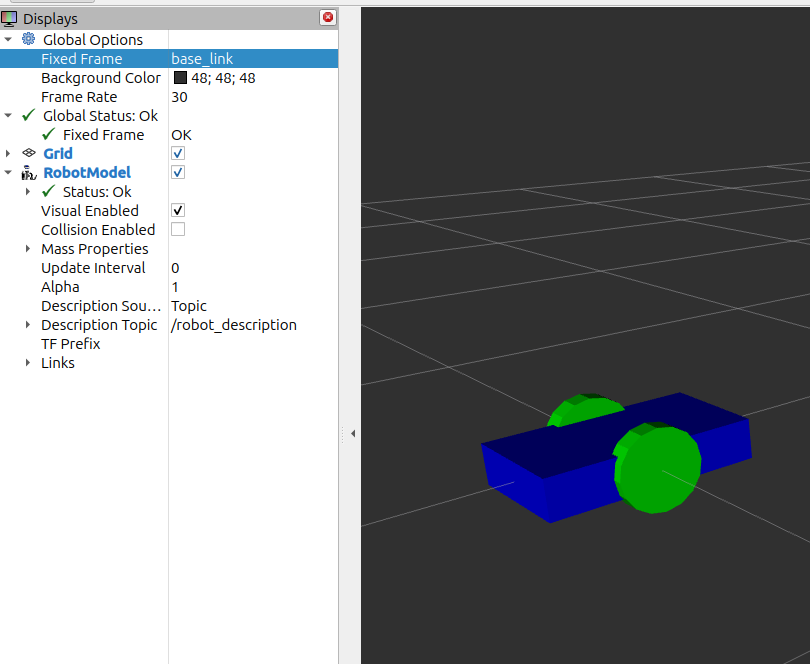
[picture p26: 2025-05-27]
code/md-publisher/markdown_files/kuvat/rviz_urdf.png

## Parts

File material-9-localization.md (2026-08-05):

# Multi-Sensor Fusion Localization

## System Integration: IMU, Wheel Encoder, UWB

This document describes the implementation of a localization system for a differential‑drive robot equipped with an IMU, wheel encoders, and an Ultra‑Wideband (UWB) system that replaces traditional GPS. By fusing high‑frequency relative motion data with absolute global references, stable and accurate navigation can be ensured for autonomous systems.

---

## 1. How the Sensors Work

### Inertial Measurement Unit (IMU)

- **Mechanism:**  
  Contains a 3‑axis gyroscope to measure angular velocity ($\omega$) and a 3‑axis accelerometer to measure linear acceleration ($a$).

- **Role:**  
  Provides high‑frequency data for rapid movement tracking and orientation. It serves as the “inner ear” of the robot.

- **Pros/Cons:**  
  Very fast response but suffers from “drift” (accumulated error) over time.

### Wheel Encoders (Odometry)

- **Mechanism:**  
  Sensors count the ticks of motor shafts to measure wheel rotation.

- **Role:**  
  Calculates linear displacement and heading through dead reckoning based on the robot’s kinematics (e.g., differential drive).

- **Pros/Cons:**  
  Reliable over short distances; performance degrades during wheel slippage or on carpet/uneven terrain.

### Ultra-Wideband (UWB)

- **Role:**  
  Provides absolute $X, Y, Z$ coordinates in the local UWB coordinate frame.

- **Pros:**  
  Achieves 2–10 cm accuracy; high immunity to multipath interference (distinguishes direct vs. reflected pulses); low power spectral density prevents interference with other radio signals.

- **Cons:**  
  Performance can degrade in environments with high metallic density or severe non‑line‑of‑sight conditions.

### LiDAR (Light Detection and Ranging)

- **Mechanism:**  
  Emits laser pulses to measure distances, creating a 360° point cloud of the environment.

- **Role:**  
  Performs “scan matching” against a known map to determine precise location relative to structural geometry.

- **Pros/Cons:**  
  Quite precise; can be confused by repetitive environments such as long, feature‑less corridors.

---

## 2. Sensor Setup

### 2.1 IMU (Xsens MTi 630)

This implementation uses the ROS 2 driver provided in the repository:  
<https://github.com/xsenssupport/Xsens_MTi_ROS_Driver_and_Ntrip_Client/tree/ros2>

### 2.2 UWB (Decawave DWM1001)

This implementation builds on the repository:  
<https://github.com/cliansang/uwb-tracking-ros/tree/ros2>  

The UWB system setup is further configured using helper scripts from:  
<https://github.com/SeAMKedu/DecawaveUWBwithPython>

### 2.3 2D LiDAR

- Driver for the RPLidar:  
  <https://github.com/Slamtec/rplidar_ros/tree/ros2>

After installing the drivers and required packages, the launch file in the `diffdrive` package is updated to run all sensors together with the robot. The built‑in `odom` node is kept only for low‑level wheel‑tick reading; the higher‑level odometry estimate is instead provided by the `robot_localization` package, which follows the ROS standard for multi‑sensor state estimation.

Below is the updated `diffdrive.launch.py` file:

```python
import os
from ament_index_python.packages import get_package_share_directory
from launch import LaunchDescription
from launch.actions import DeclareLaunchArgument, IncludeLaunchDescription
from launch.substitutions import LaunchConfiguration
from launch_ros.actions import Node
from launch.launch_description_sources import PythonLaunchDescriptionSource

def generate_launch_description():
    use_sim_time = LaunchConfiguration('use_sim_time', default='false')

    colcon_prefix_path = os.getenv('COLCON_PREFIX_PATH').split("/install")

    urdf_file_name = 'robot.urdf'
    urdf = os.path.join(
        colcon_prefix_path,
        'config',
        urdf_file_name)
    with open(urdf, 'r') as infp:
        robot_desc = infp.read()
    print(urdf)
    if not robot_desc.strip():
        raise RuntimeError("robot_description is empty! Check your URDF file.")

    xsens_launch = IncludeLaunchDescription(
        PythonLaunchDescriptionSource(
            os.path.join(
                get_package_share_directory('xsens_mti_ros2_driver'),
                'launch',
                'xsens_mti_node.launch.py'
            )
        )
    )

    ekf_launch = IncludeLaunchDescription(
        PythonLaunchDescriptionSource(
            os.path.join(
                get_package_share_directory('sebot_localization'),
                'launch',
                'ekf_dual.launch.py'
            )
        )
    )

    uwb_launch = IncludeLaunchDescription(
        PythonLaunchDescriptionSource(
            os.path.join(
                get_package_share_directory('uwb_tracking_ros2'),
                'launch',
                'uwb_tracking_dwm1001.launch.py'
            )
        )
    )

    return LaunchDescription([
        DeclareLaunchArgument(
            'use_sim_time',
            default_value='false',
            description='Use simulation (Gazebo) clock if true'),

        Node(
            package='robot_state_publisher',
            executable='robot_state_publisher',
            name='robot_state_publisher',
            output='screen',
            parameters=[{'use_sim_time': use_sim_time, 'robot_description': robot_desc}],
        ),

        Node(
            package='rviz2',
            executable='rviz2',
            name='rviz2',
            output='screen',
            arguments=[
                '-d',
                os.path.join(
                    get_package_share_directory('diffdrive'),
                    'rviz'   # change if the file name is different
                )
            ],
            parameters=[{'use_sim_time': use_sim_time}],
        ),

        Node(
            package='motordriver',
            executable='motordriver',
            name='motordriver_node',
            output='screen',
            parameters=[os.path.join(
                colcon_prefix_path,
                'config',
                'params.yaml')]
        ),

        Node(
            package='diffdrive',
            executable='odom',
            name='odom_node',
            output='screen',
            parameters=[os.path.join(
                colcon_prefix_path,
                'config',
                'params.yaml')]
        ),

        Node(
            package='diffdrive',
            executable='cmd_vel',
            name='cmd_vel_node',
            output='screen',
            parameters=[os.path.join(
                colcon_prefix_path,
                'config',
                'params.yaml')]
        ),

        xsens_launch,
        uwb_launch,
        ekf_launch,
    ])
```

After running the robot, the data from the sensors is published to their own topics:

- IMU: topic `/imu/data`  
  Message type: `sensor_msgs/msg/Imu`
- UWB: topic `/dwm1001/id_DW878F/pose`  
  Message type: `geometry_msgs/msg/PoseWithCovarianceStamped`

#### Compile and source workspace

```bash
cd ~/ros2_ws
colcon build --symlink-install
source ~/ros2_ws/install/setup.bash
```

---

## 3. Robot_localization Package

`robot_localization` is a collection of state estimation nodes, each of which implements a nonlinear state estimator for robots moving in 3D space. In this setup, it replaces the simple wheel‑based odometry with a dual‑EKF configuration that follows ROS best practices for multi‑sensor localization.

### 3.1 Installation

To install the package for ROS 2, run:

```bash
sudo apt update
sudo apt install ros-${ROS_DISTRO}-robot-localization
```

Next, a dedicated localization package is created for easier configuration:

```bash
cd ~/ros2_ws/src/
ros2 pkg create --build-type ament_cmake sebot_localization
```

### 3.2 Configuration (params file)

```bash
cd ~/ros2_ws/src/sebot_localization/config/
touch ekf_dual.yaml
```

Add the following configuration to the YAML file:

```yaml
ekf_filter_node_local:
  ros__parameters:
    frequency: 30.0
    sensor_timeout: 0.1
    two_d_mode: true
    publish_tf: true
    map_frame: map
    odom_frame: odom
    base_link_frame: base_footprint
    world_frame: odom

    odom0: wheel/odom
    odom0_config: [false, false, false,
                  false, false, false,
                  true,  true,  false,
                  false, false, true,
                  false, false, false]

    imu0: imu/data
    imu0_config: [false, false, false,
                  false, false,  true,
                  false, false, false,
                  false, false,  true,
                  false, false, false]
    process_noise_covariance: []
    initial_estimate_covariance: []

ekf_filter_node_global:
  ros__parameters:
    frequency: 30.0
    sensor_timeout: 0.1
    two_d_mode: true
    publish_tf: true
    map_frame: map
    odom_frame: odom
    base_link_frame: base_footprint
    world_frame: map

    odom0: wheel/odom
    odom0_config: [false, false, false,
                  false, false, false,
                  true,  true,  false,
                  false, false, true,
                  false, false, false]

    odom1: odometry/uwb_data
    odom1_config: [true, true, false,
                  false, false, false,
                  false, false, false,
                  false, false, false,
                  false, false, false]
    odom1_pose_rejection_threshold: 3.0

    imu0: imu/data
    imu0_config: [false, false, false,
                  false, false, true,
                  false, false, false,
                  false, false, true,
                  false, false, false]
    process_noise_covariance: []
    initial_estimate_covariance: []
```

Each parameter should be adjusted according to the specific robot and sensor configuration, especially `process_noise_covariance` and `initial_estimate_covariance`, to achieve better localization performance. The official documentation and parameter explanation for `robot_localization` can be found in the repository:  
<https://github.com/cra-ros-pkg/robot_localization>

#### Disable TF of wheel_odom node

The simple wheel‑based odometry node in the `diffdrive` package is kept only for reading raw wheel‑tick data and converting it into a basic `Odometry` message. The higher‑level state estimation and `map -> odom -> base_link` transforms are instead handled by the `robot_localization` package, which is the ROS standard solution for multi‑sensor fusion (e.g., wheel encoders, IMU, and UWB). Therefore, disable the `tf_broadcaster` in the odom node to avoid the TF conflict between it and robot_localization estimate node. This approach provides a more robust, consistent, and configurable localization pipeline that can properly integrate noisy or intermittent sensor data.

#### Understanding Covariance Tuning

To achieve optimal results, the process noise covariance must be tuned. This matrix represents the uncertainty in the robot’s motion model.

- Lower values on the diagonal (e.g., 1e‑5) indicate that the EKF trusts the predicted motion more, which results in smoother but slower‑to‑correct behavior.
- Higher values (e.g., 1e‑2) make the EKF more reactive to sensor measurements such as UWB, which is useful for quick corrections but can introduce jitter if the sensor data is noisy.

##### Sensor Configuration Logic

- **IMU:** Only yaw and angular velocity are fused in the EKF. Roll and pitch are disabled because they are generally unnecessary for 2D ground robots and can introduce noise.
- **UWB:** Only X and Y positions are used. Since UWB typically does not provide reliable orientation estimates, the IMU is responsible for yaw, while UWB corrects the global position.

### 3.3 Transformation Between Frames

In a multi‑sensor system, each sensor operates in its own local frame. For the EKF to mathematically fuse the UWB measurements, all data must be expressed in a unified global frame, typically the `map` frame.

#### How the Transformation is Implemented

The transformation from the UWB frame into the `map` frame is handled by a custom ROS 2 node called `UwbTransformNode`. The implementation is available in the file:

`~/ros2_ws/src/sebot_localization/src/uwb_transform_dual_ekf.cpp`

This node:

- subscribes to:
  - the UWB pose topic (`/dwm1001/id_DW878F/pose`),
  - and the IMU topic (`imu/data`);

- uses a short history of IMU messages to interpolate the robot’s yaw at the UWB timestamp;

- computes an initial datum using the first `sample_threshold_` UWB position and averaged IMU yaw;

- applies the static offset between the UWB tag and the robot’s base link (defined in TF as `uwb_link` → `base_link`) in the robot’s current orientation;  

- then rotates and translates the UWB position into the `map` frame using the stored `pos0_uwb_` and `yaw0_`;

- finally publishes the result as an `Odometry` message on the topic `odometry/uwb_data`, with realistic covariance values for x, y, z, and orientation.

Because the transformation logic and parameters are already encapsulated in the node, the YAML configuration for the global EKF only needs to enable x and y from `odometry/uwb_data` and let the node handle the frame‑alignment details.

### 3.4 Last Step: Packaging and Launching

The C++ implementation for the EKF and UWB transformation nodes is grouped into a single package `sebot_localization`. The package metadata and dependencies are defined in `package.xml` and `CMakeLists.txt`.

**`~/ros2_ws/src/sebot_localization/package.xml`**

```xml
<?xml version="1.0"?>
<?xml-model href="http://download.ros.org/schema/package_format3.xsd" schematypens="http://www.w3.org/2001/XMLSchema"?>
<package format="3">
  <name>sebot_localization</name>
  <version>0.0.0</version>
  <description>Localization package for dual EKF fusion with IMU, wheel odometry, UWB, and LiDAR.</description>
  <maintainer email="ros2@todo.todo">ros2</maintainer>
  <license>TODO: License declaration</license>

  <buildtool_depend>ament_cmake</buildtool_depend>
  <test_depend>ament_lint_auto</test_depend>
  <test_depend>ament_lint_common</test_depend>

  <depend>rclcpp</depend>
  <depend>std_msgs</depend>
  <depend>sensor_msgs</depend>
  <depend>nav_msgs</depend>
  <depend>geometry_msgs</depend>
  <depend>tf2</depend>
  <depend>tf2_ros</depend>
  <depend>tf2_geometry_msgs</depend>

  <export>
    <build_type>ament_cmake</build_type>
  </export>
</package>
```

**`~/ros2_ws/src/sebot_localization/CMakeLists.txt`**

```txt
cmake_minimum_required(VERSION 3.8)
project(sebot_localization)

if(CMAKE_COMPILER_IS_GNUCXX OR CMAKE_CXX_COMPILER_ID MATCHES "Clang")
  add_compile_options(-Wall -Wextra -Wpedantic)
endif()

find_package(ament_cmake REQUIRED)
find_package(Eigen3 REQUIRED)
find_package(rclcpp REQUIRED)
find_package(std_msgs REQUIRED)
find_package(sensor_msgs REQUIRED)
find_package(nav_msgs REQUIRED)
find_package(geometry_msgs REQUIRED)
find_package(tf2 REQUIRED)
find_package(tf2_ros REQUIRED)
find_package(tf2_geometry_msgs REQUIRED)

include_directories(include)

add_executable(ekf_node src/ekf_node.cpp)
target_include_directories(ekf_node PRIVATE
  $<BUILD_INTERFACE:${CMAKE_CURRENT_SOURCE_DIR}/include>
  ${Eigen3_INCLUDE_DIRS}
)
ament_target_dependencies(ekf_node
  rclcpp sensor_msgs nav_msgs geometry_msgs std_msgs tf2 tf2_ros tf2_geometry_msgs
)
target_link_libraries(ekf_node Eigen3::Eigen)

add_executable(uwb_transform_node src/uwb_transform.cpp)
target_include_directories(uwb_transform_node PRIVATE
  $<BUILD_INTERFACE:${CMAKE_CURRENT_SOURCE_DIR}/include>
  ${Eigen3_INCLUDE_DIRS}
)
ament_target_dependencies(uwb_transform_node
  rclcpp sensor_msgs nav_msgs geometry_msgs std_msgs tf2 tf2_ros tf2_geometry_msgs
)
target_link_libraries(uwb_transform_node Eigen3::Eigen)

add_executable(uwb_transform_dual_ekf_node src/uwb_transform_dual_ekf.cpp)
target_include_directories(uwb_transform_dual_ekf_node PRIVATE
  $<BUILD_INTERFACE:${CMAKE_CURRENT_SOURCE_DIR}/include>
  ${Eigen3_INCLUDE_DIRS}
)
ament_target_dependencies(uwb_transform_dual_ekf_node
  rclcpp sensor_msgs nav_msgs geometry_msgs std_msgs tf2 tf2_ros tf2_geometry_msgs
)
target_link_libraries(uwb_transform_dual_ekf_node Eigen3::Eigen)

install(TARGETS
  ekf_node
  uwb_transform_node
  uwb_transform_dual_ekf_node
  DESTINATION lib/${PROJECT_NAME}
)

install(
  DIRECTORY launch config
  DESTINATION share/${PROJECT_NAME}
)

if(BUILD_TESTING)
  find_package(ament_lint_auto REQUIRED)
  set(ament_cmake_copyright_FOUND TRUE)
  set(ament_cmake_cpplint_FOUND TRUE)
  ament_lint_auto_find_test_dependencies()
endif()

ament_package()
```

The EKF nodes are launched via the configuration defined in the shared YAML file and the launch script below:

```bash
cd ~/ros2_ws/src/sebot_localization/
mkdir launch
touch ekf_dual.launch.py
```

```python
from launch import LaunchDescription
from launch_ros.actions import Node
from launch.actions import DeclareLaunchArgument
from launch.substitutions import LaunchConfiguration
from ament_index_python.packages import get_package_share_directory
import os

def generate_launch_description():
    pkg_name = 'sebot_localization'

    robot_localization_dir = get_package_share_directory(pkg_name)
    parameters_file_dir = os.path.join(robot_localization_dir, 'config')
    parameters_file_path = os.path.join(parameters_file_dir, 'ekf_dual.yaml')
    print(parameters_file_path)
    os.environ['FILE_PATH'] = str(parameters_file_dir)

    use_sim_time = LaunchConfiguration('use_sim_time')

    return LaunchDescription([
        DeclareLaunchArgument(
            'use_sim_time',
            default_value='false',
            description='Use simulation clock'),

        Node(
            package='tf2_ros',
            executable='static_transform_publisher',
            name='static_transform_publisher_uwb_to_base_link',
            output='screen',
            arguments=['0', '-0.05', '0', '0', '0', '0', 'base_link', 'uwb_link']
        ),

        Node(
            package='robot_localization',
            executable='ekf_node',
            name='ekf_filter_node_local',
            output='screen',
            parameters=[parameters_file_path, {'use_sim_time': use_sim_time}],
            remappings=[('odometry/filtered', 'odometry/filtered/local')]
        ),

        Node(
            package='robot_localization',
            executable='ekf_node',
            name='ekf_filter_node_global',
            output='screen',
            parameters=[parameters_file_path, {'use_sim_time': use_sim_time}]
        )

```

Dual EKF architecture
<p>
  <em>Figure 1. Integration of UWB computation in ROS 2 according to Moore’s (2016) model (Mäkelä 2024)</em>
</p>

The localization strategy uses a Dual-EKF architecture to separate smooth local motion from global positioning accuracy.

The Local EKF (Odom Frame) fuses high-frequency data from the IMU and Wheel Encoders. Its primary role is to produce a jitter-free, continuous stream of odometry (50Hz–100Hz) for immediate motion control. While this frame stays smooth for local maneuvers, it naturally drifts over time because it lacks an external reference.

The Global EKF (Map Frame) acts as the system's error corrector. It fuses the same data as local EKF together with absolute global references UWB. Its objective is to calculate the transform between the map -> odom frames to eliminate accumulated drift.

##### Compile and source workspace

```bash
cd ~/ros2_ws
colcon build --symlink-install
source ~/ros2_ws/install/setup.bash
ros2 launch diffdrive diffdrive.launch.py
```

There is a data file obtained by using this system, you can take a look at how the EKF helped to correct the drifts over time with only wheel encoders by executing commands:

```bash
# Open the first terminal
# Replay the bag data file with rosbag
ros2 bag play ~/ros2?ws/data_ekf/rosbag2_2026_03_02-02_11_23 --topic wheel/odom odometry/uwb_data odometry/filtered/local odometry/filtered/global

# Open the second terminal
source ~/ros2_ws/install/setup.bash
ros2 run diffdrive plot
```

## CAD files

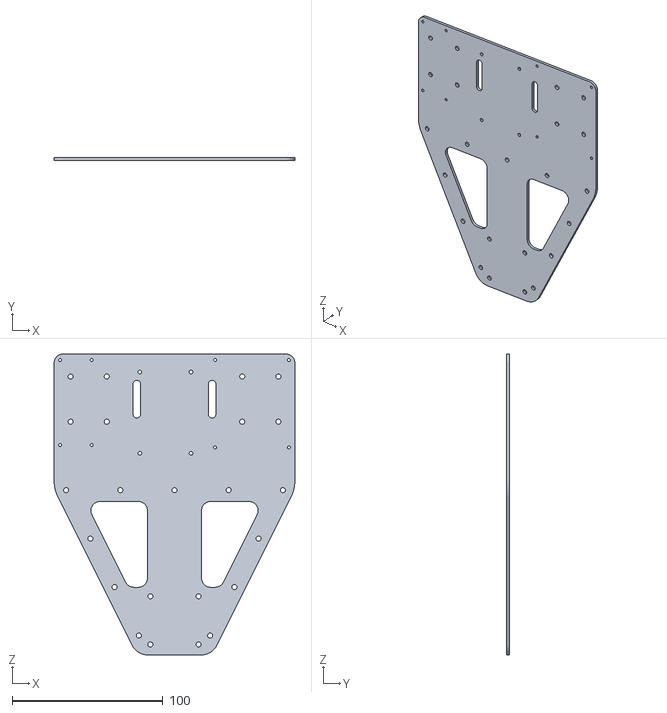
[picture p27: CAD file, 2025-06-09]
code/ros2_ws/config/SeBot/SeBot.stl
160.0 x 2.00 x 200.0

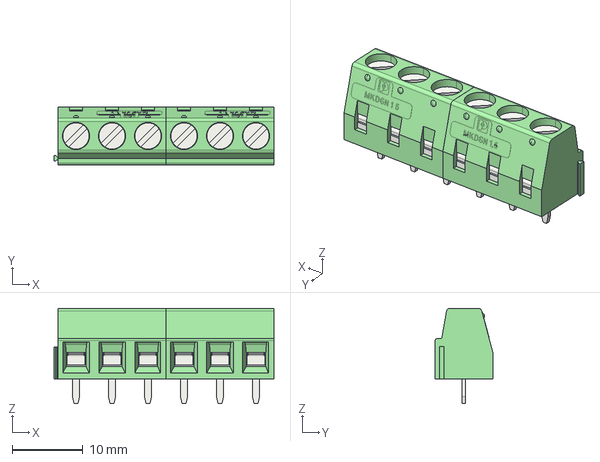
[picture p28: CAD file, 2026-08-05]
hardware/3d models/1729160.stp
31.0 x 8.15 x 13.5 mm

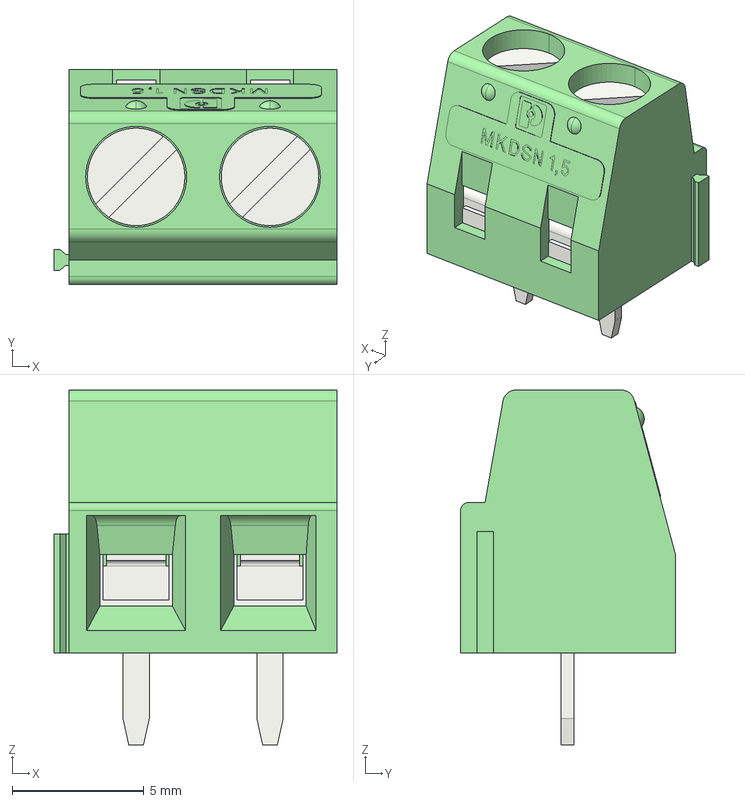
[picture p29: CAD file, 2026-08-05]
hardware/3d models/1729128.stp
10.7 x 8.15 x 13.5 mm

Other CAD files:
SeBot malli/SeBot alusta V6.stp
SeBot malli/SeBot alusta V6.ipt

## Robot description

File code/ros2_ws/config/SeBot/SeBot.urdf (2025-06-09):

<?xml version="1.0"?>
<robot name="triangle_bot">
  <!-- Base plate -->
  <link name="base_link">
    <visual>
      <geometry>
         <mesh filename="./SeBot.stl" scale="1 1 1"/>
      </geometry>
      <origin xyz="0 0 0.005" rpy="0 1.5708 0"/>
      <material name="grey">
        <color rgba="0.6 0.6 0.6 1.0"/>
      </material>
    </visual>
    <collision>
      <geometry>
        <box size="0.3 0.3 0.01"/>
      </geometry>
    </collision>
    <inertial>
      <mass value="1.0"/>
      <inertia ixx="0.01" ixy="0.0" ixz="0.0" iyy="0.01" iyz="0.0" izz="0.01"/>
    </inertial>
  </link>

  <!-- Left wheel -->
  <link name="left_wheel">
    <visual>
      <geometry>
        <cylinder radius="0.035" length="0.02"/>
      </geometry>
      <origin xyz="0 0.12 0.035" rpy="1.5708 0 0"/>
      <material name="black">
        <color rgba="0.1 0.1 0.1 1"/>
      </material>
    </visual>
  </link>

  <joint name="left_wheel_joint" type="continuous">
    <parent link="base_link"/>
    <child link="left_wheel"/>
    <origin xyz="0 0.12 0.035" rpy="0 0 0"/>
    <axis xyz="0 1 0"/>
  </joint>

  <!-- Right wheel -->
  <link name="right_wheel">
    <visual>
      <geometry>
        <cylinder radius="0.035" length="0.02"/>
      </geometry>
      <origin xyz="0 -0.12 0.035" rpy="1.5708 0 0"/>
      <material name="black"/>
    </visual>
  </link>

  <joint name="right_wheel_joint" type="continuous">
    <parent link="base_link"/>
    <child link="right_wheel"/>
    <origin xyz="0 -0.12 0.035" rpy="0 0 0"/>
    <axis xyz="0 1 0"/>
  </joint>

  <!-- Left motor -->
  <link name="left_motor">
    <visual>
      <geometry>
        <cylinder radius="0.02" length="0.04"/>
      </geometry>
      <origin xyz="0.02 0.12 0.035" rpy="1.5708 0 0"/>
      <material name="blue">
        <color rgba="0 0 1 1"/>
      </material>
    </visual>
  </link>

  <joint name="left_motor_joint" type="fixed">
    <parent link="base_link"/>
    <child link="left_motor"/>
    <origin xyz="0.02 0.12 0.035" rpy="0 0 0"/>
  </joint>

  <!-- Right motor -->
  <link name="right_motor">
    <visual>
      <geometry>
        <cylinder radius="0.02" length="0.04"/>
      </geometry>
      <origin xyz="0.02 -0.12 0.035" rpy="1.5708 0 0"/>
      <material name="blue"/>
    </visual>
  </link>

  <joint name="right_motor_joint" type="fixed">
    <parent link="base_link"/>
    <child link="right_motor"/>
    <origin xyz="0.02 -0.12 0.035" rpy="0 0 0"/>
  </joint>

  <!-- Caster wheel -->
  <link name="caster_wheel">
    <visual>
      <geometry>
        <sphere radius="0.015"/>
      </geometry>
      <origin xyz="0.15 0 0.015" rpy="0 0 0"/>
      <material name="grey"/>
    </visual>
  </link>

  <joint name="caster_joint" type="continuous">
    <parent link="base_link"/>
    <child link="caster_wheel"/>
    <origin xyz="0.15 0 0.015" rpy="0 0 0"/>
    <axis xyz="0 0 1"/>
  </joint>

</robot>

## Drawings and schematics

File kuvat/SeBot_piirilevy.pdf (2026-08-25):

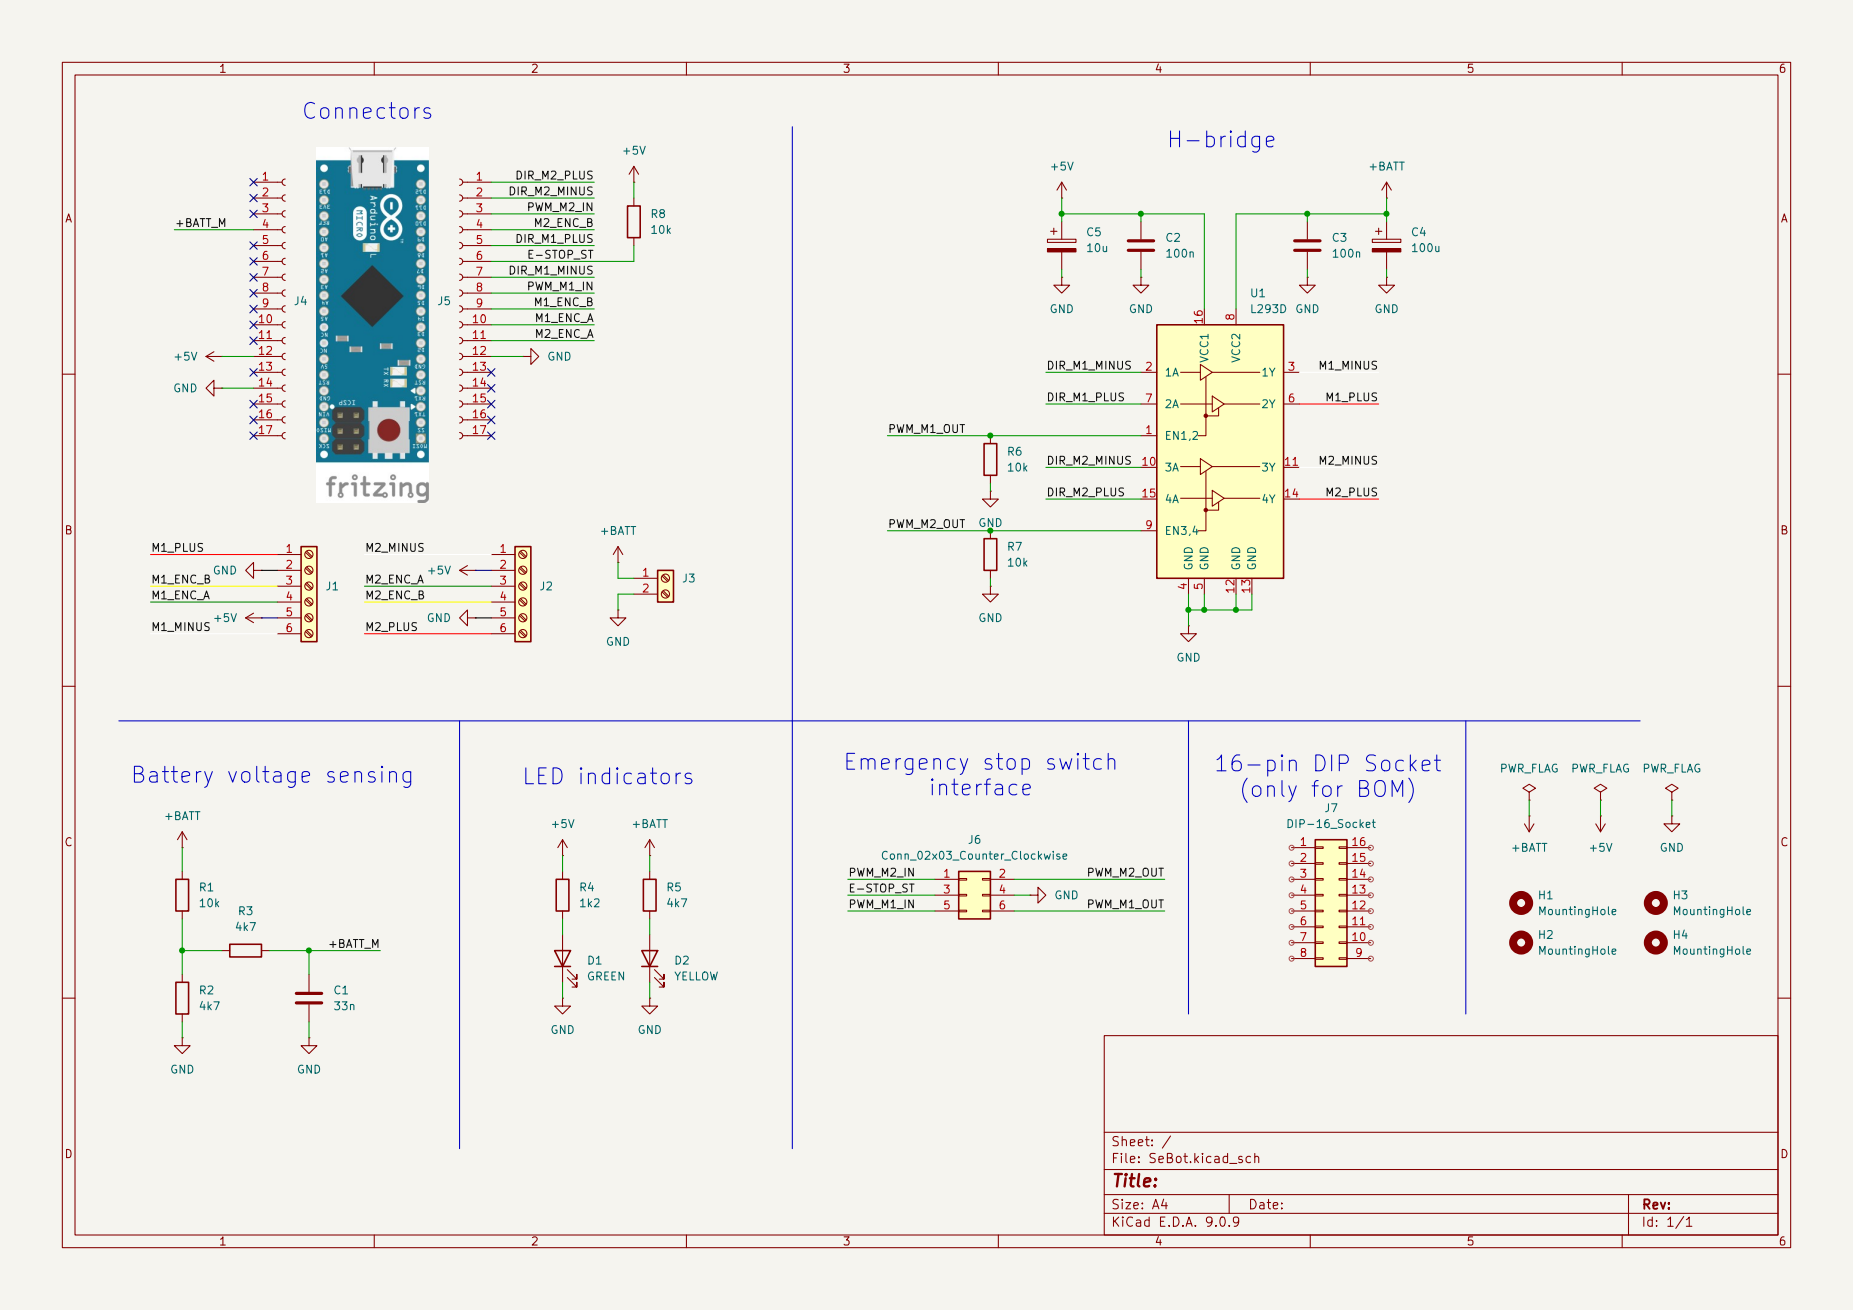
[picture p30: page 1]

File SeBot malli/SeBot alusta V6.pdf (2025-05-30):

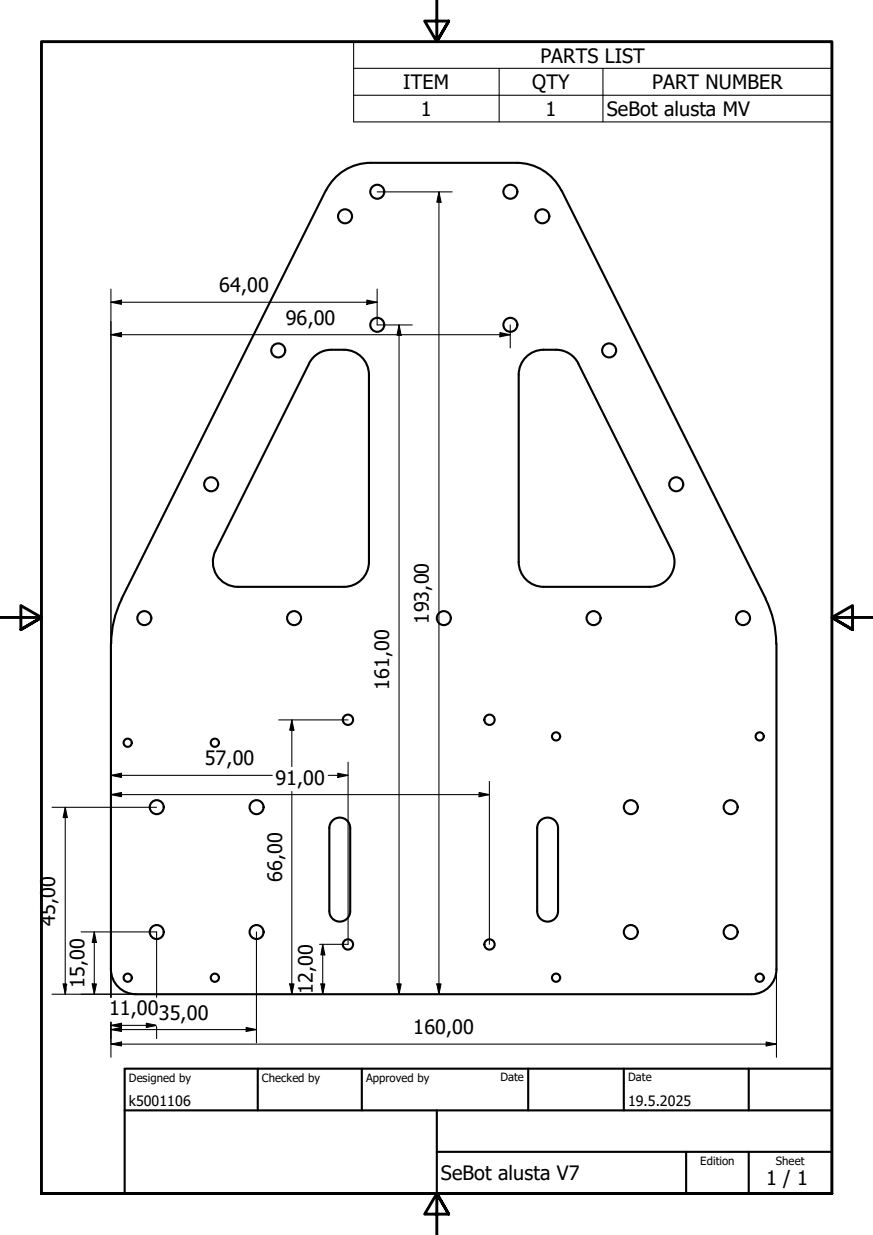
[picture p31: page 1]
SeBot alusta V7; Designed by; Checked by; Approved by; Date

PARTS LIST

ITEM | QTY | PART NUMBER
1 | 1 | SeBot alusta MV

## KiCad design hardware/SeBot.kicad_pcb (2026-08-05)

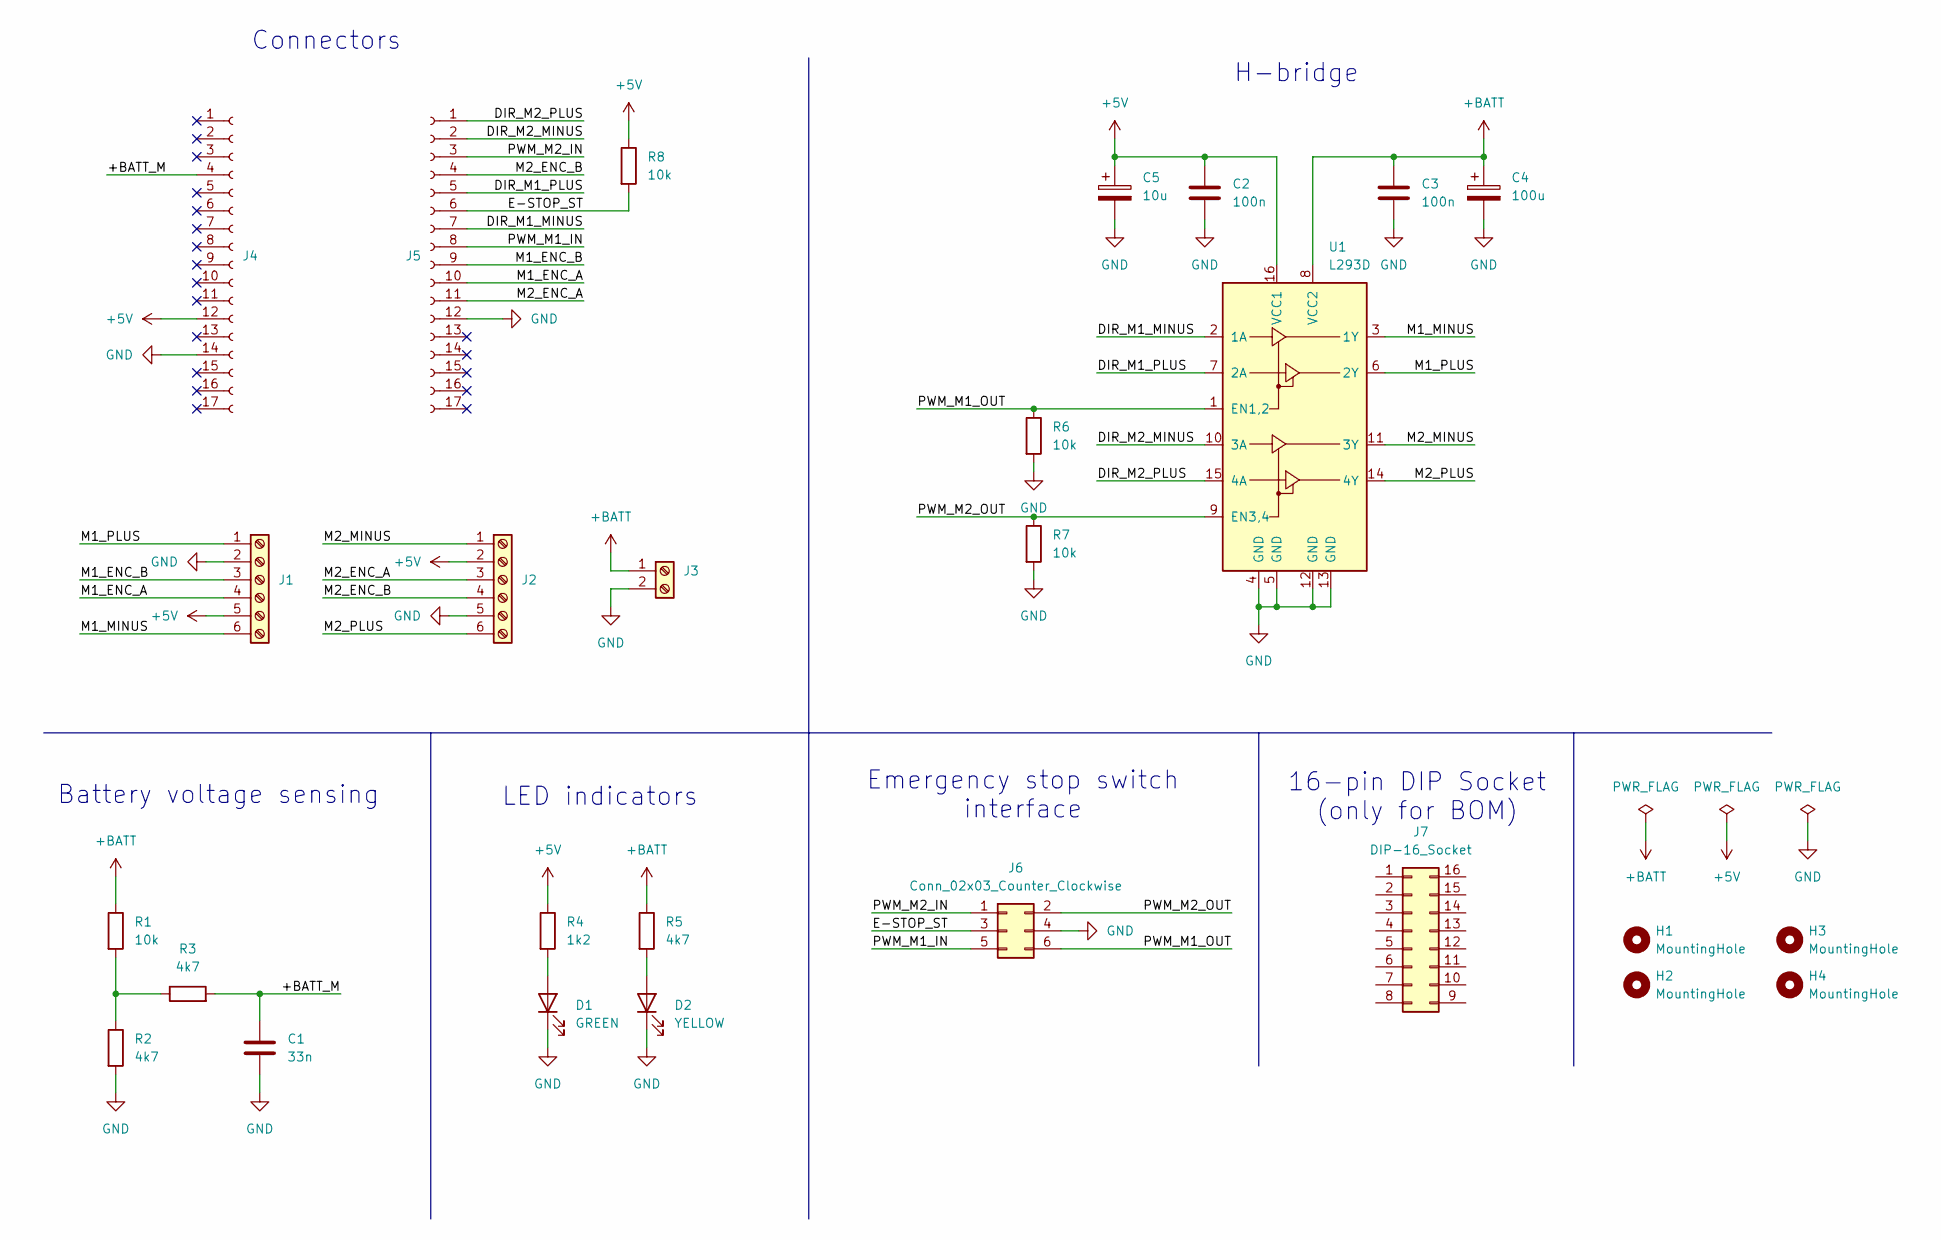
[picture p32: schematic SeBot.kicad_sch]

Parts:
C1: 33n; C_Disc_D3.8mm_W2.6mm_P2.50mm; Manufacturer Part No. K333K15X7RF5TL2; Farnell Part No. 3812207
C2, C3: 100n; C_Disc_D3.8mm_W2.6mm_P2.50mm; Manufacturer Part No. K104K15X7RF5TL2; Farnell Part No. 2860097
C4: 100u; CP_Radial_D6.3mm_P2.50mm; Manufacturer Part No. ECA1VM101; Farnell Part No. 9693670
C5: 10u; CP_Radial_D5.0mm_P2.00mm; Manufacturer Part No. ECA1JM100; Farnell Part No. 9693831
D1: GREEN; LED_D5.0mm; Manufacturer Part No. N/A; Farnell Part No. N/A
D2: YELLOW; LED_D5.0mm; Manufacturer Part No. N/A; Farnell Part No. N/A
H1, H2, H3, H4: MountingHole; MountingHole_3mm
J1, J2: Screw_Terminal_01x06; TerminalBlock_Phoenix_MKDSN-1,5-6-5.08_1x06_P5.08mm_Horizon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; Manufacturer Part No. 1729160; Farnell Part No. 3041499
J3: Screw_Terminal_01x02; TerminalBlock_Phoenix_MKDSN-1,5-2-5.08_1x02_P5.08mm_Horizon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; Manufacturer Part No. 1729128; Farnell Part No. 3041440
J4, J5: Conn_01x17_Socket; PinSocket_1x17_P2.54mm_Vertical; Manufacturer Part No. M20-7821746; Farnell Part No. 3755878
J6: Conn_02x03_Counter_Clockwise; PinHeader_2x03_P2.54mm_Vertical; Manufacturer Part No. 2213S-06G; Farnell Part No. 1593440
J7: DIP-16_Socket; Manufacturer Part No. 1-2199298-4; Farnell Part No. 1-2199298-4
R1, R6, R7, R8: 10k; R_Axial_DIN0207_L6.3mm_D2.5mm_P7.62mm_Horizontal; Manufacturer Part No. N/A; Farnell Part No. N/A
R2, R3, R5: 4k7; R_Axial_DIN0207_L6.3mm_D2.5mm_P7.62mm_Horizontal; Manufacturer Part No. N/A; Farnell Part No. N/A
R4: 1k2; R_Axial_DIN0207_L6.3mm_D2.5mm_P7.62mm_Horizontal; Manufacturer Part No. N/A; Farnell Part No. N/A
U1: L293D; DIP-16_W7.62mm_Socket; Manufacturer Part No. L293D; DigiKey Part No. 497-2936-5-ND

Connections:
+5V: C2.1, C5.1, J1.5, J2.2, J4.12, R4.1, R8.1, U1.16 (VCC1)
+BATT: C3.1, C4.1, J3.1, R1.1, R5.1, U1.8 (VCC2)
/+BATT_M: C1.1, J4.4, R3.2
/DIR_M1_MINUS: J5.7, U1.2 (1A)
/DIR_M1_PLUS: J5.5, U1.7 (2A)
/DIR_M2_MINUS: J5.2, U1.10 (3A)
/DIR_M2_PLUS: J5.1, U1.15 (4A)
/E-STOP_ST: J5.6, J6.3, R8.2
/M1_ENC_A: J1.4, J5.10
/M1_ENC_B: J1.3, J5.9
/M1_MINUS: J1.6, U1.3 (1Y)
/M1_PLUS: J1.1, U1.6 (2Y)
/M2_ENC_A: J2.3, J5.11
/M2_ENC_B: J2.4, J5.4
/M2_MINUS: J2.1, U1.11 (3Y)
/M2_PLUS: J2.6, U1.14 (4Y)
/PWM_M1_IN: J5.8, J6.5
/PWM_M1_OUT: J6.6, R6.1, U1.1 (EN1,2)
/PWM_M2_IN: J5.3, J6.1
/PWM_M2_OUT: J6.2, R7.1, U1.9 (EN3,4)
GND: C1.2, C2.2, C3.2, C4.2, C5.2, D1.1 (K), D2.1 (K), J1.2, J2.5, J3.2, J4.14, J5.12, J6.4, R2.2, R6.2, R7.2, U1.4 (GND), U1.5 (GND), U1.12 (GND), U1.13 (GND)
unnamed: D1.2 (A), R4.2
unnamed: D2.2 (A), R5.2
unnamed: R1.2, R2.1, R3.1

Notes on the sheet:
16-pin DIP Socket (only for BOM)
Battery voltage sensing
Connectors
Emergency stop switch interface
H-bridge
LED indicators

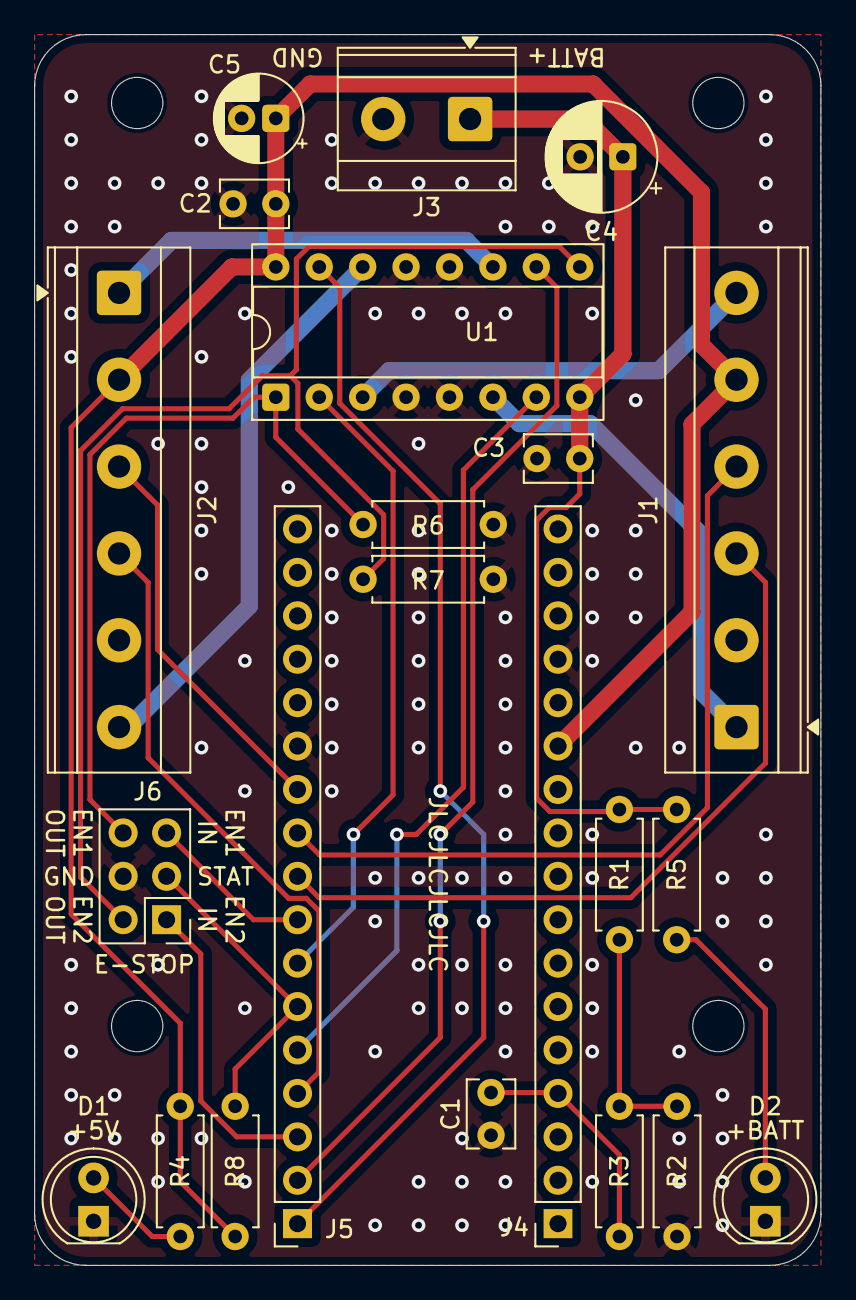
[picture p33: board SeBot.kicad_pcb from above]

Board: 2 copper layers, 46.0 x 72.0 mm, 26 parts (0 on the bottom side), 24 nets.

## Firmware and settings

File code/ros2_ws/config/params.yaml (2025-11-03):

motordriver_node:
  ros__parameters:
    simulation: True
odom_node:
  ros__parameters:
    wheel_radius: 0.0345
    wheel_base: 0.212
    ticks_per_revolution: 1000
cmd_vel_node:
  ros__parameters:
    wheel_radius: 0.0345
    wheel_base: 0.212
    ticks_per_revolution: 1000
battery_alert_node:
  ros__parameters:
    threshold: 10.5
battery_republish_node:
  ros__parameters:
    battery_check_interval: 5.0

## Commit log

2025-05-27 Alkuperäinen commit ensimmäisestä julkaisusta SeBotille.
    [robot.urdf]
2025-05-27 Update materiaali-2-motordriver.md
    Muutettiin teksti kannustamaan namespacen sijaan ROS_DOMAIN_ID:n vaihtamiseen.
2025-05-27 Update materiaali-3-URDF.md
    Lisätty kommenttirivit namespace-lisäysten kohdille
2025-05-27 Update materiaali-2-motordriver.md
    Kirjoitusvirheiden poistoa
2025-05-30 SeBot alustan malli, lisäyksiä
    [SeBot alusta V6.ipt, SeBot alusta V6.stp]
2025-06-05 Arduinon koodin akun jänniteseurantaversiot
2025-06-05 battery paketin hakemiston korjaus
2025-06-05 Päivitetty materiaali bugikorjauksien jäljiltä
    [battery_alert.py, battery_republish.py, motorcontroller_battery.ino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]
2025-06-09 SeBot urdf
    [SeBot.stl, SeBot.urdf]
2025-11-03 Fix calculation of left and right wheel speeds
    [cmd_vel.py]
2026-08-05 Uuden piirilevyn selostus päivitetty ja tiedostot lisätty.
    [1729128.stp, 1729160.stp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]
2026-09-09 Fix ROS2 motor command topic examples (namespace pois sekaamasta)
    Updated ROS2 topic command examples to remove namespace placeholder.
